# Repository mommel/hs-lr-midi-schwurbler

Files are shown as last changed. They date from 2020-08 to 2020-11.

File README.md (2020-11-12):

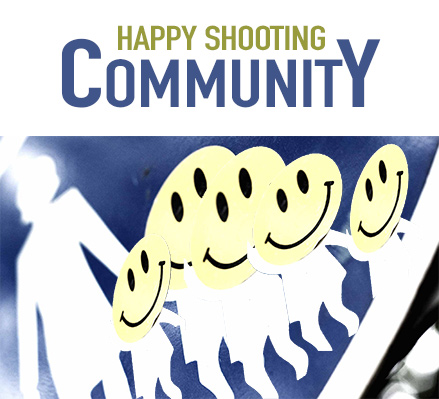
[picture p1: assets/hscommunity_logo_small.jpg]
HSCommunity Logo

# Der Schwurbler



Happy Shooting Community - DIY Lightroom Hardware Controller
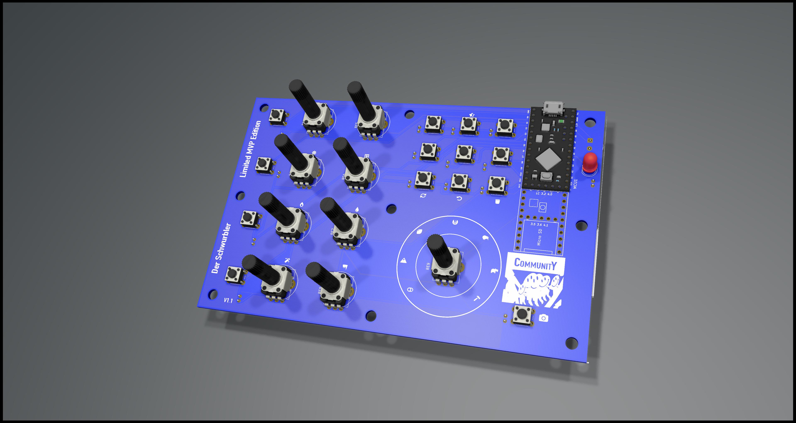
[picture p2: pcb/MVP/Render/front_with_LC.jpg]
Render with Parts


## Description
The german foto podcast legend Happy Shooting had a discussion about Midi controller for Lightroom. One comment on the website and voila a new project is born.
This project will (hopefully) contain everything from zero to hero to get create your own customized Midi Controller for Lightroom.
It is completly community driven, so everyone is allowed to contribute. And it's not intended to earn money with it. Just from the community for the community.
In general you might even need no case, just the pcb with the solded parts. so you will get an extra small extra lightwight device. If that's the thing for you we might even go the capacitive way and reduce the soldered components and weight to a minimum.

## MVP Video

<object width="425" height="350">
  <param name="movie" value="https://youtu.be/SjJDIjGQ-qA" />
  <param name="wmode" value="transparent" />
  <embed src="https://youtu.be/SjJDIjGQ-qA"
         type="application/x-shockwave-flash"
         wmode="transparent" width="425" height="350" />
</object>

https://youtu.be/SjJDIjGQ-qA

## WIKI
You can find our wiki here https://github.com/mommel/hs-lr-midi-schwurbler/wiki

## Status of the project
Released a version and onging development for next versions

### Tutorial
 *To be found soonish in the Wiki*

## Versions
### MVP 
* based on Teensy 32bit boards
* USB Powered
* 10 + 4 Buttons
* 9 Poti

[BOM](https://hs-lr-midi-schwurbler.mommel.com/bom/schwurbler-mvp-1.2.ibom.html)

## Releases
* [MVP Version](https://github.com/mommel/hs-lr-midi-schwurbler/releases/tag/v1.0.0) released

## Help needed? F.A.Q.
* For support you can open an issue here on github.
* Maybe there will be a slack contact in the future.
* This project is a Happy Shooting _Community_ Project. 
The best way to get help is joining the #der-schwurbler channel on the happyshooting slack. The community will do it's best and hopefully solve your issue.
* No hotline, no helpdesk. But we have something even greater: The Happy Shooting _Community_.    

## How to contribute
* Fork, add, push, create a pull request
* create an issue on github
* You don't want to use Eagle, Kicad or Fritzing to create a layout. It's totally fine, as long the result can be used to create a PCB with no additional costs to the version created with the other software.

## How can I get one?
* Decide the version, take the Gerber Folder and bom.csv matching your decission. Upload the gerber Files to the manufacturer of your most trust. Mine are some even in china and even there is the delivery time below a week.

## License
* All layouts and diagrams are CC share alike non commercial attribution 4.0 licensed
So you can create and use them on your own even in your company, but you are not allowed to sell them.

<br />Dieses Werk ist lizenziert unter einer <a rel="license" href="http://creativecommons.org/licenses/by-nc-sa/4.0/">Creative Commons Namensnennung - Nicht-kommerziell - Weitergabe unter gleichen Bedingungen 4.0 International Lizenz</a>.
Namensnennung/Attribution to Happy Shooting Community https://happyshooting.de/community-projekte/

### Contributors in alphabetical order
chrismarquardt https://github.com/chrismarquardt
Mac ThreeZee https://github.com/MacThreeZee
Mommel https://github.com/mommel
Vielpixel https://github.com/Vielpixel
wolfgangSF https://github.com/wolfgangSF

### 3rd Party
Tools or Assets from 3rd party have their own LICENSE attached to their folder

## Disclaimer
THE SOFTWARE IS PROVIDED "AS IS", WITHOUT WARRANTY OF ANY KIND, EXPRESS OR IMPLIED, INCLUDING BUT NOT LIMITED TO THE WARRANTIES OF MERCHANTABILITY, FITNESS FOR A PARTICULAR PURPOSE AND NONINFRINGEMENT. IN NO EVENT SHALL THE AUTHORS OR COPYRIGHT HOLDERS BE LIABLE FOR ANY CLAIM, DAMAGES OR OTHER LIABILITY, WHETHER IN AN ACTION OF CONTRACT, TORT OR OTHERWISE, ARISING FROM, OUT OF OR IN CONNECTION WITH THE SOFTWARE OR THE USE OR OTHER DEALINGS IN THE SOFTWARE.

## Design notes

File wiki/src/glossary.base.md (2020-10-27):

<!---------------------------->
<!-- multilangual suffix: en, de  -->
<!---------------------------->
<!-- [en] -->
# Glossary
<!-- [de] -->
# Glossar
<!-- [common] -->

## BOM
<!-- [en] -->
Bill of materials, it is more or less the list which items you need to create a board
<!-- [de] -->
Eine Auflistung der benötigten Bauteile 
<!-- [common] -->

## MCU
<!-- [en] -->
The mcu is shorthand for microcontroller unit. When we speak of the mcu, we mostly mean a dev board. 
* Teensy is a dev board. 
* Esp32 is the chip itself but we mostly use it as synonym for the devboards with esp32-wroom chip like (TTGO, NodeMCU ESP32, ...)
<!-- [de] -->
Eigentlich der Mikrokontroller, aber wir verwenden der Einfachheit halber den Begriff für das jeweilige Entwicklerplatine (Devboard). Da wir im aktuellen Prozess immer ein Devboard nutzen werden. 
* Der Teensy ist ein Devboard. 
* Der Esp32 hingegen ist bezeichnet eigentlich den Chip aber wir nutzen ihn als Synonym für ein Devboard mit esp32-wroom Chip z.B. dem TTGO oder dem NodeMCU ESP32
<!-- [common] -->

## Midi2LR
<!-- [en] -->
MIDI2LR is a software application to translate the Schwurbler input to Lightroom actions.   
[https://github.com/rsjaffe/MIDI2LR](https://github.com/rsjaffe/MIDI2LR)
<!-- [de] -->
MIDI2LR ist eine Software-Anwendung zur Übersetzung der Schwurbler-Eingabe in Lightroom-Aktionen.   
[https://github.com/rsjaffe/MIDI2LR](https://github.com/rsjaffe/MIDI2LR)
<!-- [common] -->

## MVP
<!-- [en] -->
Minimal Valuable Product - This is a first working prototype.
<!-- [de] -->
Minimal Valuable Product - 
Es handelt sich um einen ersten funktionsfähigen Prototyp. 
<!-- [common] -->

## PCB
<!-- [en] -->
It is a Printed Circuit Board. The board where everything gets soldered onto. We use only through the hole soldering items to keep it beginner save. At least for the first board designs. You might want to have a look in this nice [guide how to solder right by Mitch Altmann, Andie Nordgren and Jeff Keyzer from mightyohm.com](http://mightyohm.com/files/soldercomic/FullSolderComic_EN.pdf)
<!-- [de] -->
Die Leiterplatte auf der wir alle Bauteile im verlöten werden. Hierbei werden wir ( zumindest in den ersten Versionen) Durchsteckbauelemente verwenden, da das SMD Löten für Anfänger nicht gerade Ideal ist. 
Als Lötneuling möchtest du vielleicht mal in diese super [Anleitung wie man richtig lötet (gemacht von Mitch Altmann, Andie Nordgren, Jeff Keyzer, Alexander Bodora und Richard Meinsen zu finden auf der Webseite mightyohm.com)](http://mightyohm.com/files/soldercomic/translations/DE_SolderComic.pdf) schauen
<!-- [common] -->

## Potentiometer
<!-- [en] -->
A potentiometer is an electrical resistance component whose resistance values can be changed mechanically (by turning or shifting). There are linear potentiometers (faders or sliders) and rotary potentiometers.
<!-- [de] -->
Ein Potentiometer (kurz Poti), ist ein elektrisches Widerstandsbauelement, dessen Widerstandswerte mechanisch (durch Drehen oder Verschieben) veränderbar sind. Es gibt Linear Poti (auch Fader oder Schieberegler genannt) und Rotary Poti.
<!-- [common] -->

<!-- [en] -->
## Rotary Encoder
A rotary encoder is a type of position sensor which is used for determining the angular position of a rotating shaft. It generates an electrical signal, either analog or digital, according to the rotational movement. Details can be found here: https://howtomechatronics.com/tutorials/arduino/rotary-encoder-works-use-arduino/
<!-- [de] -->
## Rotary Encoder oder Drehwinkelgeber
Ein Rotary Encoder ist eine Art Positionssensor, der zur Bestimmung der Winkelposition einer rotierenden Welle verwendet wird. Er erzeugt ein elektrisches Signal, entweder analog oder digital, entsprechend der Drehbewegung. Mehr Details gibt's hier: https://howtomechatronics.com/tutorials/arduino/rotary-encoder-works-use-arduino/ 
<!-- [common] -->

## Teensy
<!-- [en] -->
The Teensy is a USB-based microcontroller development system.    
[> PJRC Website](https://www.pjrc.com/teensy/)
<!-- [de] -->
Der Teensy ist ein Development Board mit vielen Funktionen in einem sehr kleinen Paket.    
[> Teensy First Use](https://www.pjrc.com/teensy/first_use.html)   

***
<!-- [de] -->
_[ > English Version](glossary.en.md)_
<!-- [en] -->
_[ > Deutsche Version](glossary.de.md)_

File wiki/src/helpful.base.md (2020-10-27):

<!---------------------------->
<!-- multilangual suffix: en, de  -->
<!---------------------------->

<!-- [en] -->
# Helpful Informations
<!-- [de] -->
# Hilfreiche Informationen
<!-- [common] -->

<!-- [en] -->
## Adobe Lightroom Classic Shortcuts:
[Adobe Lightroom Classic Shortcuts](https://helpx.adobe.com/de/lightroom-classic/help/keyboard-shortcuts.html)
<!-- [de] -->
## Klassische Kurzbefehle für Adobe Lightroom:
[Klassische Kurzbefehle für Adobe Lightroom](https://helpx.adobe.com/de/lightroom-classic/help/keyboard-shortcuts.html)
<!-- [common] -->

<!-- [en] -->
## Sources of supply for the components
<!-- [de] -->
## Bezugsquellen für die Bauteile
<!-- [common] -->
(Deutschland/Europa)
* https://www.reichelt.de
* https://www.antratek.de
* https://www.az-delivery.de
* https://www.conrad.de
* https://www.mouser.de
* https://wittko.eu
* https://eckstein-shop.de

## Midi2LR
[Project Page](https://rsjaffe.github.io/MIDI2LR/)

## Solder Comic
<!-- [en] -->
by Mitch Altmann, Andie Nordgren and Jeff Keyzer 
- [Soldering is easy](http://mightyohm.com/files/soldercomic/FullSolderComic_EN.pdf)
Hosted on mightyohm.com
<!-- [de] -->
von Mitch Altmann, Andie Nordgren, Jeff Keyzer und in deutsch kommen Alexander Bodora und Richard Meinsen en top
- [Löten ist einfach](http://mightyohm.com/files/soldercomic/translations/DE_SolderComic.pdf)
Gehostet auf mightyohm.com
<!-- [common] -->

## Teensy USB Development Board
<!-- [en] -->
The Teensy is a complete USB-based microcontroller development system, in a very small footprint, capable of implementing many types of projects. All programming is done via the USB port.    
[> PJRC Website](https://www.pjrc.com/teensy/)     
[> Teensy First Use](https://www.pjrc.com/teensy/first_use.html)  
<!-- [de] -->
Der Teensy ist ein vollständiges USB-basiertes Mikrocontroller-Entwicklungssystem mit sehr geringem Platzbedarf, das viele Arten von Projekten umsetzen kann. Die gesamte Programmierung erfolgt über den USB-Port.    
[> PJRC Website](https://www.pjrc.com/teensy/)     
[> Teensy First Use](https://www.pjrc.com/teensy/first_use.html)  

***
<!-- [de] -->
_[ > English Version](helpful.en.md)_
<!-- [en] -->
_[ > Deutsche Version](helpful.de.md)_

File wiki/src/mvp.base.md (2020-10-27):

<!---------------------------->
<!-- multilangual suffix: en, de  -->
<!---------------------------->
<!-- [en] -->
# Schwurbler MVP Edition
<!-- [de] -->
# Der Schwurbler MVP Version
<!-- [common] -->

**Release Package**    
[> Download Release Package](https://github.com/mommel/hs-lr-midi-schwurbler/releases/tag/v1.0.0)

**Quickstart Guide**
<!-- [en] -->
[> Download Quickstart Guide - PDF](https://github.com/mommel/hs-lr-midi-schwurbler/blob/master/quickstartguide/MVP/de/Der%20Schwurbler%20MVP%20-%20Schnellstart.pdf)
<!-- [de] -->
[> Download Quickstart Guide - PDF](https://github.com/mommel/hs-lr-midi-schwurbler/blob/master/quickstartguide/MVP/de/Der%20Schwurbler%20MVP%20-%20Schnellstart.pdf)
<!-- [common] -->

<!-- [en] -->
[> Download Fix for the Rev 1.1 PCB - PDF](https://github.com/mommel/hs-lr-midi-schwurbler/blob/master/quickstartguide/MVP/SchwurbelFix-MVP1.1.pdf)
<!-- [de] -->     
[> Download Fix für die Rev 1.1 Platine - PDF](https://github.com/mommel/hs-lr-midi-schwurbler/blob/master/quickstartguide/MVP/SchwurbelFix-MVP1.1.pdf)
<!-- [common] -->

**BOM**    
[> Download BOM - PDF](https://github.com/mommel/hs-lr-midi-schwurbler/blob/master/bom/MVP/bom.pdf)   

**Midi2LR Profile für Lightroom 10**    
[> Download](https://github.com/mommel/hs-lr-midi-schwurbler/blob/master/midi2lr-profiles/MVP/Der%20Schwurbler%20MVP%20-%20Midi2LR%20Profiles%20v2.zip)

<!-- [en] -->
<!-- [de] -->
<!-- [common] -->

-----------    
<!-- [en] -->
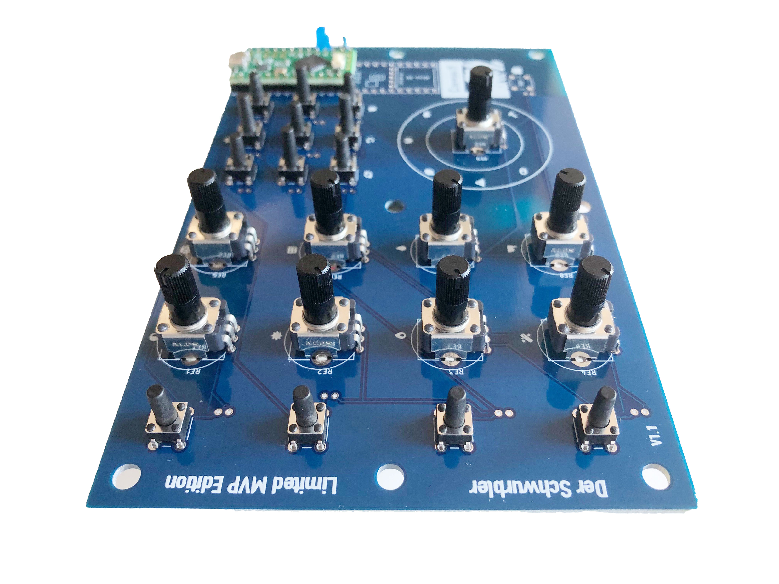
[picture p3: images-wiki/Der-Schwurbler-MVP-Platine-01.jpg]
The Schwurbler MVP PCB

<!-- [de] -->
Die bestückte Schwurbler MVP Platine
<!-- [common] -->

<!-- [en] -->
**BOM for the Schwurbler MVP version**  

1x Circuit Board - MVP Limited Edition -- 
(Gerber.zip is included in the Release Package)

1x TEENSY LC (Teensy 3.2 or 4.1 boards are also compatible.) -- 
[Sample](https://www.antratek.de/teensy-lc)     

2x Pin Headers ( straight, optional)

2x Female Connectors (optional for pluggable version)  

9x Rotary Potentiometer, mono, 10 kOhm, linear (height depending on housing) -- 
[Sample](https://www.reichelt.de/drehpotentiometer-mono-10-kohm-linear-6-mm-rk09k113-lin10k-p73815.html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)     

14x Micro Buttons 6x6mm, 12V, vertical (height depending on housing) -- 
[Sample](https://www.reichelt.de/kurzhubtaster-6x6mm-hoehe-4-3mm-12v-vertikal-taster-3301-p27892.html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)      
   
1x LED 5mm (optional)    

1x resistor for LED 470 Ohm (optional)
<!-- [de] -->
**BOM für die Pre-Release Version**  

1x Platine - MVP Limited Edition -- 
(Gerber.zip ist im Release Paket enthalten)

1x TEENSY LC (Teensy 3.2 oder 4.1 Boards sind auch kompatible.) -- 
[Muster](https://www.antratek.de/teensy-lc)     

2x Stiftleisten gerade (optional)

2x Buchsenleisten (optional für steckbare Version)  

9x Drehpotentiometer, Mono, 10 kOhm, linear (Höhe je nach Gehäuse) -- 
[Muster](https://www.reichelt.de/drehpotentiometer-mono-10-kohm-linear-6-mm-rk09k113-lin10k-p73815.html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)     

14x Kurzhubtaster 6x6mm, 12V, vertikal (Höhe je nach Gehäuse) -- 
[Muster](https://www.reichelt.de/kurzhubtaster-6x6mm-hoehe-4-3mm-12v-vertikal-taster-3301-p27892.html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)      
   
1x LED 5mm (optional)    

1x Widerstand für LED 470 Ohm (optional)     
<!-- [common] -->
     
.

<!-- [en] -->
**Required Software**
<!-- [de] -->     
**Erforderliche Software**  
<!-- [common] -->

Teensy First Use -- [Installing the Teensy Loader](https://www.pjrc.com/teensy/first_use.html)   

Schwurbler MVP Firmware -- [Download](https://github.com/mommel/hs-lr-midi-schwurbler/releases/tag/v1.0.0)    

MIDI2LR Software --
[Download](https://github.com/rsjaffe/MIDI2LR)   

Midi2LR Profile -- 
[Download](https://github.com/mommel/hs-lr-midi-schwurbler/tree/master/midi2lr-profiles/MVP)     

<!-- [en] -->
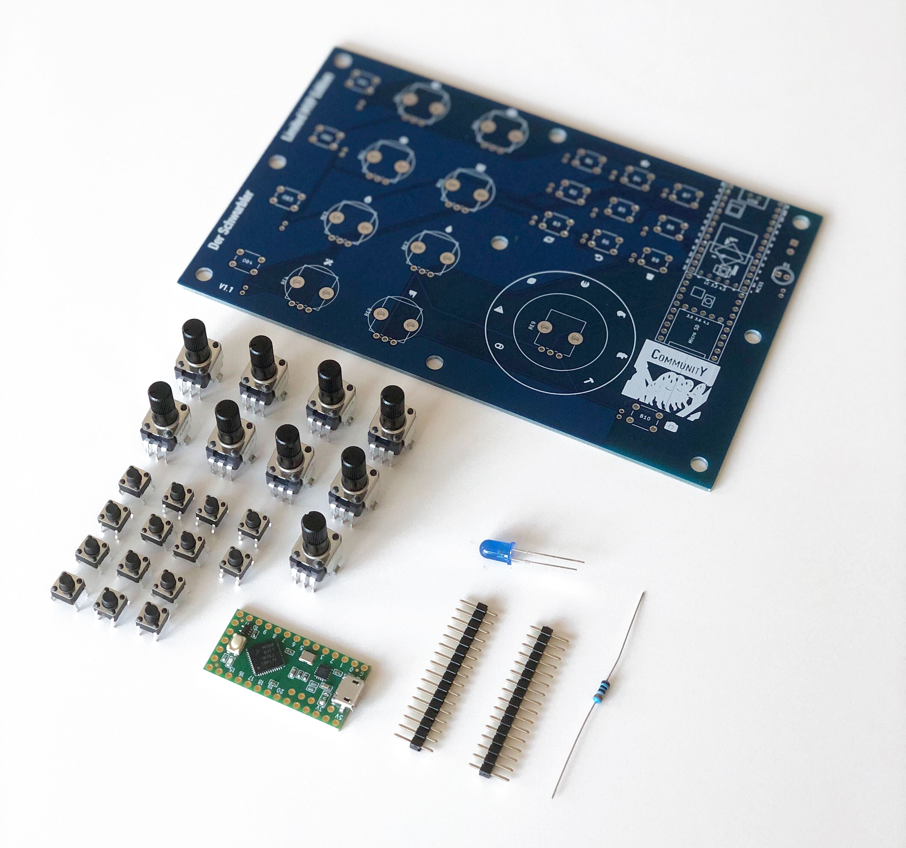
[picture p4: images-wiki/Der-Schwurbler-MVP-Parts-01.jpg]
Parts for the Schwurbler MVP Limited Edition

<!-- [de] -->     
Teile für den Schwurbler MVP Limited Edition  
<!-- [common] -->

<!-- [en] -->
**The Schwurbler MVP in its 3d-Printed Case**  

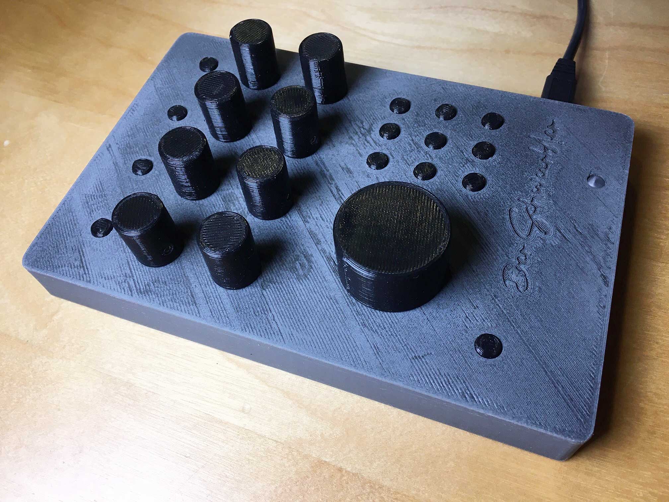
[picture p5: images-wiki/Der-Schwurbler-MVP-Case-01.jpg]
The Schwurbler MVP in its 3d-Printed Case

<!-- [de] -->     
**Der Schwurbler MVP im 3d-Druck Gehäuse**  

Der Schwurbler MVP im 3d-Druck Gehäuse
<!-- [common] -->

***

***    

<!-- [en] -->
# ... and this is how it all started:    

## First suggestions for the MVP version

**Functionality:**  

* Selection per Quickbutton (Modes)
* Color by Quickbutton (Modes)
* Zoom in/out by extra potentiometer
* Mode/controller mapping change via Quickbuttons (modes) or via Rotary + Mode display
* Adhoc development via Quickbutton (modes)
* Add a display to show the current mode?
* Reset quick actions by additional button

**Survey results on the number and type of controllers:**
* Rotary potentiometer vs. rotary encoder -- 1/1 (2 answers)
* Buttons -- 12 (Unanimously 3 answers)
* Slider -- none / 8/2 / abstentions (4 answers)
* Knob -- 0/4/8/12 (4 answers)
* Case -- none/3D Case/Wood/Plexiglas (4 answers)

***

## First design suggestions

Prototype 1 and 2 (3D renderings)  
[https://github.com/mommel/hs-lr-midi-schwurbler/blob/master/design-drafts/schwurbler_v1.png](https://github.com/mommel/hs-lr-midi-schwurbler/blob/master/design-drafts/schwurbler_v1.png)  
[https://github.com/mommel/hs-lr-midi-schwurbler/blob/master/design-drafts/schwurbler_ii_v2.jpg](https://github.com/mommel/hs-lr-midi-schwurbler/blob/master/design-drafts/schwurbler_ii_v2.jpg)

Schwurbler MTC   
https://github.com/mommel/hs-lr-midi-schwurbler/blob/design-drafts/design-drafts/SchwurblerV1.png

Schwurbler R1  
https://github.com/mommel/hs-lr-midi-schwurbler/blob/master/design-drafts/Interface-Schwurbler-R1.png

Schwurbler R2   
https://github.com/mommel/hs-lr-midi-schwurbler/blob/master/design-drafts/Interface-Schwurbler-R2.png

 ... Fader Version ...

Schwurbler F1   
https://github.com/mommel/hs-lr-midi-schwurbler/blob/master/design-drafts/Interface-Schwurbler-F1.png

Schwurbler F2   
https://github.com/mommel/hs-lr-midi-schwurbler/blob/master/design-drafts/Interface-Schwurbler-F2.png

 ... the X series ...

Schwurbler X1  
https://github.com/mommel/hs-lr-midi-schwurbler/blob/master/design-drafts/Interface-Schwurbler-X1.png

Schwurbler X2   
https://github.com/mommel/hs-lr-midi-schwurbler/blob/master/design-drafts/Interface-Schwurbler-X2.png

**Survey results on design:**

* Schwurbler X1 - 1 vote
* Schwurbler X2 - 3 votes

***
<!-- [de] -->   
# ... und so hat alles angefangen:    

## Erste Vorschläge für die MVP Version

**Funktionalität:**  

* Bewertung per Quickbutton (Modi)
* Farbe per Quickbutton (Modi)
* Ein/Auszoomen per extra  Poti
* Mode/ReglerMapping Change per Quickbuttons (Modi) oder per Rotary + Mode Anzeige
* Adhoc Entwickeln per Quickbutton (modi)
* Ein Display hinzufügen um den aktuellen Modus anzuzeigen?
* Zuücksetzen von Schnellaktionen per zusätzlichem Button

**Umfrageergebnisse zur Zahl und Art der Regler:**
* Drehpoti vs Drehwinkelgeber -- 1/1 (2 Antworten)
* Knöpfe -- 12  (Einstimmig 3 Antworten)
* Schieberegler -- keine/8/2/Enthaltungen (4 Antworten)
* Drehregler -- 0/4/8/12 (4 Antworten)
* Case -- keins/3D Case/Holz/Plexiglas (4 Antworten)

***

## Erste Designvorschläge

Prototype 1 und 2 (3D Renderings)  
[https://github.com/mommel/hs-lr-midi-schwurbler/blob/master/design-drafts/schwurbler_v1.png](https://github.com/mommel/hs-lr-midi-schwurbler/blob/master/design-drafts/schwurbler_v1.png)  
[https://github.com/mommel/hs-lr-midi-schwurbler/blob/master/design-drafts/schwurbler_ii_v2.jpg](https://github.com/mommel/hs-lr-midi-schwurbler/blob/master/design-drafts/schwurbler_ii_v2.jpg)

Schwurbler MTC   
https://github.com/mommel/hs-lr-midi-schwurbler/blob/design-drafts/design-drafts/SchwurblerV1.png

Schwurbler R1  
https://github.com/mommel/hs-lr-midi-schwurbler/blob/master/design-drafts/Interface-Schwurbler-R1.png

Schwurbler R2   
https://github.com/mommel/hs-lr-midi-schwurbler/blob/master/design-drafts/Interface-Schwurbler-R2.png

 … Fader Version …

Schwurbler F1   
https://github.com/mommel/hs-lr-midi-schwurbler/blob/master/design-drafts/Interface-Schwurbler-F1.png

Schwurbler F2   
https://github.com/mommel/hs-lr-midi-schwurbler/blob/master/design-drafts/Interface-Schwurbler-F2.png

 … die X Serie …

Schwurbler X1  
https://github.com/mommel/hs-lr-midi-schwurbler/blob/master/design-drafts/Interface-Schwurbler-X1.png

Schwurbler X2   
https://github.com/mommel/hs-lr-midi-schwurbler/blob/master/design-drafts/Interface-Schwurbler-X2.png

**Umfrageergebnisse zum Design:**

* Schwurbler X1 - 1 Stimme
* Schwurbler X2 - 3 Stimmen

***
<!-- [common] --> 

<!-- [en] -->
## Layout of the MVP version

8 rotary knobs with 4 buttons each  
1 keypad with 9 keys   
1 Central control knob  
1 button for selecting the assignment mode of the control elements

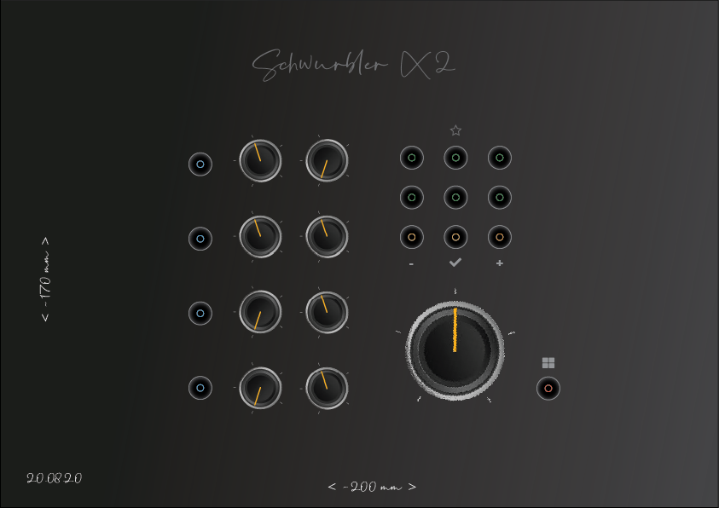
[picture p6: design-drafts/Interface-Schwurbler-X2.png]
Interface Layout - Schwurbler X2


PCB Rendering - Schwurbler X2

On the board you have the option to solder all buttons and potis as external elements. Additionally there are connectors for a status LED. And, if the analog potentiometers have disturbances, capacitors can be added for current smoothing.

## Tutorial 01 - Assembly
(http://www.youtube.com/watch?v=eH0KHRkc_u4 "Tutorial 01 - Mounting")

## Housing prototype 01
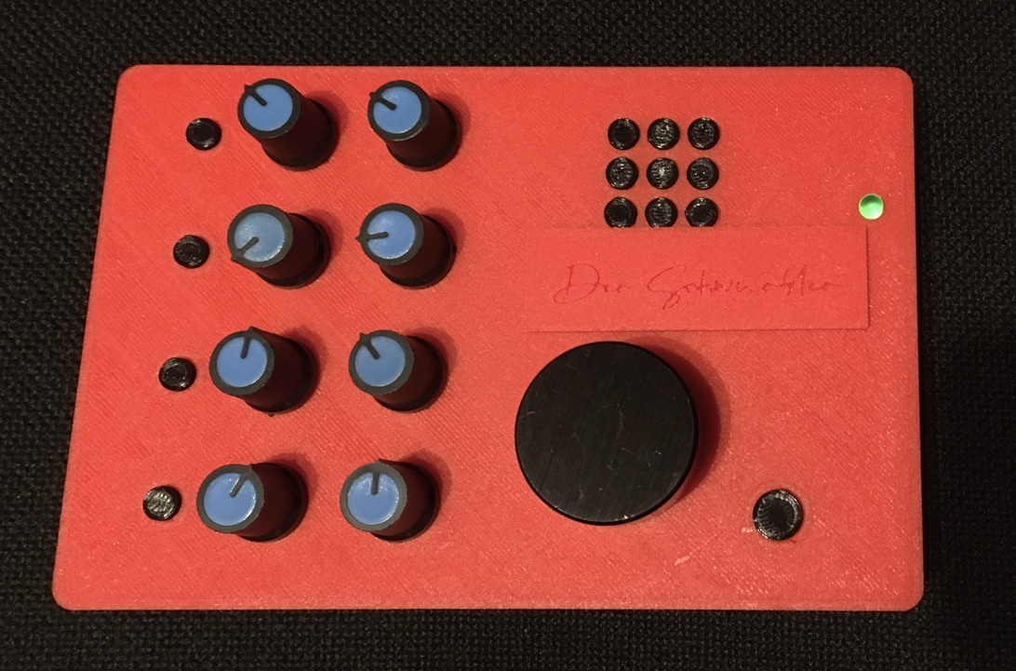
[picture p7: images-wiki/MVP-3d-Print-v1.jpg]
First 3d-Print for a housing


## Housing prototype 02
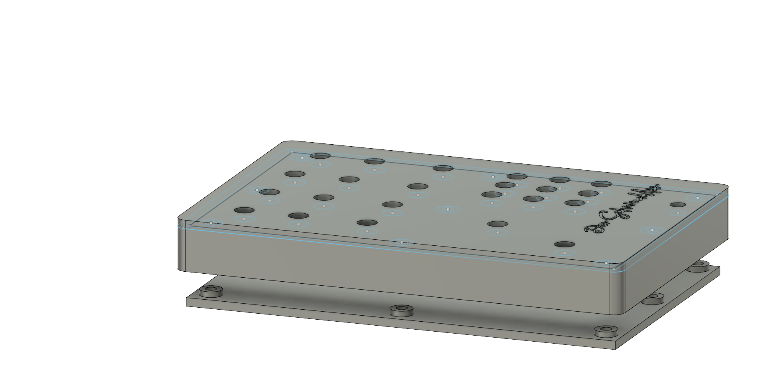
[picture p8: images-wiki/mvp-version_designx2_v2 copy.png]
The Schwurbler Housing Prototype - Rendering

<!-- [de] --> 
## Layout der MVP Version

8 Drehregler mit je 4 Tastern  
1 Tastenblock mit 9 Tasten   
1 Zentraler Drehregler  
1 Taster zur Auswahl des Belegungs-Modus der Bedienelemente
  
Interface Layout - Schwurbler X2

PCB Rendering - Schwurbler X2

Auf der Platine besteht optional die Möglichkeit alle Buttons und Poti als externe Elemente ein zu löten. Zusätzlich gibt es Anschlüsse für eine Status LED. Und, falls die analogen Potis Störungen haben können Kodensatoren zur Stromglättung hinzugefügt werden.

## Tutorial 01 - Bestückung
(http://www.youtube.com/watch?v=eH0KHRkc_u4 "Tutorial 01 - Bestückung")

## Gehäuse Prototyp 01
Erster 3d-Print für ein Gehäuse

## Gehäuse Prototyp 02
Gehäuse Prototyp - Rendering
<!-- [common] --> 

***

<!-- [de] -->
_[ > English Version](mvp.en.md)_
<!-- [en] -->
_[ > Deutsche Version](mvp.de.md)_

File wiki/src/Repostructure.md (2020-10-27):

# What to put where
* Bomfiles in _BOM_
* Wiring Scheme in _circuit-diagram_
* Arduino Ino or VSCode C in _code_
* Kicad Projects in _kicad_
* Eagle Projects in _eagle_
* Gerber, Etching, PCB Renders in _pcb_
* Fritzing wiring diagrams in _prototyping_

### All of those folders have subfolders
* First subfolder defines the MCU the board is based on
* Second Boardname -  best practice "connection type"-"mcu"-"special interest"

* General Assets for readme.md  in_assets_
 
# Scripts
actually there is only the board.sh a really shitty shellscript file to get started with some git changes (far from useable, just to get some help for totally git noobs) but it can generate a skeleton for a new board

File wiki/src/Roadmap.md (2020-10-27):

Done:
Der Schwurbler MVP

Next Milestones:
*  SchwurblAir - ESP32 based wireless Version
*  Schwurbler360 - Schwurbler with rotary Encoders instead of poti

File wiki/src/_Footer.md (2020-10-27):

 Der Schwurbler - Logo

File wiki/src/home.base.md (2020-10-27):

<!---------------------------->
<!-- multilangual suffix: en, de  -->
<!---------------------------->

<!-- [en] -->
# Welcome to the Schwurbler Wiki!
<!-- [de] -->
# Willkommen im Happy Shooting Schwurbler Wiki!
<!-- [common] -->

<!-- [en] -->
**The Schwurbler** - a self-made MIDI controller for Lightroom. Launched by Manuel, this HS-Community project provides you with everything you need to create your own custom-made MIDI controller for Lightroom. Schematics, board layouts, settings for Midi2LR. It's all open source and everyone is invited to contribute. Sign up for the HS-Slack channel #der-schwurbler and participate. 
<!-- [de] -->
**Der Schwurbler** – ein Selbstbau-MIDI-Controller für Lightroom. Von Manuel ins Leben gerufen, dieses HS-Community-Projekt stellt euch alles zur Verfügung, um euren eigenen, maßgeschneiderten Midi-Controller für Lightroom zu erstellen. Schaltpläne, Platinenlayouts, Settings für Midi2LR. Das Ganze ist Open Source und alle sind eingeladen, dazu beizutragen. Im HS-Slack Kanal #der-schwurbler an melden und mitmachen.
<!-- [common] -->

<!-- [en] -->
A special thanks to the following members of the HS-Slack Channel #der-schwurbler for their active participation and time to make the MIDI-Controller for Lightroom a reality.
<!-- [de] -->
Ein besonderer Dank gilt den folgenden Mitgliedern des HS-Slack Channel #der-schwurbler für ihre aktive Teilnahme und ihre Zeit, um den MIDI-Controller für Lightroom Wirklichkeit werden zu lassen.
<!-- [common] -->

@Animefan
@chrismarquardt
@Christian T. Guenther
@iKnorry
@Mac ThreeZee,
@Markus-P
@mommel
@nicktaler
@TheBrainless
@vielpixel
@Wolfgang

***

<!-- [en] -->
**Happy Shooting** - the podcast about photography   
[https://happyshooting.de](https://happyshooting.de)
<!-- [en] -->
**Happy Shooting** - der Podcast zum Thema Fotografie   
[https://happyshooting.de](https://happyshooting.de)
<!-- [common] -->

**HS-Slack**   
https://happyshooting.de/der-hs-slack/

***
<!-- [de] -->
_[ > English Version](home.en.md)_
<!-- [en] -->
_[ > Deutsche Version](home.de.md)_

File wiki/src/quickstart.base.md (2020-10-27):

<!---------------------------->
<!-- multilangual suffix: en, de  -->
<!---------------------------->

<!-- [en] -->
# Quickstart Guide - MVP Version
<!-- [de] -->
# Schnellstartanleitung - MVP Version
<!-- [common] -->

<!-- [en] -->
[> Download PDF Version](https://github.com/mommel/hs-lr-midi-schwurbler/blob/master/quickstartguide/MVP/en/Schwurbler_MVP-Quickstartguide.pdf)    

[> Download Fix for the Rev 1.1 PCB - PDF](https://github.com/mommel/hs-lr-midi-schwurbler/blob/master/quickstartguide/MVP/SchwurbelFix-MVP1.1.pdf)

***

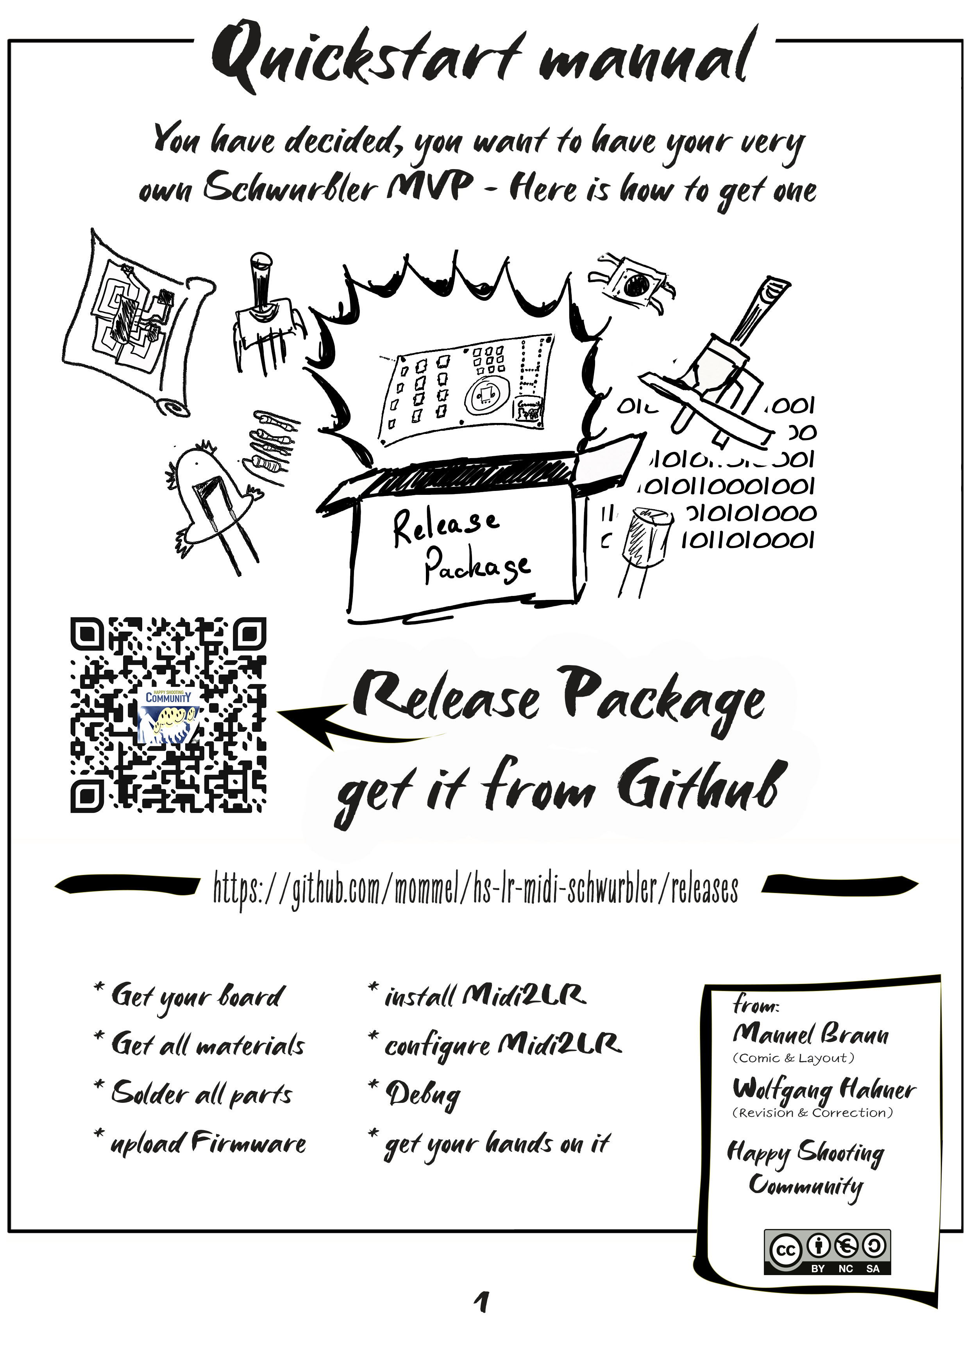
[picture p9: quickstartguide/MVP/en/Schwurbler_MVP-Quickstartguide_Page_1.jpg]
Schnellstart_Seite_1


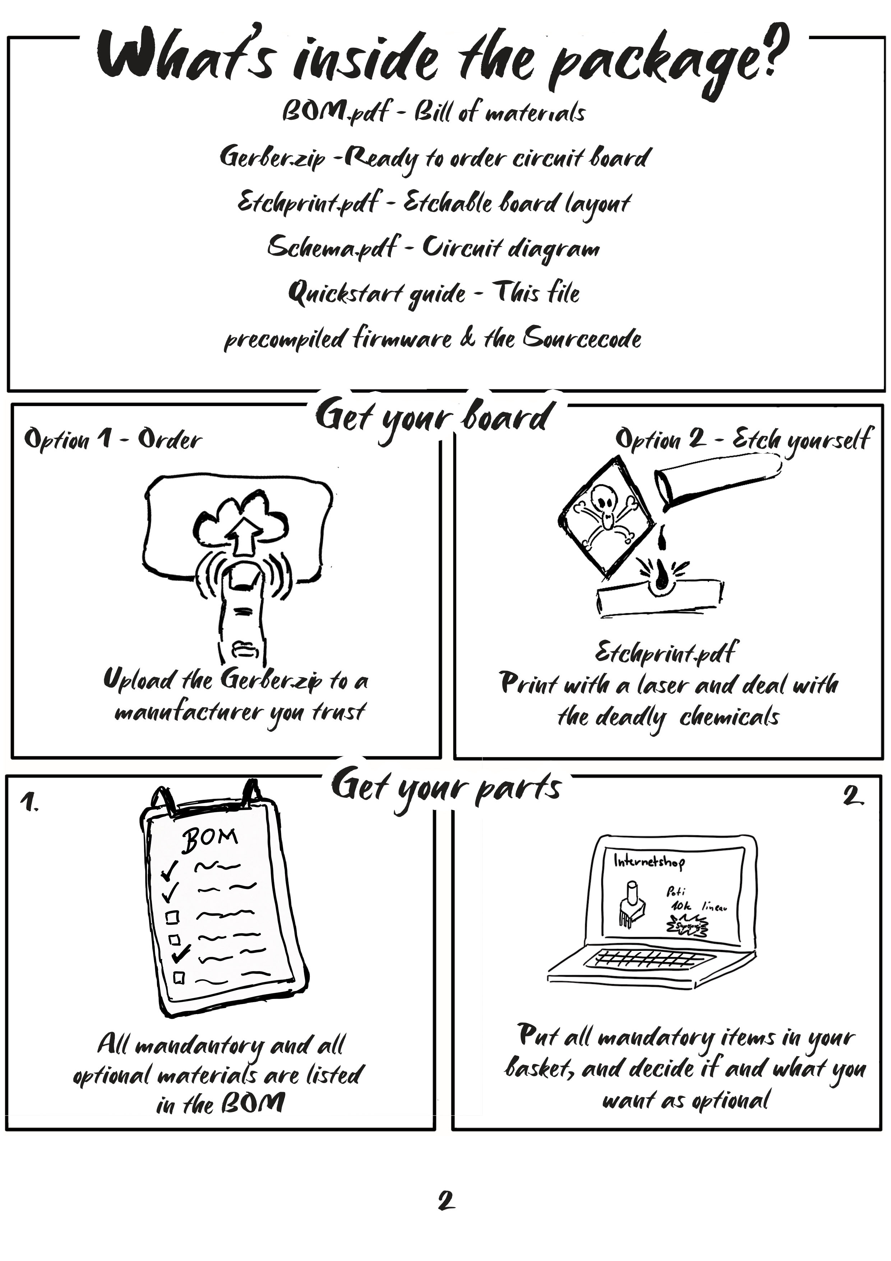
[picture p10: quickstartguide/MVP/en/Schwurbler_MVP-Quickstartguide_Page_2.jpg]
Schnellstart_Seite_2


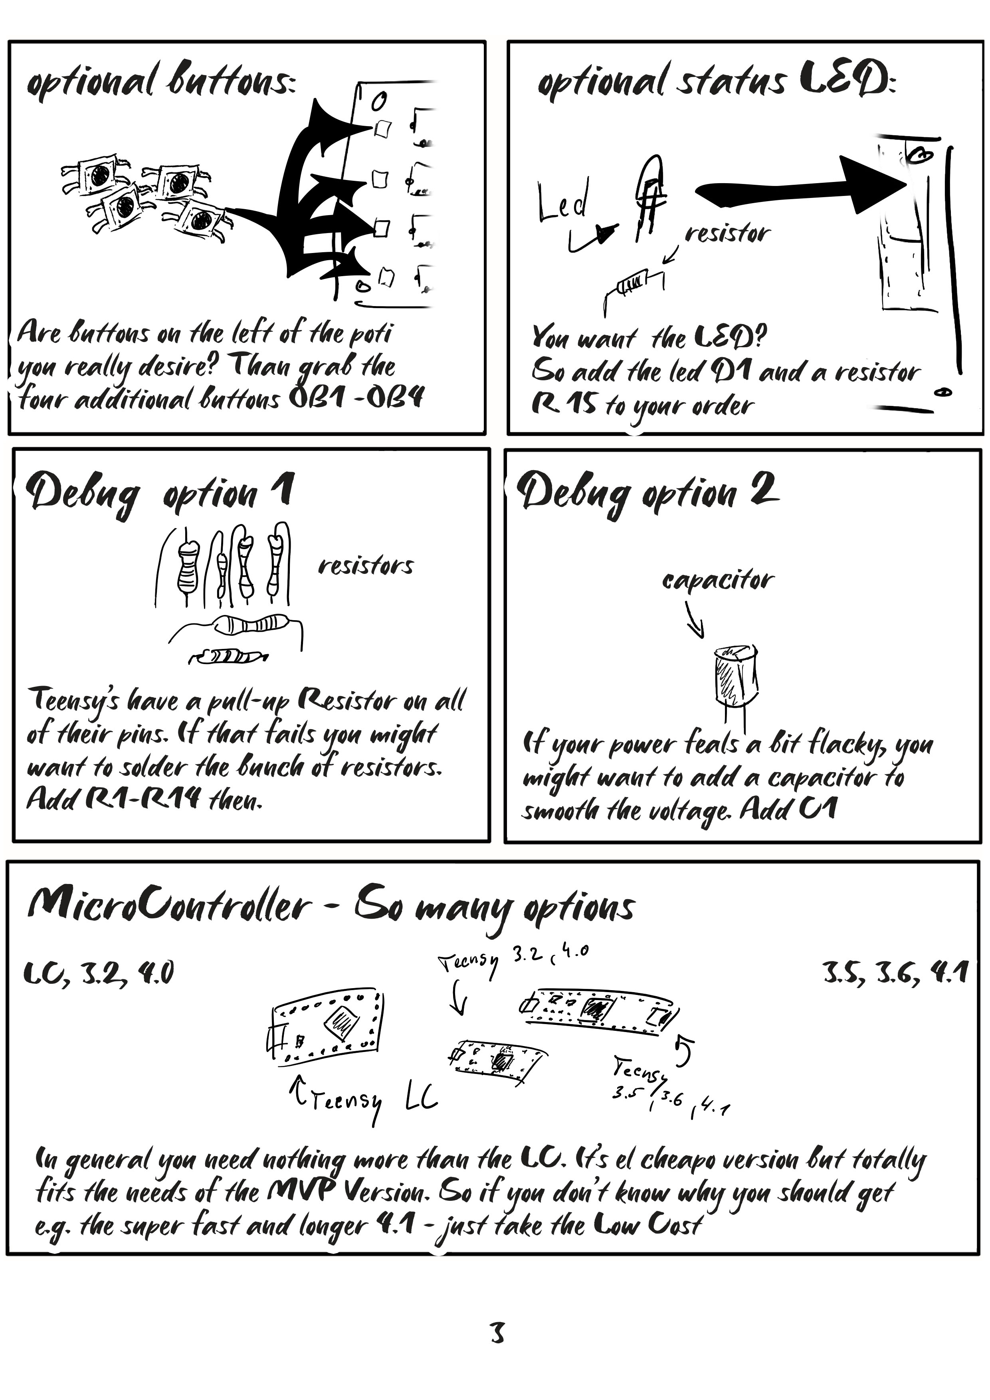
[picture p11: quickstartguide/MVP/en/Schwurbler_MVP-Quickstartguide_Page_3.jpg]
Schnellstart_Seite_3


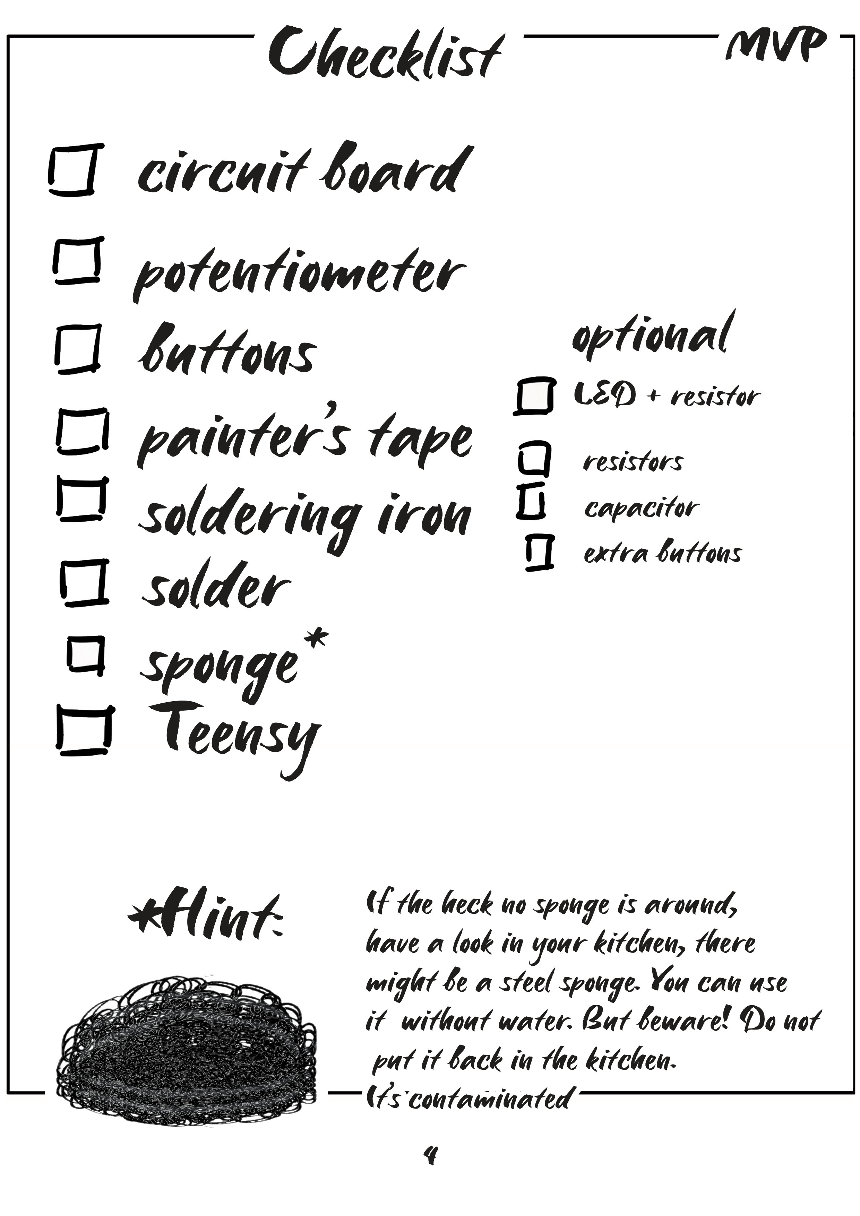
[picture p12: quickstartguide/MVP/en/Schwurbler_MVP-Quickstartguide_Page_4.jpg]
Schnellstart_Seite_4


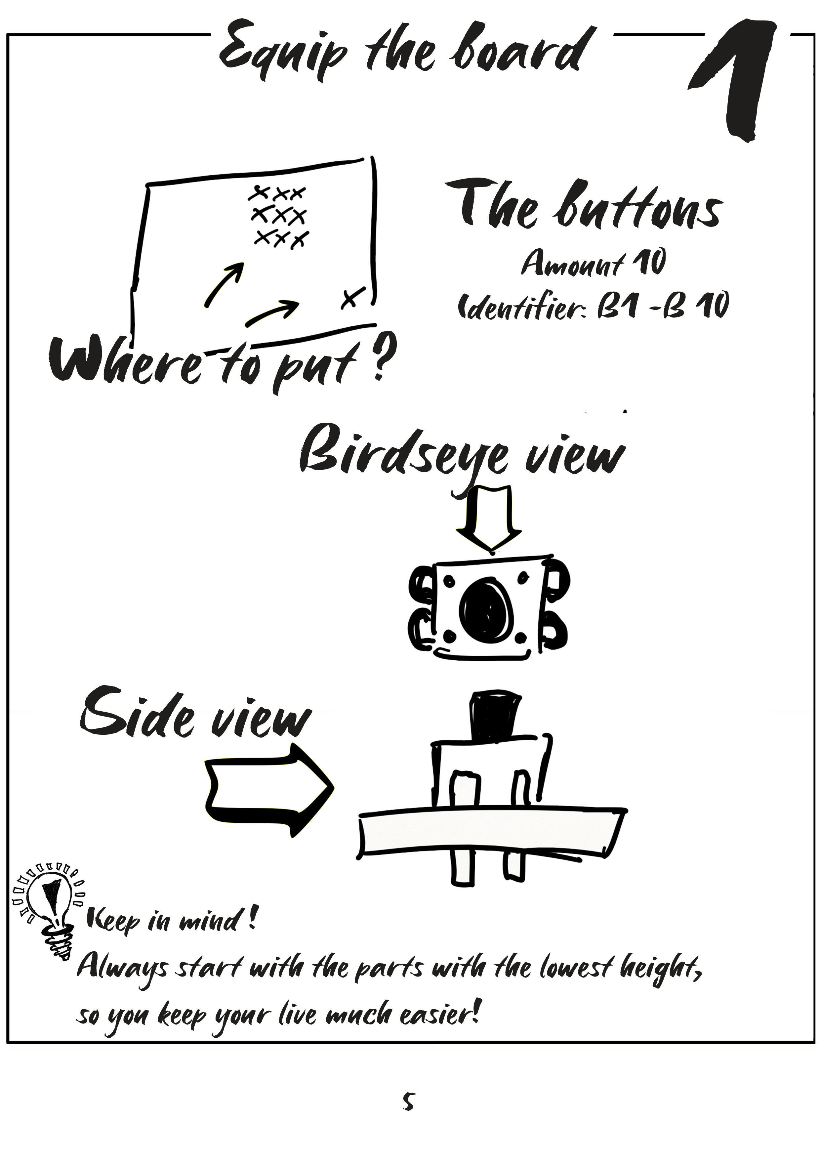
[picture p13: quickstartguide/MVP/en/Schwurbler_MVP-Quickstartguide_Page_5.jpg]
Schnellstart_Seite_5


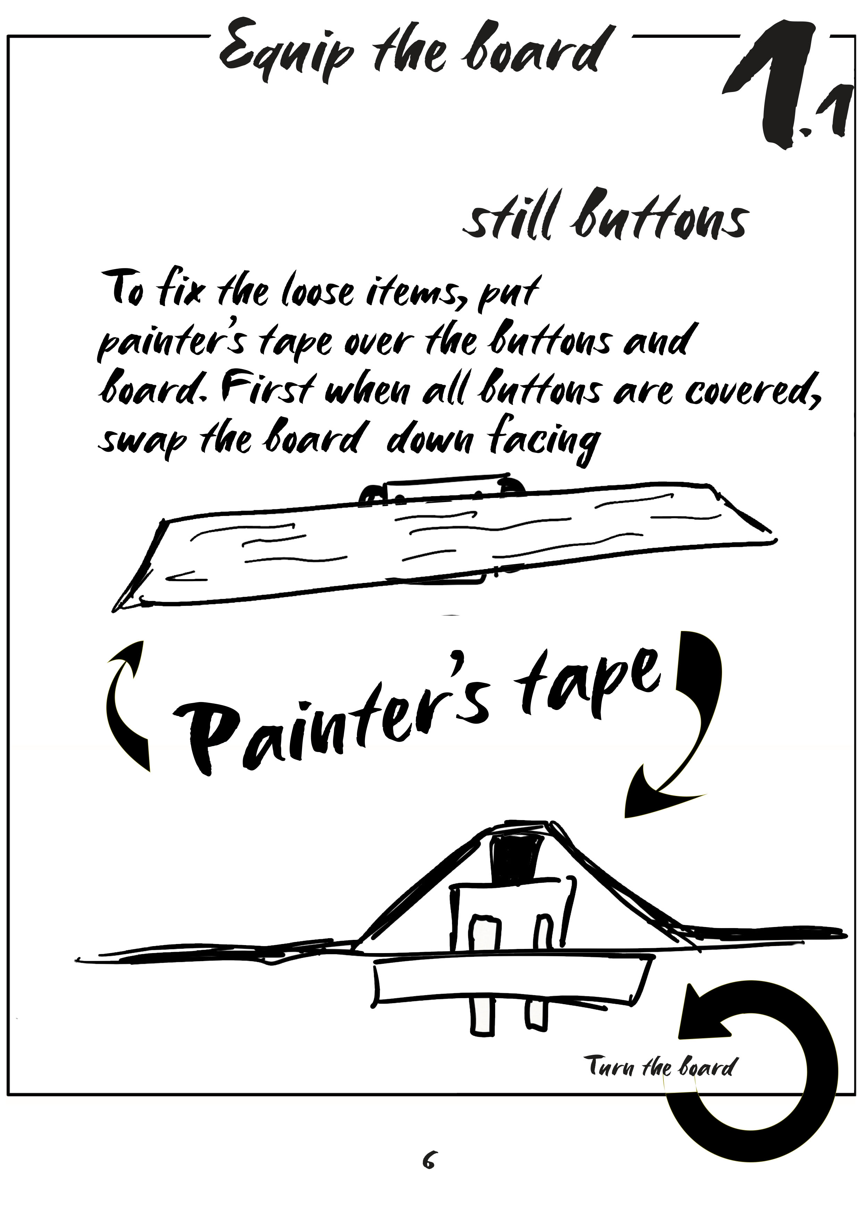
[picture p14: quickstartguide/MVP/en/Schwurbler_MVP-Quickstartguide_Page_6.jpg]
Schnellstart_Seite_6


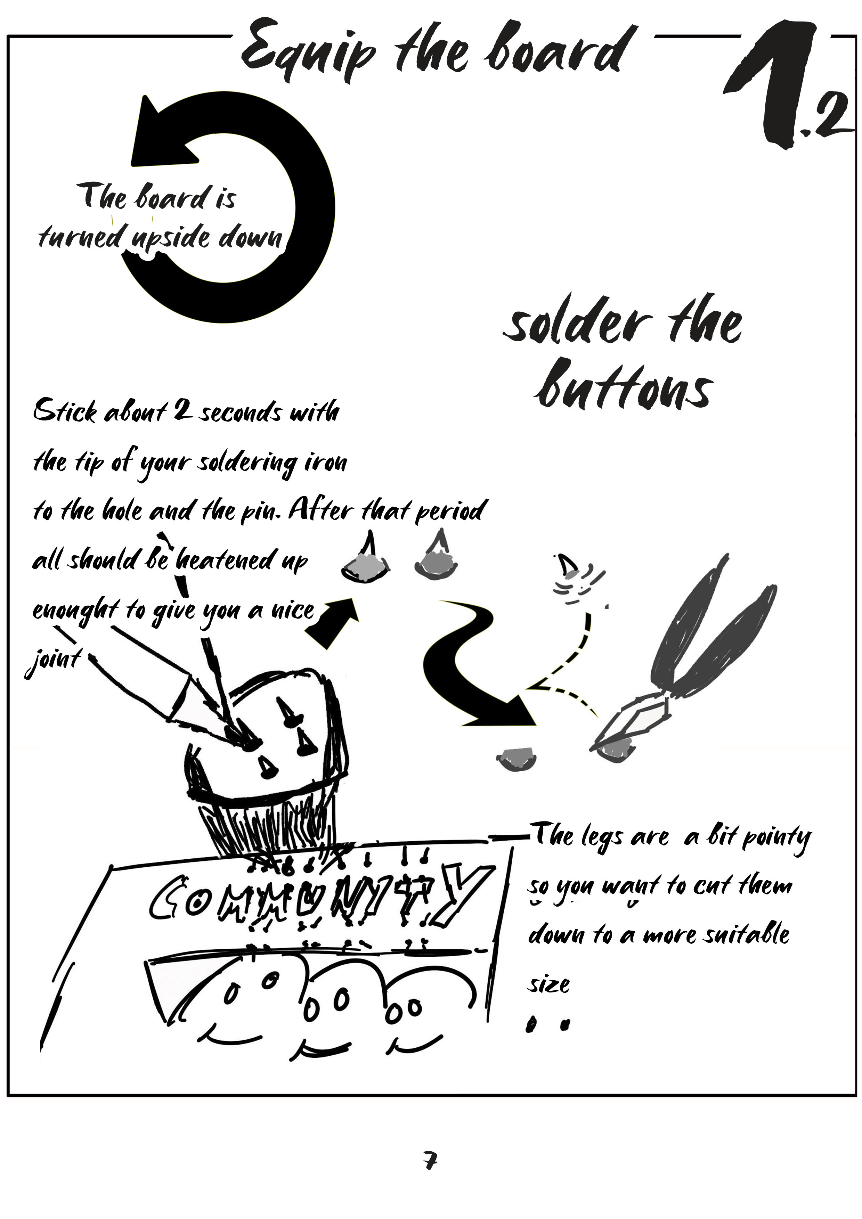
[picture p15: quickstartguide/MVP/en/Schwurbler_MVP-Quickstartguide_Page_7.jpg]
Schnellstart_Seite_7


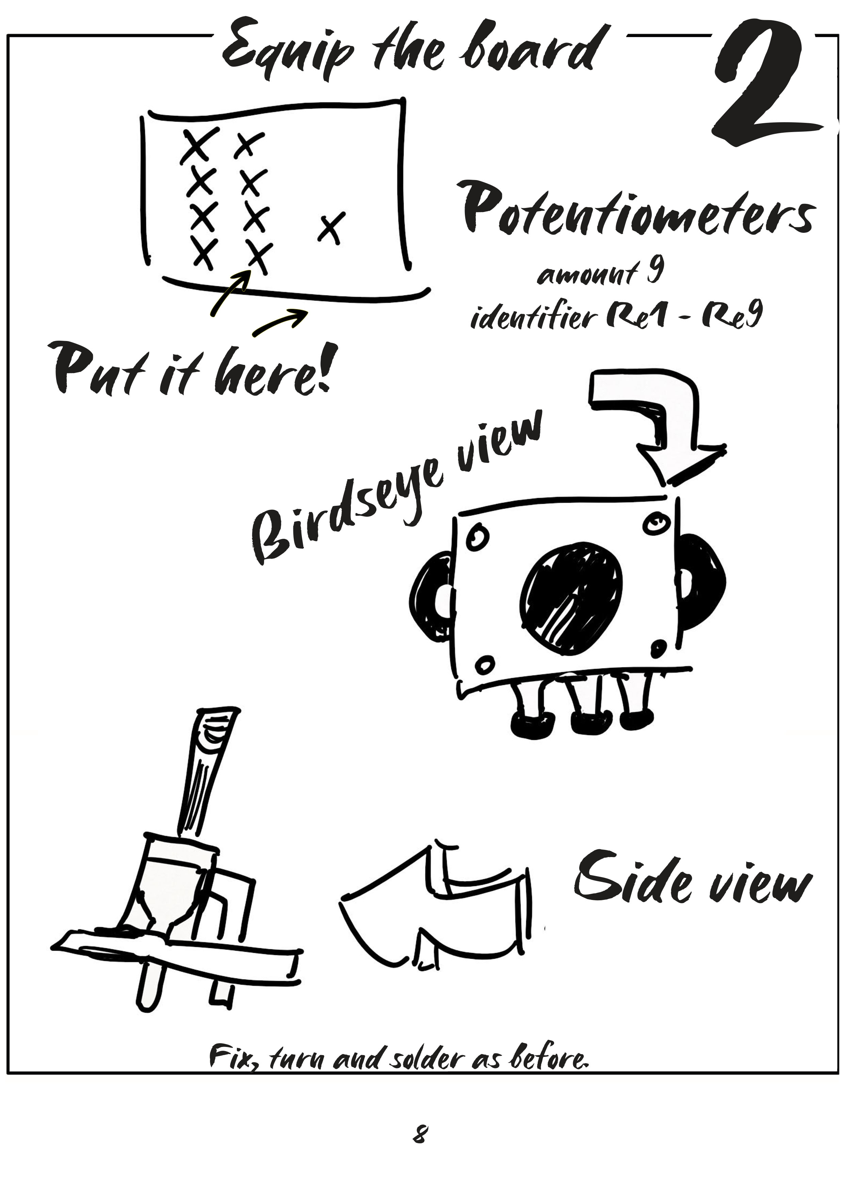
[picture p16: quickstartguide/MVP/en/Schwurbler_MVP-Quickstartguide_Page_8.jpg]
Schnellstart_Seite_8


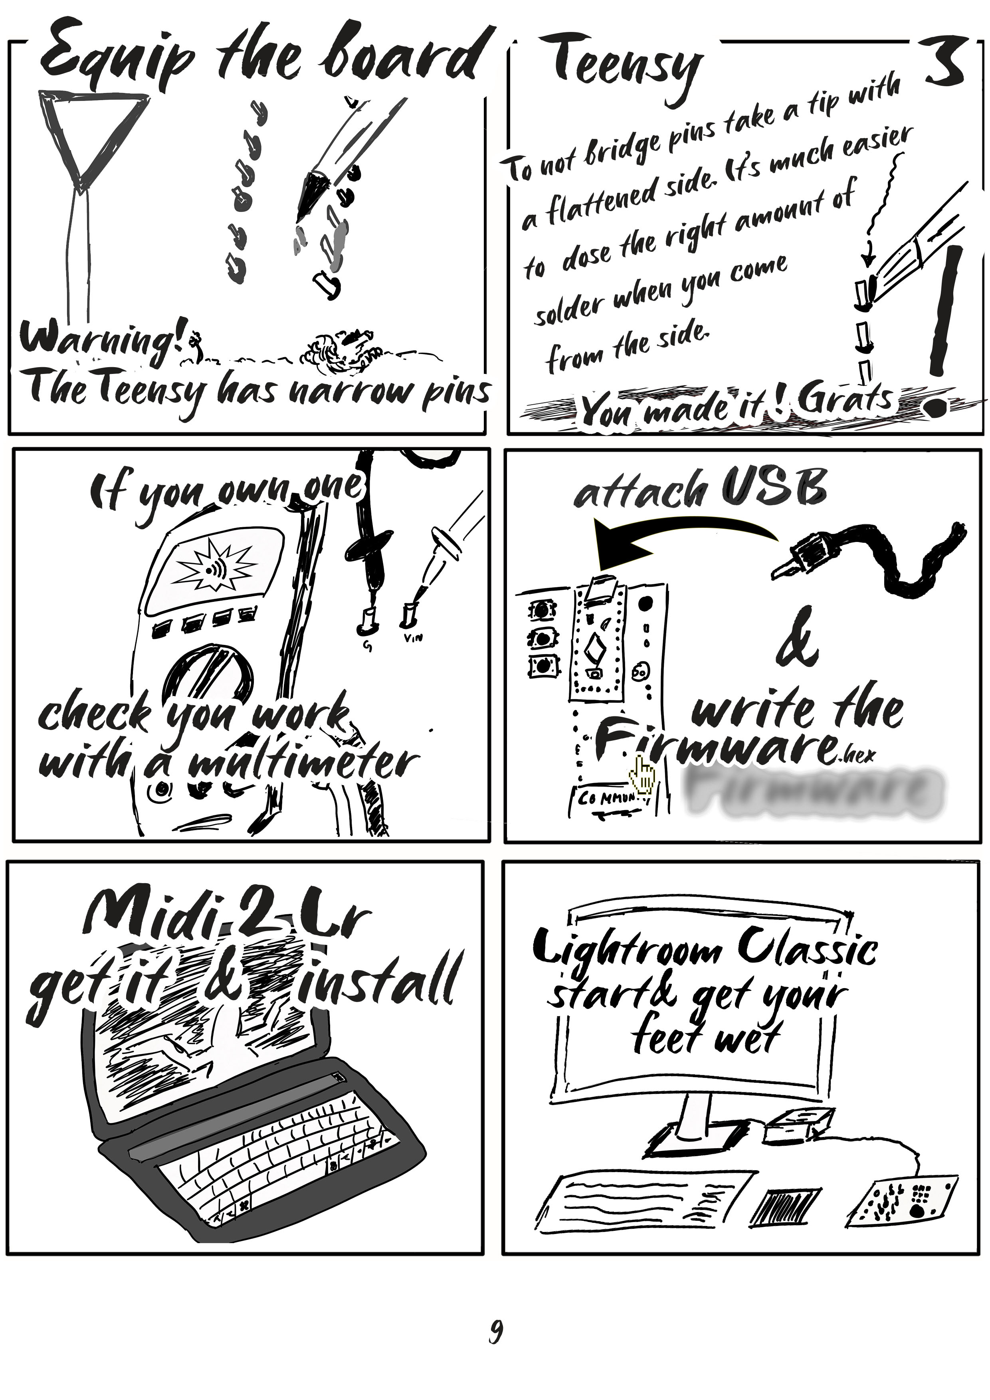
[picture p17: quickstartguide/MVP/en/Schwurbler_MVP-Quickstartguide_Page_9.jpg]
Schnellstart_Seite_9

<!-- [ignore] -->

<!-- [de] -->
[> Download PDF Version](https://github.com/mommel/hs-lr-midi-schwurbler/blob/master/quickstartguide/MVP/en/Schwurbler_MVP-Quickstartguide.pdf)    

[> Download Fix for the Rev 1.1 PCB - PDF](https://github.com/mommel/hs-lr-midi-schwurbler/blob/master/quickstartguide/MVP/SchwurbelFix-MVP1.1.pdf)

***

Schnellstart_Seite_1

Schnellstart_Seite_2

Schnellstart_Seite_3

Schnellstart_Seite_4

Schnellstart_Seite_5

Schnellstart_Seite_6

Schnellstart_Seite_7

Schnellstart_Seite_8

Schnellstart_Seite_9

***
<!-- [common] -->

***

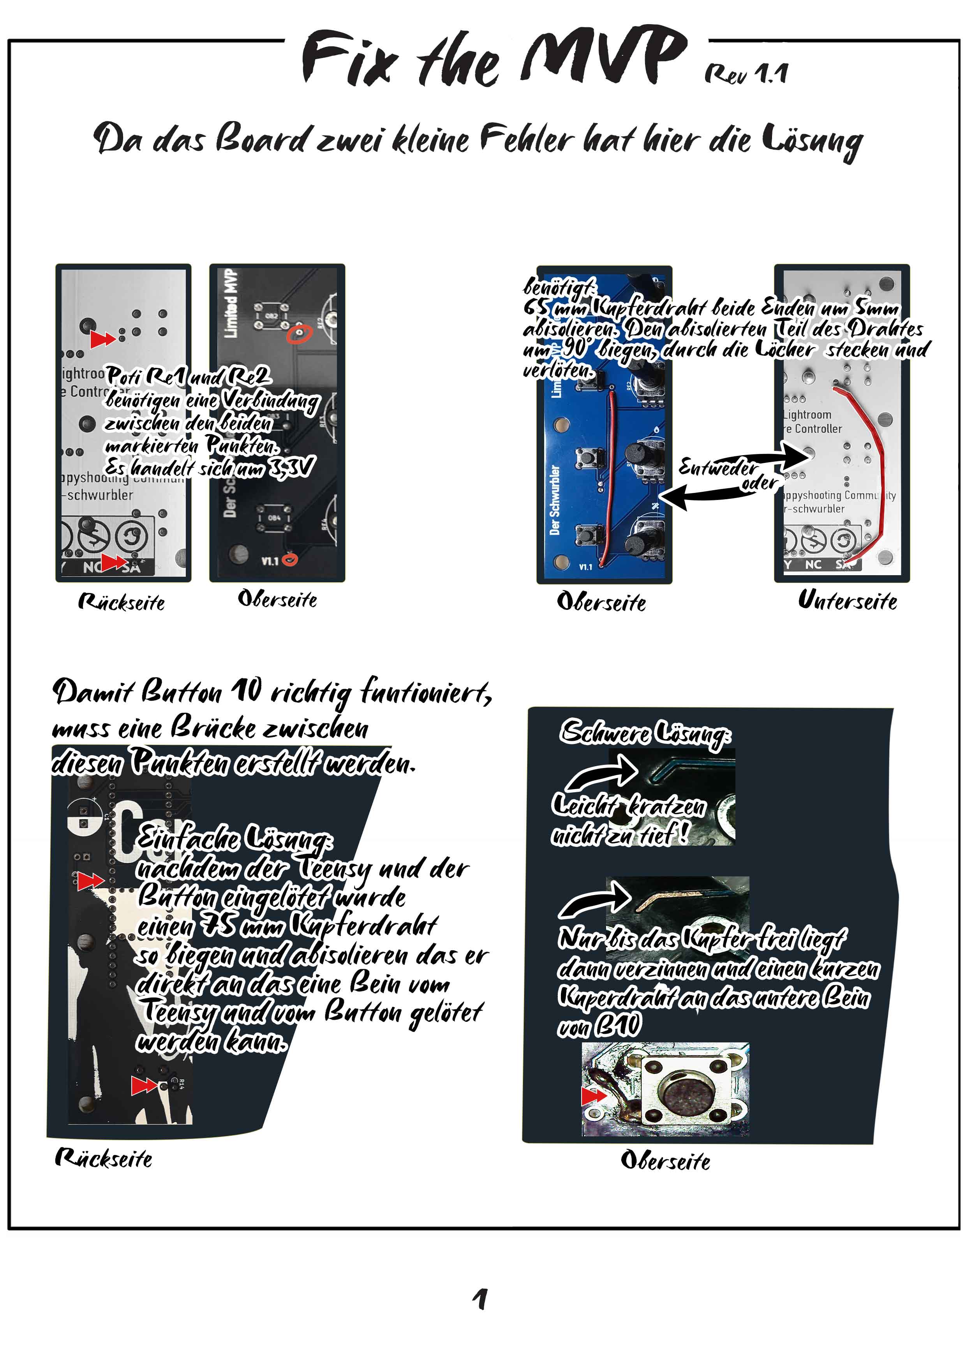
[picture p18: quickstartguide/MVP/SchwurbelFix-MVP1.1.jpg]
Fix PCB Beta Release


***
<!-- [en] -->
# Quickstart Guide - MVP Version
[> Download PDF Version](https://github.com/mommel/hs-lr-midi-schwurbler/blob/master/quickstartguide/MVP/en/Schwurbler_MVP-Quickstartguide.pdf) 

[> Download Fix for the Rev 1.1 PCB - PDF](https://github.com/mommel/hs-lr-midi-schwurbler/blob/master/quickstartguide/MVP/SchwurbelFix-MVP1.1.pdf)
<!-- [de] -->
# Schnellstartanleitung - MVP Version
[> Download PDF Version](https://github.com/mommel/hs-lr-midi-schwurbler/blob/master/quickstartguide/MVP/de/Der%20Schwurbler%20MVP%20-%20Schnellstart.pdf)   

[> Download Fix für die Rev 1.1 Platine - PDF](https://github.com/mommel/hs-lr-midi-schwurbler/blob/master/quickstartguide/MVP/SchwurbelFix-MVP1.1.pdf)
<!-- [common] -->
***

## Tutorials
[> Tutorials](https://github.com/mommel/hs-lr-midi-schwurbler/wiki/Tutorials) 

***

<!-- [de] -->
_[ > English Version](quickstart.en.md)_
<!-- [en] -->
_[ > Deutsche Version](quickstart.de.md)_

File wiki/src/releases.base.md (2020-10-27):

<!---------------------------->
<!-- multilangual suffix: en, de  -->
<!---------------------------->
<!-- [en] -->
# Releases
<!-- [de] -->
# Veröffentlichungen
<!-- [common] -->
September 13, 2020     
[The Schwurbler MVP v1.0.0](https://github.com/mommel/hs-lr-midi-schwurbler/releases/tag/v1.0.0)

***
<!-- [de] -->
_[ > English Version](releases.en.md)_
<!-- [en] -->
_[ > Deutsche Version](releases.de.md)_

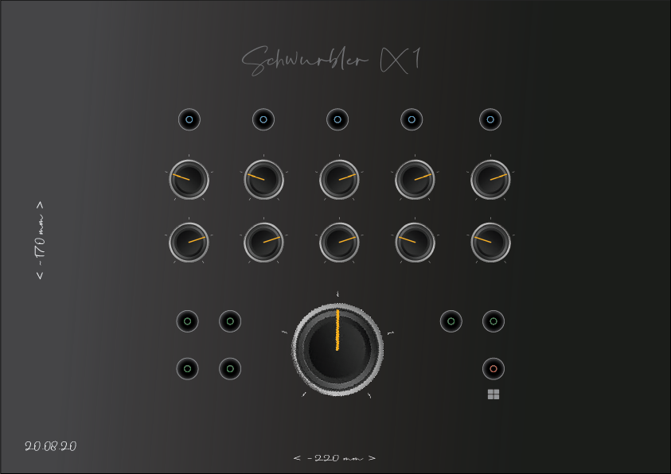
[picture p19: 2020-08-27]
design-drafts/Interface-Schwurbler-X1.png

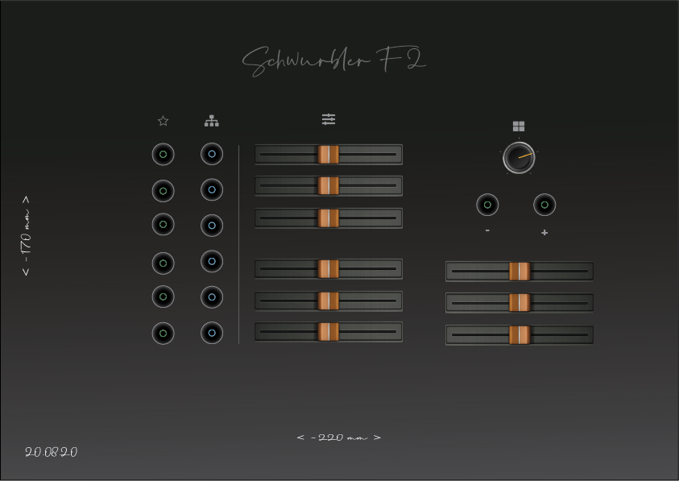
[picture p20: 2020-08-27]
design-drafts/Interface-Schwurbler-F2.png

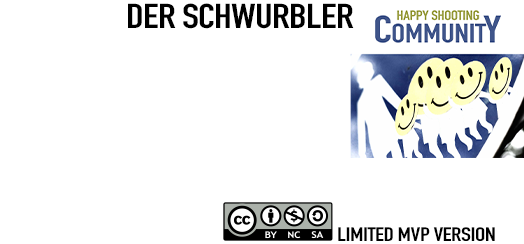
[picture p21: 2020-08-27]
kicad/MVP/mvpdesign.bmp

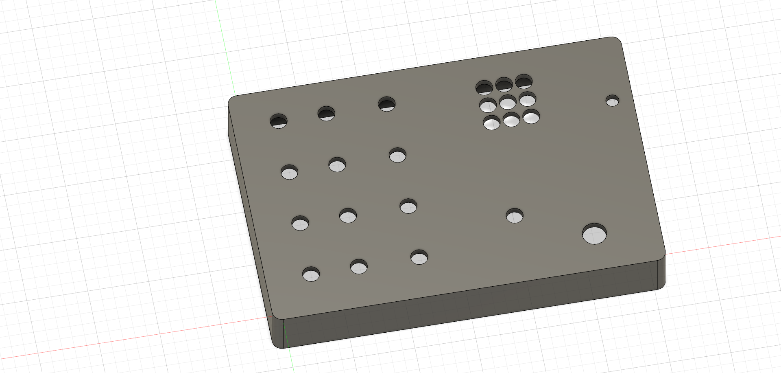
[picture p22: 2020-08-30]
images-wiki/MVP-Version_DesignX2 v3.png

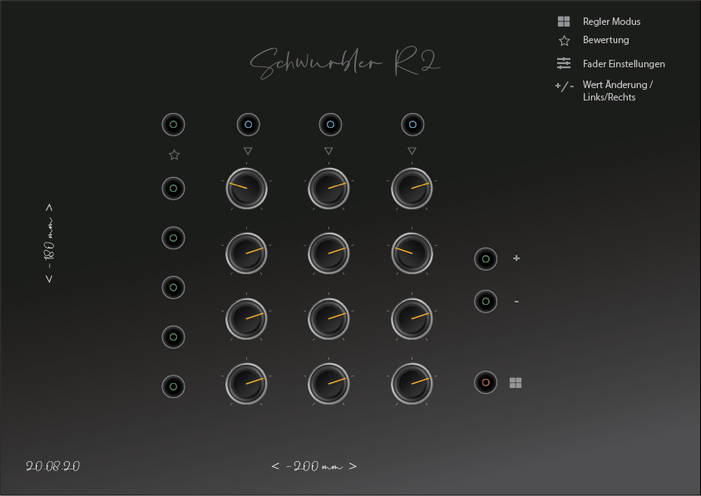
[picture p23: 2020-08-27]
design-drafts/Interface-Schwurbler-R2.png

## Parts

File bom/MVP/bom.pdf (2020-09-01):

### Bill of material

Name | Value | Manufacturer | MPN | Reichelt | Aliexpress | Mouser | QTY
B1-B10 | 6mm Tactical Momentary Switch 5mm | | | TASTER 3301 | 6x6mm Panel PCB Momentary Tactile Takt Mini Push Button Switch DIP 4pin | 506-1977223-6 | 10
RE1-RE9 | 10k Ohm | Alps | RK09K1130A0H | RK09K113-LIN10K | RK09 | 688-RK09K1130A70 | 9
MCU | LC or 3.2 | PJRC | Teensy LC / 3.2 | | | | 1
R15 | 470 Ohm | Any | Resistor THT | VIS PR0100010473
D1 | 5mm LED | Any | LED | LED 5MM BL
C1 | -

Optional 4 Buttons

OB1-OB4 | TASTER 3301 | 6x6mm Panel PCB Momentary Tactile Takt Mini Push Button Switch DIP 4pin | 506-1977223-6 | 4

Optional Items
R1-R14 | 10k Ohm | Any | Resistor THT | VIS PR0100010105 | 14

1

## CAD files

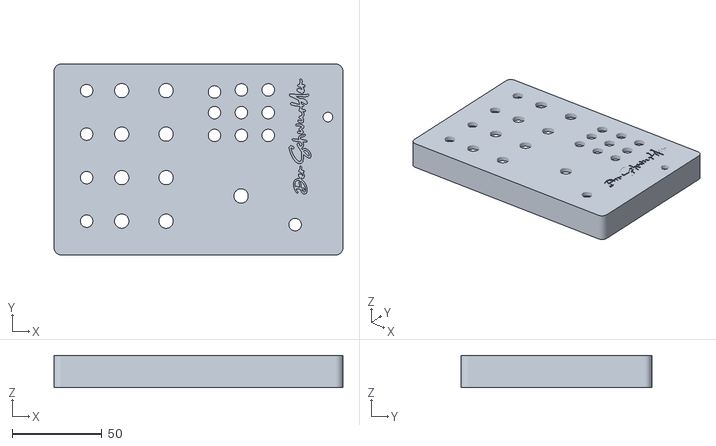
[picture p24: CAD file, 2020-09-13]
3d-prints/MVP/Topcase.stl
161.3 x 106.5 x 18.0

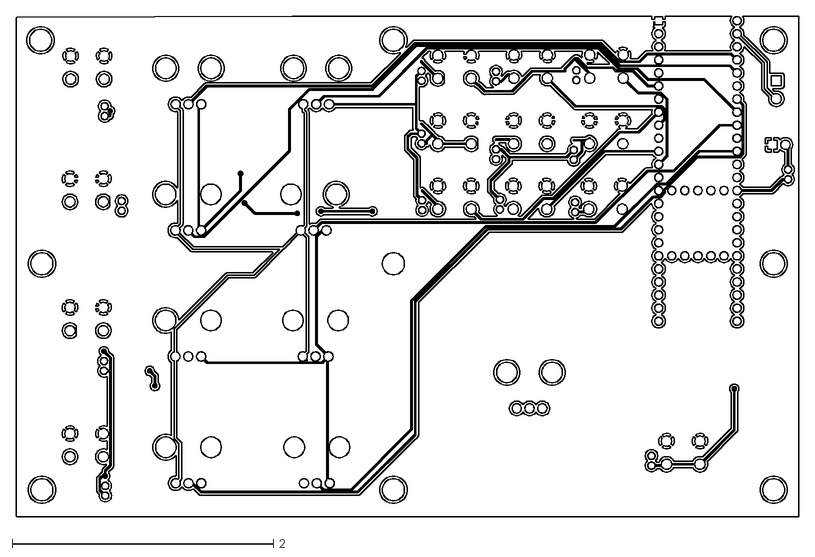
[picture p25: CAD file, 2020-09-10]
pcb/MVP/DXF/the_mvp_v1.2-B_Cu.dxf
5.99 x 3.83

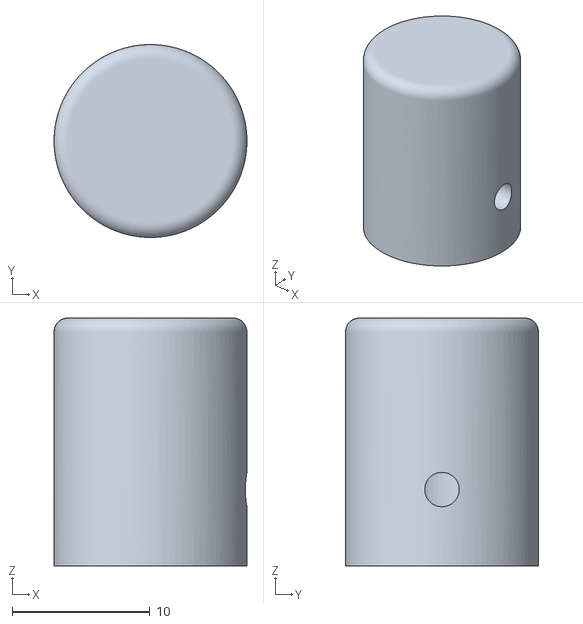
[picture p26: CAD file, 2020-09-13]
3d-prints/MVP/Knob_small.stl
14.0 x 14.0 x 18.0

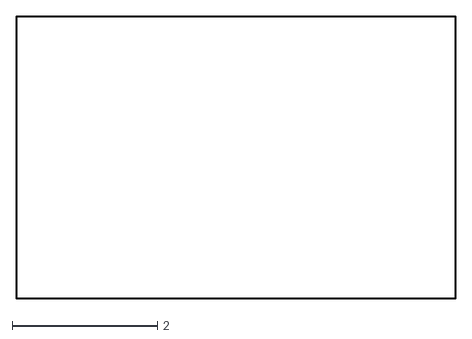
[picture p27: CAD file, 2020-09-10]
pcb/MVP/DXF/the_mvp_v1.2-Edge_Cuts.dxf
6.04 x 3.88

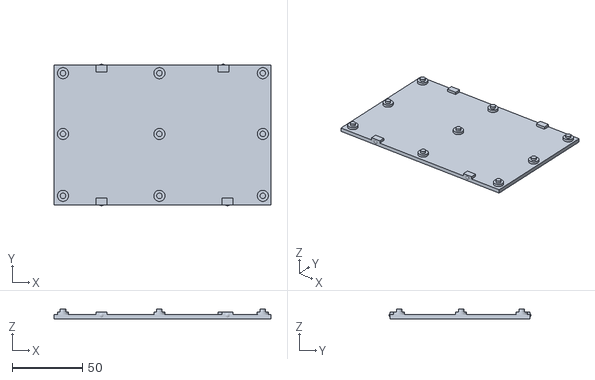
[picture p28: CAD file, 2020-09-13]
3d-prints/MVP/Bottomcase.stl
155.0 x 101.2 x 6.80

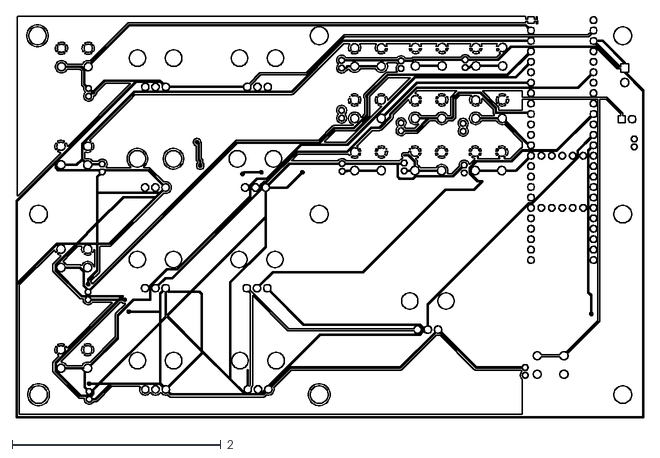
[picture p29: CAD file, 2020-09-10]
pcb/MVP/DXF/the_mvp_v1.2-F_Cu.dxf
6.02 x 3.85

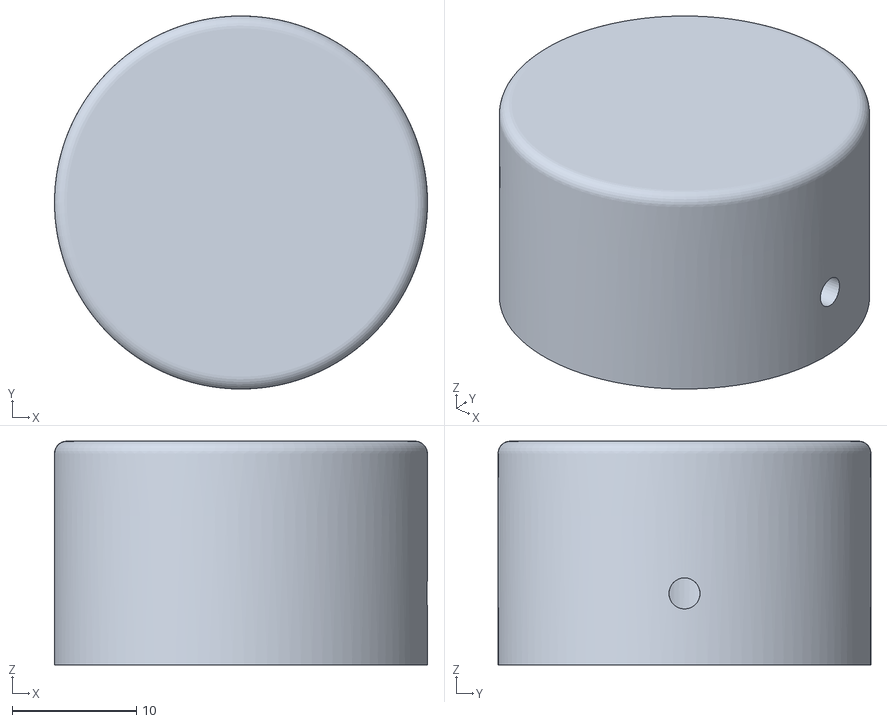
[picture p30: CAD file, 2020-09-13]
3d-prints/MVP/knob_large.stl
30.0 x 30.0 x 18.0

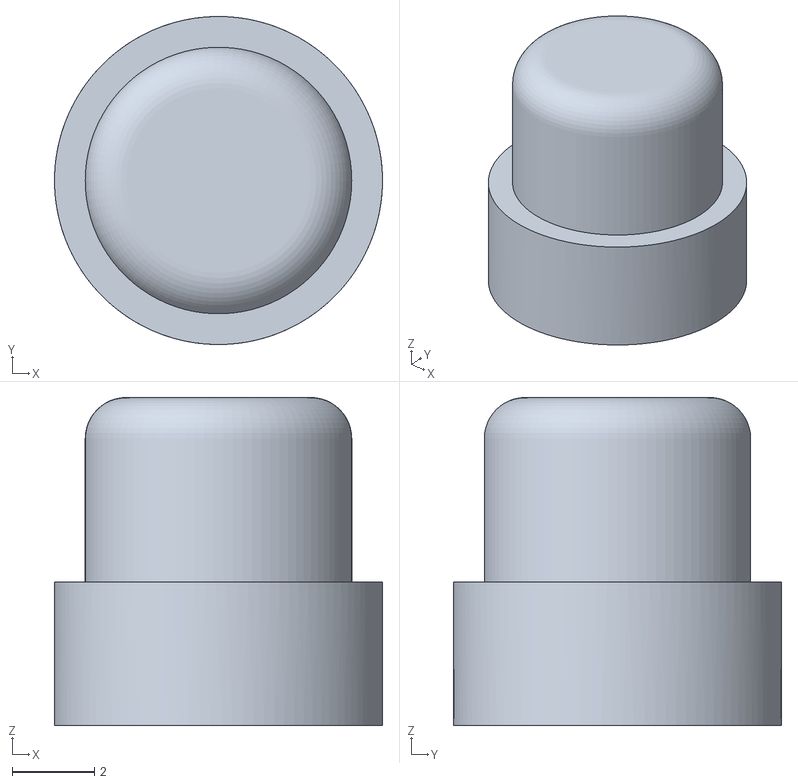
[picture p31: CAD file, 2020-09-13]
3d-prints/MVP/buttonextension for 4.3mm buttons.stl
8.00 x 8.00 x 8.00

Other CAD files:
pcb/MVP/DXF/the_mvp_v1.2-B_Mask.dxf
pcb/MVP/DXF/the_mvp_v1.2-B_Paste.dxf
pcb/MVP/DXF/the_mvp_v1.2-F_Mask.dxf
pcb/MVP/DXF/the_mvp_v1.2-F_Paste.dxf

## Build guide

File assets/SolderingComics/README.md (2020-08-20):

A real good guide for beginners to start soldering right are the Soldering Comics. We like them very much and even if they are not made by us we want to host them here.  

LICENSE

Both Comics are https://creativecommons.org/licenses/by-sa/3.0/
FullSolderComic_EN.pdf by Mitch Altmann, Andie Nordgren and Jeff Keyzer

DE_SolderComic by Mitch Altmann, Andie Nordgren, Jeff Keyzer, Alexander Bodora and Richard Meinsen

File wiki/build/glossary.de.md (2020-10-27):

# Glossar

## BOM
Eine Auflistung der benötigten Bauteile 

## MCU
Eigentlich der Mikrokontroller, aber wir verwenden der Einfachheit halber den Begriff für das jeweilige Entwicklerplatine (Devboard). Da wir im aktuellen Prozess immer ein Devboard nutzen werden. 
* Der Teensy ist ein Devboard. 
* Der Esp32 hingegen ist bezeichnet eigentlich den Chip aber wir nutzen ihn als Synonym für ein Devboard mit esp32-wroom Chip z.B. dem TTGO oder dem NodeMCU ESP32

## Midi2LR
MIDI2LR ist eine Software-Anwendung zur Übersetzung der Schwurbler-Eingabe in Lightroom-Aktionen.   
[https://github.com/rsjaffe/MIDI2LR](https://github.com/rsjaffe/MIDI2LR)

## MVP
Minimal Valuable Product - 
Es handelt sich um einen ersten funktionsfähigen Prototyp. 

## PCB
Die Leiterplatte auf der wir alle Bauteile im verlöten werden. Hierbei werden wir ( zumindest in den ersten Versionen) Durchsteckbauelemente verwenden, da das SMD Löten für Anfänger nicht gerade Ideal ist. 
Als Lötneuling möchtest du vielleicht mal in diese super [Anleitung wie man richtig lötet (gemacht von Mitch Altmann, Andie Nordgren, Jeff Keyzer, Alexander Bodora und Richard Meinsen zu finden auf der Webseite mightyohm.com)](http://mightyohm.com/files/soldercomic/translations/DE_SolderComic.pdf) schauen

## Potentiometer
Ein Potentiometer (kurz Poti), ist ein elektrisches Widerstandsbauelement, dessen Widerstandswerte mechanisch (durch Drehen oder Verschieben) veränderbar sind. Es gibt Linear Poti (auch Fader oder Schieberegler genannt) und Rotary Poti.

## Rotary Encoder oder Drehwinkelgeber
Ein Rotary Encoder ist eine Art Positionssensor, der zur Bestimmung der Winkelposition einer rotierenden Welle verwendet wird. Er erzeugt ein elektrisches Signal, entweder analog oder digital, entsprechend der Drehbewegung. Mehr Details gibt's hier: https://howtomechatronics.com/tutorials/arduino/rotary-encoder-works-use-arduino/ 

## Teensy
Der Teensy ist ein Development Board mit vielen Funktionen in einem sehr kleinen Paket.    
[> Teensy First Use](https://www.pjrc.com/teensy/first_use.html)   

***
_[ > English Version](glossary.en.md)_

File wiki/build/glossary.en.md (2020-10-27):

# Glossary

## BOM
Bill of materials, it is more or less the list which items you need to create a board

## MCU
The mcu is shorthand for microcontroller unit. When we speak of the mcu, we mostly mean a dev board. 
* Teensy is a dev board. 
* Esp32 is the chip itself but we mostly use it as synonym for the devboards with esp32-wroom chip like (TTGO, NodeMCU ESP32, ...)

## Midi2LR
MIDI2LR is a software application to translate the Schwurbler input to Lightroom actions.   
[https://github.com/rsjaffe/MIDI2LR](https://github.com/rsjaffe/MIDI2LR)

## MVP
Minimal Valuable Product - This is a first working prototype.

## PCB
It is a Printed Circuit Board. The board where everything gets soldered onto. We use only through the hole soldering items to keep it beginner save. At least for the first board designs. You might want to have a look in this nice [guide how to solder right by Mitch Altmann, Andie Nordgren and Jeff Keyzer from mightyohm.com](http://mightyohm.com/files/soldercomic/FullSolderComic_EN.pdf)

## Potentiometer
A potentiometer is an electrical resistance component whose resistance values can be changed mechanically (by turning or shifting). There are linear potentiometers (faders or sliders) and rotary potentiometers.

## Rotary Encoder
A rotary encoder is a type of position sensor which is used for determining the angular position of a rotating shaft. It generates an electrical signal, either analog or digital, according to the rotational movement. Details can be found here: https://howtomechatronics.com/tutorials/arduino/rotary-encoder-works-use-arduino/

## Teensy
The Teensy is a USB-based microcontroller development system.    
[> PJRC Website](https://www.pjrc.com/teensy/)
_[ > Deutsche Version](glossary.de.md)_

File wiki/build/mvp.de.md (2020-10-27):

# Der Schwurbler MVP Version

**Release Package**    
[> Download Release Package](https://github.com/mommel/hs-lr-midi-schwurbler/releases/tag/v1.0.0)

**Quickstart Guide**
[> Download Quickstart Guide - PDF](https://github.com/mommel/hs-lr-midi-schwurbler/blob/master/quickstartguide/MVP/de/Der%20Schwurbler%20MVP%20-%20Schnellstart.pdf)

[> Download Fix für die Rev 1.1 Platine - PDF](https://github.com/mommel/hs-lr-midi-schwurbler/blob/master/quickstartguide/MVP/SchwurbelFix-MVP1.1.pdf)

**BOM**    
[> Download BOM - PDF](https://github.com/mommel/hs-lr-midi-schwurbler/blob/master/bom/MVP/bom.pdf)   

**Midi2LR Profile für Lightroom 10**    
[> Download](https://github.com/mommel/hs-lr-midi-schwurbler/blob/master/midi2lr-profiles/MVP/Der%20Schwurbler%20MVP%20-%20Midi2LR%20Profiles%20v2.zip)

-----------    
Die bestückte Schwurbler MVP Platine

**BOM für die Pre-Release Version**  

1x Platine - MVP Limited Edition -- 
(Gerber.zip ist im Release Paket enthalten)

1x TEENSY LC (Teensy 3.2 oder 4.1 Boards sind auch kompatible.) -- 
[Muster](https://www.antratek.de/teensy-lc)     

2x Stiftleisten gerade (optional)

2x Buchsenleisten (optional für steckbare Version)  

9x Drehpotentiometer, Mono, 10 kOhm, linear (Höhe je nach Gehäuse) -- 
[Muster](https://www.reichelt.de/drehpotentiometer-mono-10-kohm-linear-6-mm-rk09k113-lin10k-p73815.html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)     

14x Kurzhubtaster 6x6mm, 12V, vertikal (Höhe je nach Gehäuse) -- 
[Muster](https://www.reichelt.de/kurzhubtaster-6x6mm-hoehe-4-3mm-12v-vertikal-taster-3301-p27892.html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)      
   
1x LED 5mm (optional)    

1x Widerstand für LED 470 Ohm (optional)     
     
.

**Erforderliche Software**  

Teensy First Use -- [Installing the Teensy Loader](https://www.pjrc.com/teensy/first_use.html)   

Schwurbler MVP Firmware -- [Download](https://github.com/mommel/hs-lr-midi-schwurbler/releases/tag/v1.0.0)    

MIDI2LR Software --
[Download](https://github.com/rsjaffe/MIDI2LR)   

Midi2LR Profile -- 
[Download](https://github.com/mommel/hs-lr-midi-schwurbler/tree/master/midi2lr-profiles/MVP)     

Teile für den Schwurbler MVP Limited Edition  

**Der Schwurbler MVP im 3d-Druck Gehäuse**  

Der Schwurbler MVP im 3d-Druck Gehäuse

***

***    

# ... und so hat alles angefangen:    

## Erste Vorschläge für die MVP Version

**Funktionalität:**  

* Bewertung per Quickbutton (Modi)
* Farbe per Quickbutton (Modi)
* Ein/Auszoomen per extra  Poti
* Mode/ReglerMapping Change per Quickbuttons (Modi) oder per Rotary + Mode Anzeige
* Adhoc Entwickeln per Quickbutton (modi)
* Ein Display hinzufügen um den aktuellen Modus anzuzeigen?
* Zuücksetzen von Schnellaktionen per zusätzlichem Button

**Umfrageergebnisse zur Zahl und Art der Regler:**
* Drehpoti vs Drehwinkelgeber -- 1/1 (2 Antworten)
* Knöpfe -- 12  (Einstimmig 3 Antworten)
* Schieberegler -- keine/8/2/Enthaltungen (4 Antworten)
* Drehregler -- 0/4/8/12 (4 Antworten)
* Case -- keins/3D Case/Holz/Plexiglas (4 Antworten)

***

## Erste Designvorschläge

Prototype 1 und 2 (3D Renderings)  
[https://github.com/mommel/hs-lr-midi-schwurbler/blob/master/design-drafts/schwurbler_v1.png](https://github.com/mommel/hs-lr-midi-schwurbler/blob/master/design-drafts/schwurbler_v1.png)  
[https://github.com/mommel/hs-lr-midi-schwurbler/blob/master/design-drafts/schwurbler_ii_v2.jpg](https://github.com/mommel/hs-lr-midi-schwurbler/blob/master/design-drafts/schwurbler_ii_v2.jpg)

Schwurbler MTC   
https://github.com/mommel/hs-lr-midi-schwurbler/blob/design-drafts/design-drafts/SchwurblerV1.png

Schwurbler R1  
https://github.com/mommel/hs-lr-midi-schwurbler/blob/master/design-drafts/Interface-Schwurbler-R1.png

Schwurbler R2   
https://github.com/mommel/hs-lr-midi-schwurbler/blob/master/design-drafts/Interface-Schwurbler-R2.png

 … Fader Version …

Schwurbler F1   
https://github.com/mommel/hs-lr-midi-schwurbler/blob/master/design-drafts/Interface-Schwurbler-F1.png

Schwurbler F2   
https://github.com/mommel/hs-lr-midi-schwurbler/blob/master/design-drafts/Interface-Schwurbler-F2.png

 … die X Serie …

Schwurbler X1  
https://github.com/mommel/hs-lr-midi-schwurbler/blob/master/design-drafts/Interface-Schwurbler-X1.png

Schwurbler X2   
https://github.com/mommel/hs-lr-midi-schwurbler/blob/master/design-drafts/Interface-Schwurbler-X2.png

**Umfrageergebnisse zum Design:**

* Schwurbler X1 - 1 Stimme
* Schwurbler X2 - 3 Stimmen

***

## Layout der MVP Version

8 Drehregler mit je 4 Tastern  
1 Tastenblock mit 9 Tasten   
1 Zentraler Drehregler  
1 Taster zur Auswahl des Belegungs-Modus der Bedienelemente
  
Interface Layout - Schwurbler X2

PCB Rendering - Schwurbler X2

Auf der Platine besteht optional die Möglichkeit alle Buttons und Poti als externe Elemente ein zu löten. Zusätzlich gibt es Anschlüsse für eine Status LED. Und, falls die analogen Potis Störungen haben können Kodensatoren zur Stromglättung hinzugefügt werden.

## Tutorial 01 - Bestückung
(http://www.youtube.com/watch?v=eH0KHRkc_u4 "Tutorial 01 - Bestückung")

## Gehäuse Prototyp 01
Erster 3d-Print für ein Gehäuse

## Gehäuse Prototyp 02
Gehäuse Prototyp - Rendering

***

_[ > English Version](mvp.en.md)_

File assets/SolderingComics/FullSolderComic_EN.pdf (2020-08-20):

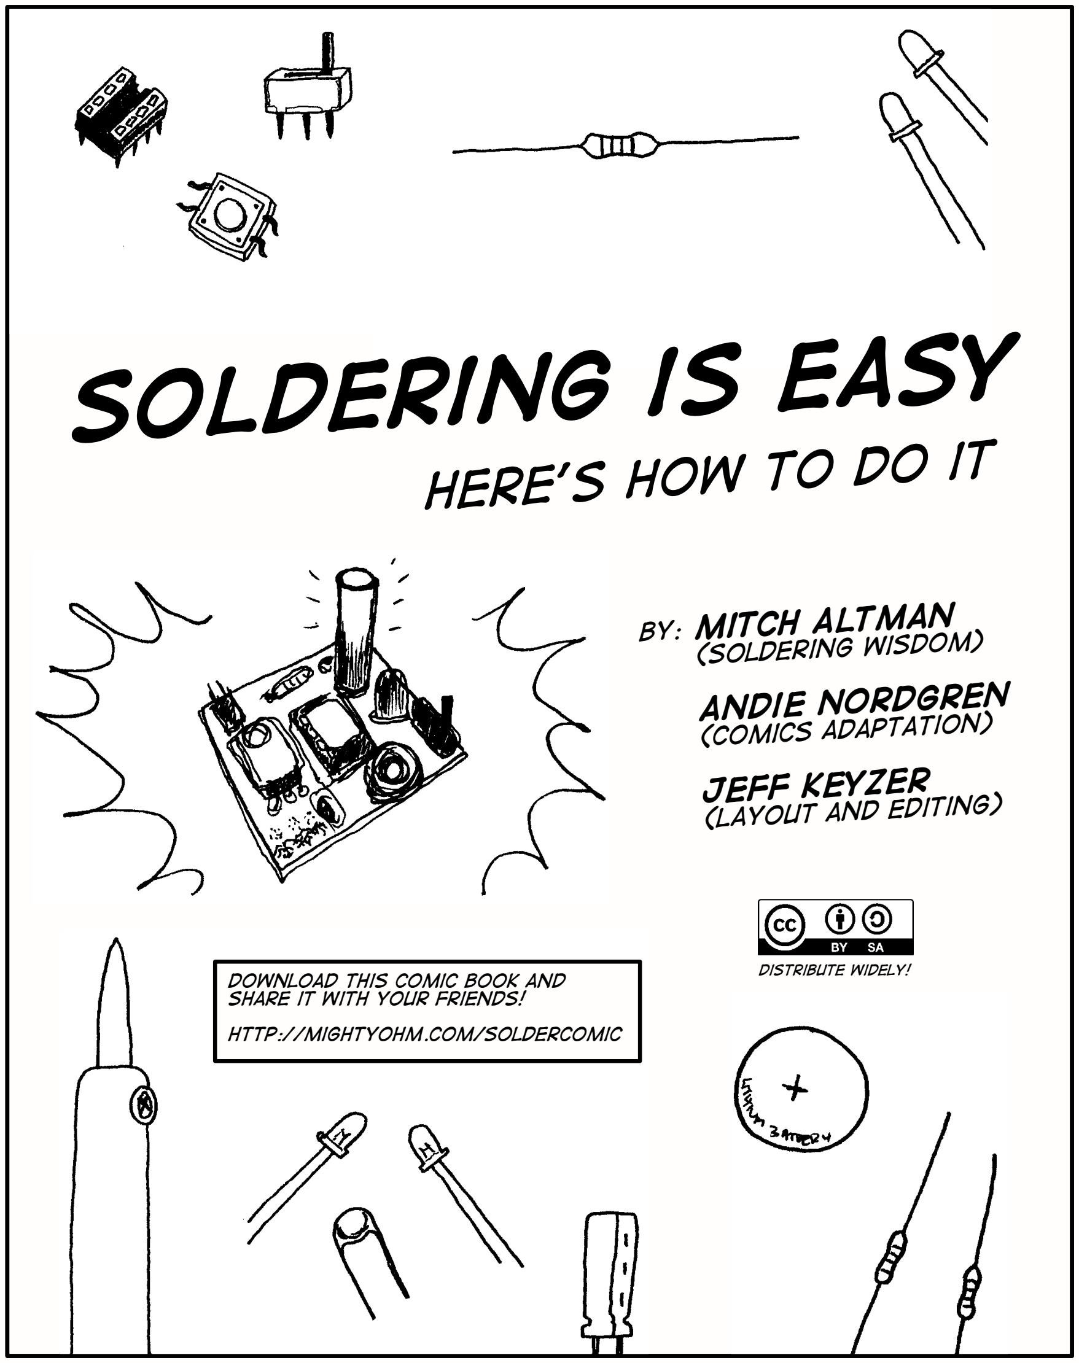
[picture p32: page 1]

# Soldering is easy

# here's how to do it

# by: Mitch Altman

# (soldering wisdom)

# Andie Nordgren

# (Comics adaptation)

# Jeff Keyzer

# (Layout and editing)

## Distribute widely! Download this comic book and share it with your friends!

## http://mightyohm.com/soldercomic

Soldering is a really useful skill.

# It is also way easy!

### REally, it is!

You’ll see.

### Soldering is also lots of fun!

If you know how to solder, you can make just

## about anything with electronics, which is

just too cool!
There are many ways to make good solder connections.
I’m going to explain how I do it.

# Let's get started!

This is a soldering iron.

Its tip gets hot enough to melt solder, which is metal.
That's about 200 degrees Celsius!

### Safety tip #1 (of 3): If you touch the tip, you will

### let go very quickly!

This is solder.
It is made of metal, Usually tin and lead.

the elements

### Sn and Pb

## It is actually hollow and filled with rosin

(similar to the stuff used to make bows for violins

sticky).

### When the solder heats up, the rosin melts almost immediately

The Metal
follows
shortly
thereafter

The ROSIN flows around what you want to solder, cleans the metal, and helps make a good solder connection.

We use the soldering iron to melt the solder and make electrical connections.

### The best solder for electronics has

rosin core and is 60% tin, 40% lead.
also known
as flux

There are other types, for instance lead-free solder, but it has toxic chemicals in its core, and it is not quite as easy to use as solder with lead. It also corrodes soldering iron tips quickly. If you can only get lead-free solder where you live, it’s OK, but please don’t breathe in the nasty smoke.

# Safety tip #2 (of 3):

## Lead is poisonous. It gets

on your skin when you hold the

## solder, so wash your hands after soldering!

If you don’t wash your hands after soldering, the lead may get in your body, where it gets stored in your brain for your entire life. if enough collects there then you go insane, and you lose all of your friends. So - wash your hands after soldering, and keep your friends!

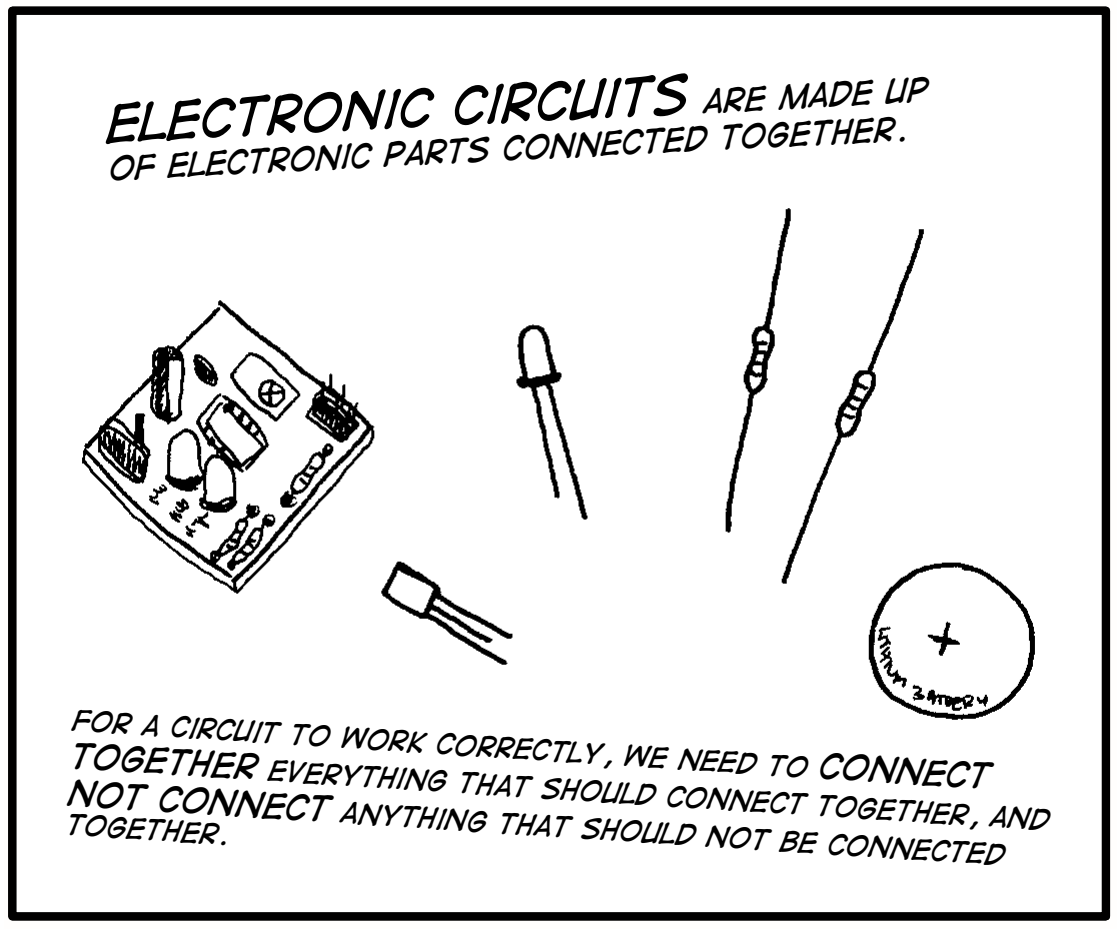
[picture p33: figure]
Electronic circuits are made up of electronic parts connected together.; connect; together.

For a circuit to work correctly, we need to
together everything that should connect together, and not connect anything that should not be connected

There are many ways to connect electronic parts together, but perhaps the easiest way is with a

# Printed Circuit Board

PCB or
just

### "THE

### Board"

The PCB makes
it easy because
it has

# pads for

each part.

If you look carefully at the PCB, you will see lines connecting pads together with other pads – these lines are called traces.

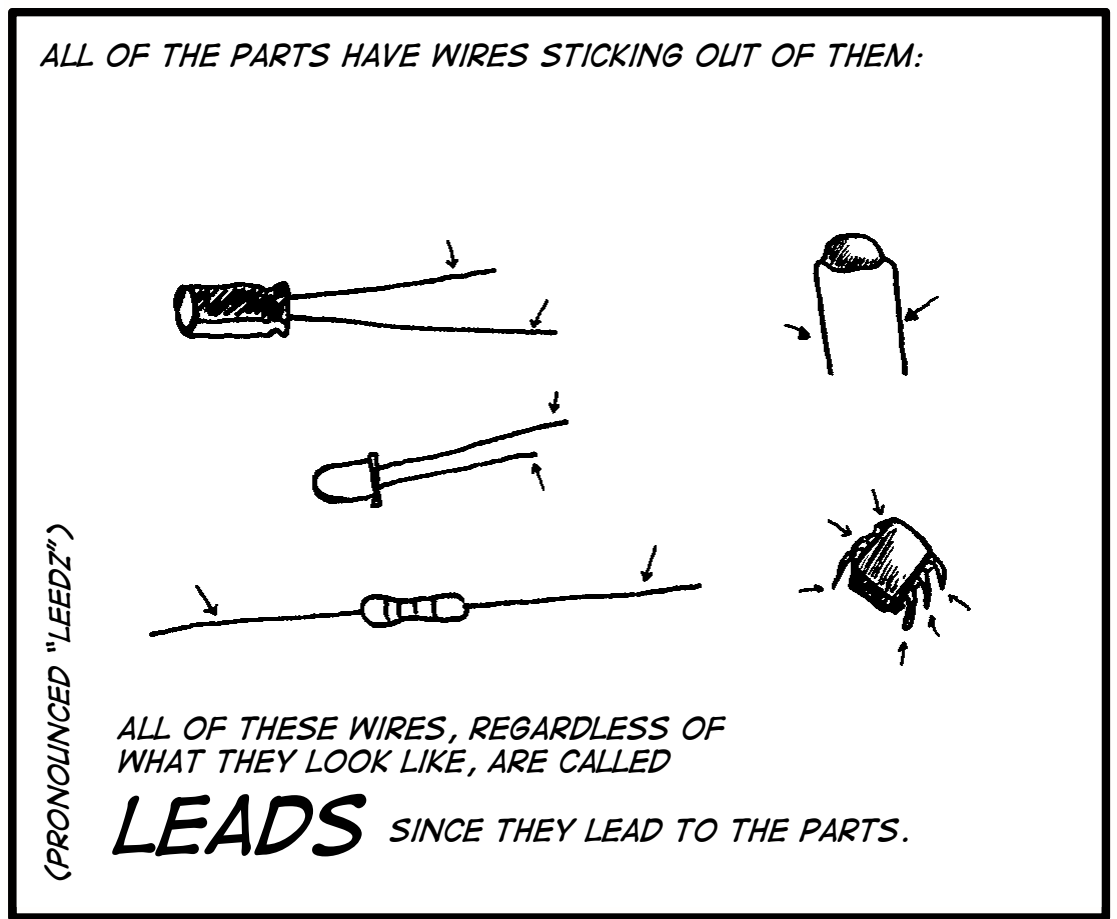
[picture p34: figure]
leads; (pronounced “leedz”); All of these wires, regardless of what they look like, are called; since they lead to the parts.

All of the parts have wires sticking out of them:

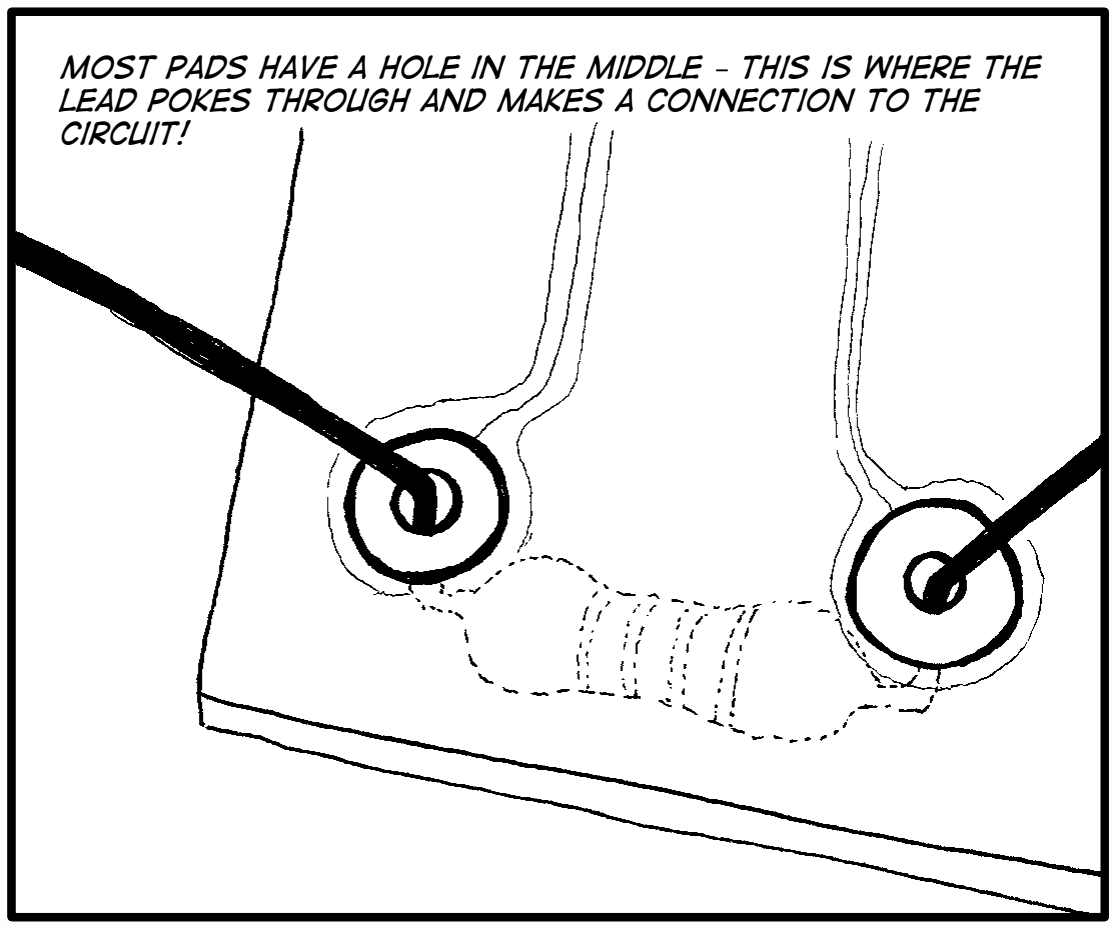
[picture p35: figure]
circuit!

Most pads have a hole in the middle – this is where the lead pokes through and makes a connection to the

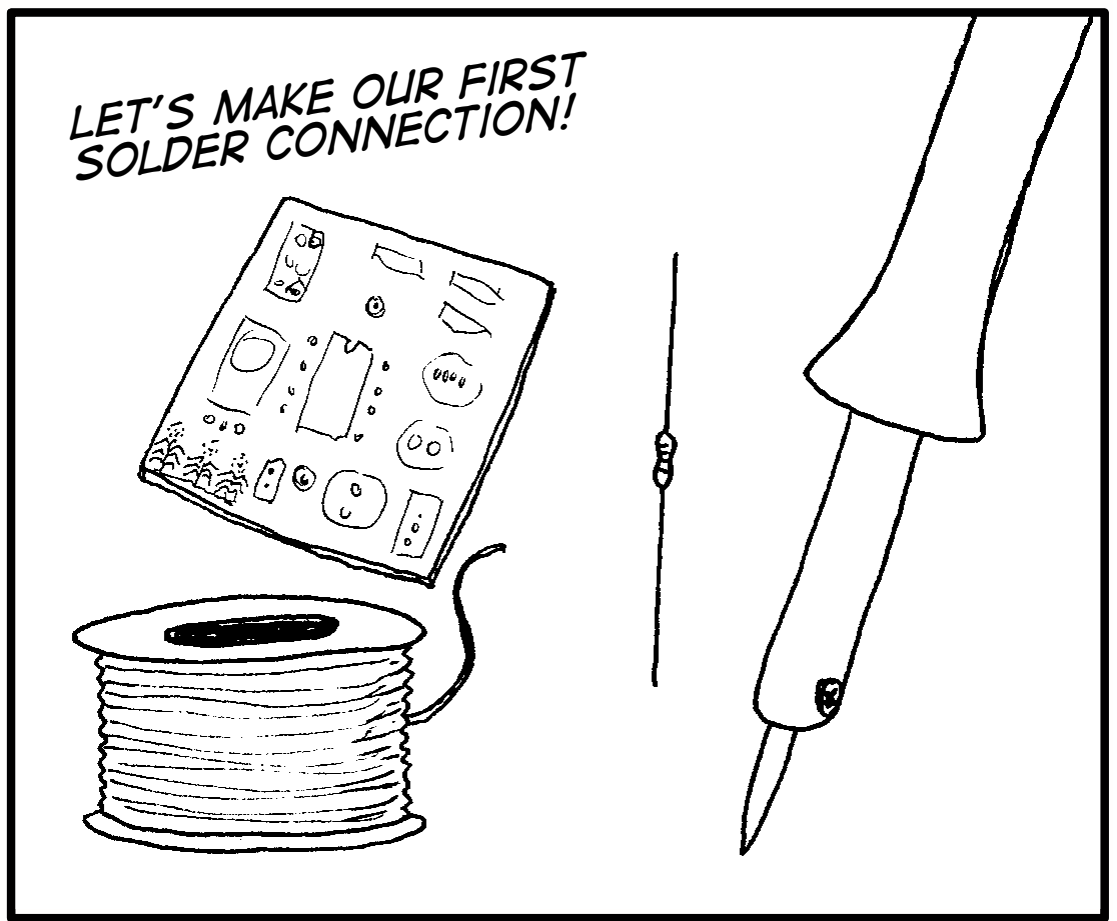
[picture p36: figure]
Let’s make our first solder connection!

If you put all of the leads from the parts into

### the correct pads for the parts

and if you put all of the parts in the correct

### orientation and if you make all good solder connections

# then the circuit will just work!

This is because the board connects everything that should be connected, and nothing that should not be connected.

some parts
can go in the
wrong way!

We’ll start with a resistor.

Resistors have two leads and (unlike some parts, such as diodes, which have a “plus” side and a “minus” side) can be placed in their pads in either direction.

PCBs usually have markings to show where each part goes (and if the orientation matters, the PCB usually has some way to show you this).

Since the word “resistor” starts with the letter “R”, the PCB usually marks places where resistors go with an “R”, followed by the resistor’s number, such as “R3”

So, to solder in the resistor, you start by finding the correct value of resistance from the project’s documentation.

Then bend the two
leads of the resistor
down the width of the
part, like this:

Then place the two
leads through the two
pads on the PCB for
this resistor.

For most PCBs, all of the parts are placed through the pads on the printed side of the PCB (which we’ll call the top of the board), and we’ll solder all of the pads on the bottom of the board.

You push the resistor’s
leads through the pads
until the part rests flat
on the PCB

(sometimes you may need to wiggle and tug gently on the leads from the bottom of the PCB to do this).

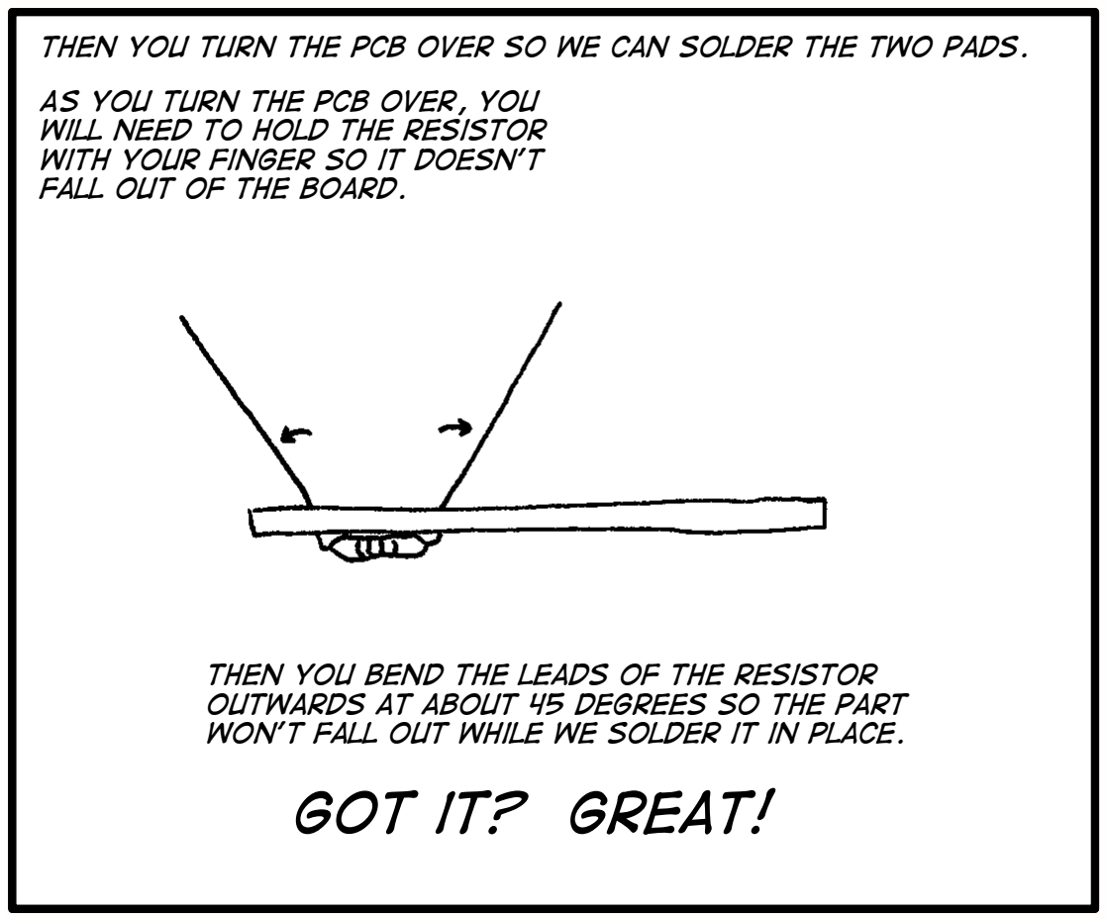
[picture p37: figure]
As you turn the PCB over, you will need to hold the resistor with your finger so it doesn’t fall out of the board.; then you bend the leads of the resistor; Got it? Great!
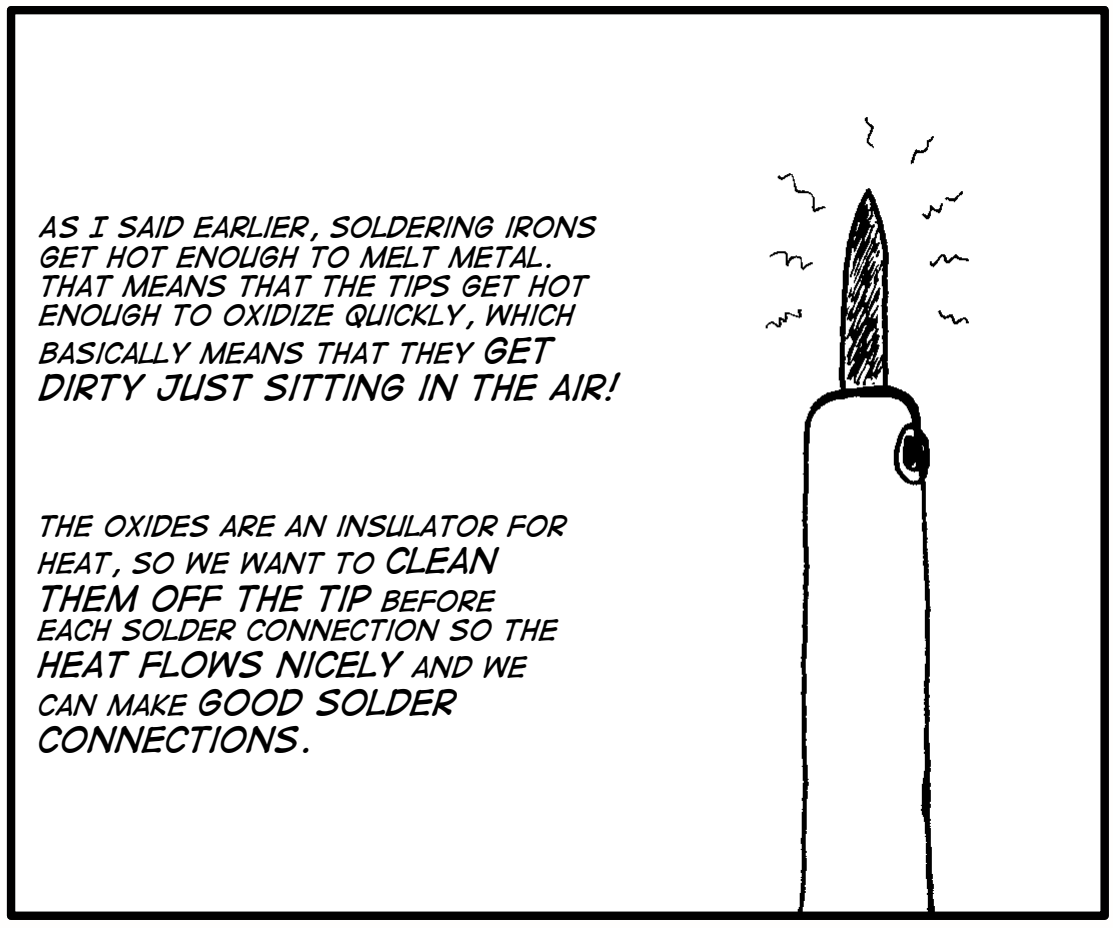
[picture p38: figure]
As I said earlier, soldering irons get hot enough to melt metal. That means that the tips get hot enough to oxidize quickly, which basically means that they get dirty just sitting in the air!; The oxides are an insulator for heat, so we want to clean them off the tip before each solder connection so the heat flows nicely and we can make good solder connections.

Then you turn the PCB over so we can solder the two pads.

outwards at about 45 degrees so the part won’t fall out while we solder it in place.

This is why we have a wet sponge:
to clean the oxides off the tip. Just scrape the
tip across the sponge gently,

### then rotate the iron and scrape gently

across the sponge again.

This should make the tip silvery and somewhat shiny – ready

### to solder. Remember to clean the tip like this before each connection you make – the tips oxidize

quickly!

### If the tip is nice and silvery and shiny, you

can make good connections.

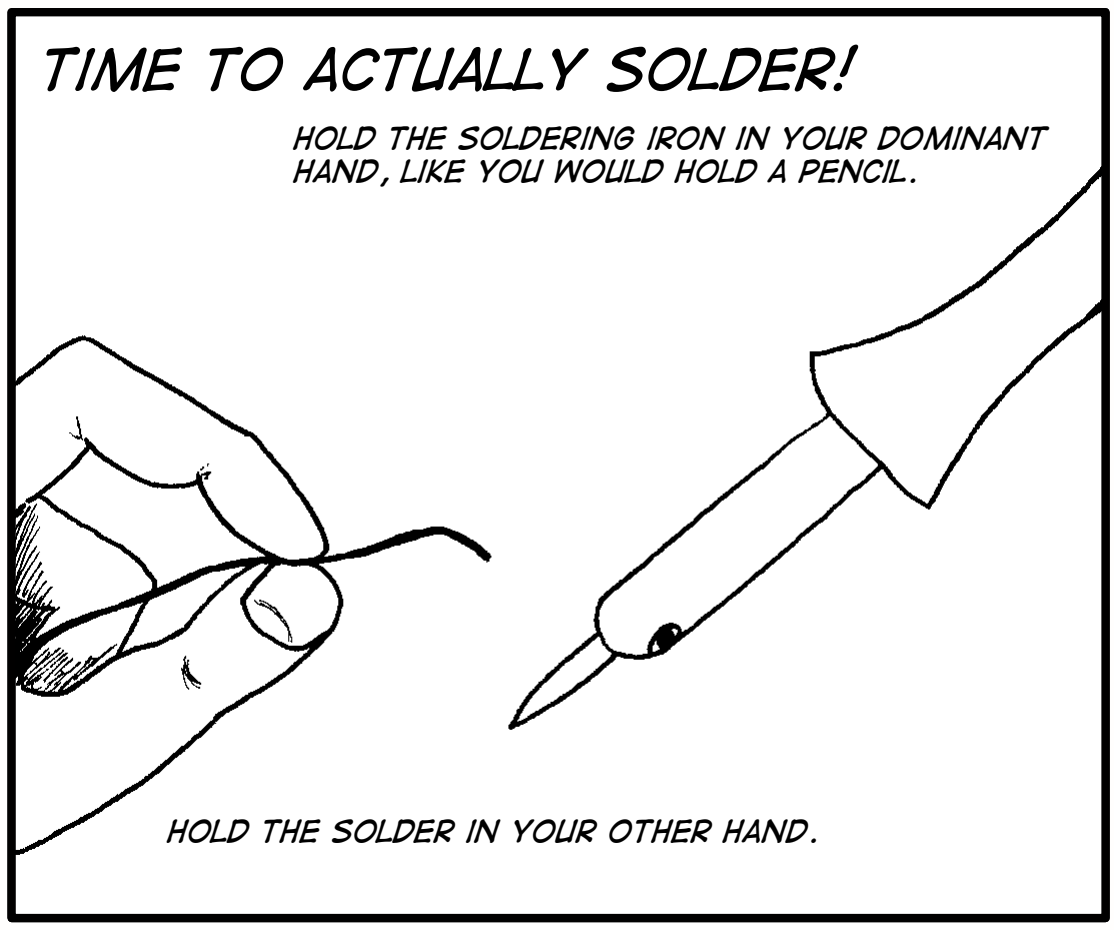
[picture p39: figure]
Time to actually solder!; hand, like you would hold a pencil.; Hold the solder in your other hand.

Hold the soldering iron in your dominant

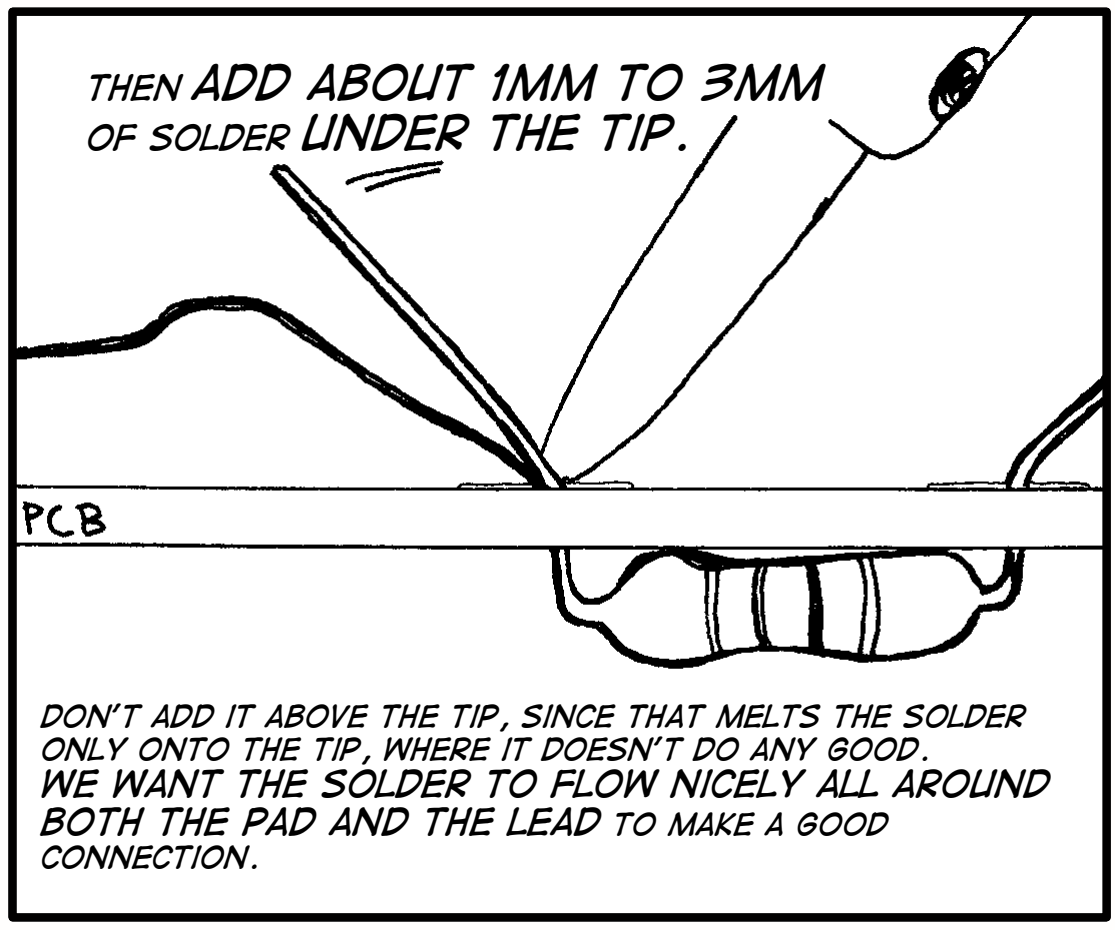
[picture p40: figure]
Then add about 1mm to 3mm of solder under the tip.; connection.

Don’t add it above the tip, since that melts the solder only onto the tip, where it doesn’t do any good.

### we want the solder to flow nicely all around both the pad and the lead to make a good

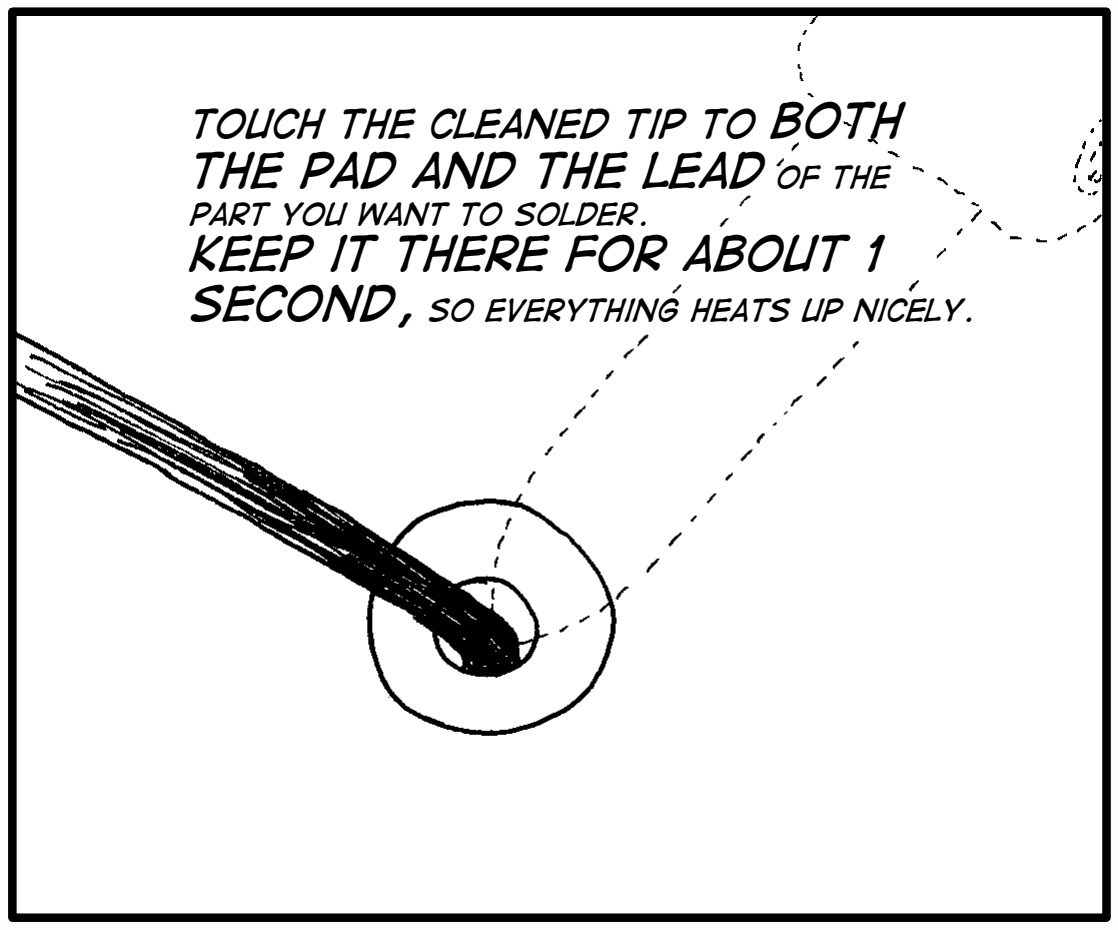
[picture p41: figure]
Touch the cleaned tip to both the pad and the lead of the; part you want to solder. Keep it there for about 1; second, so everything heats up nicely.
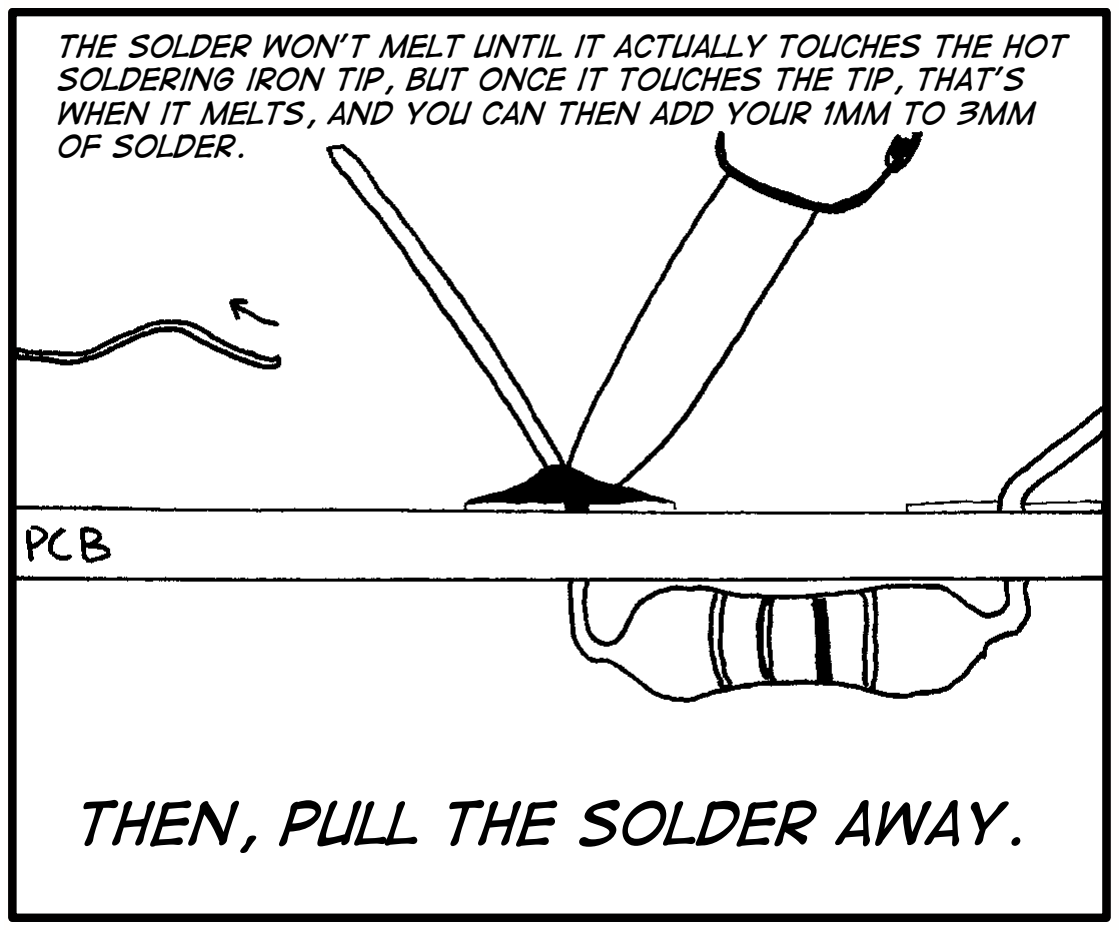
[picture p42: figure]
of solder.; Then, pull the solder away.

The solder won’t melt until it actually touches the hot soldering iron tip, but once it touches the tip, that’s when it melts, and you can then add your 1mm to 3mm

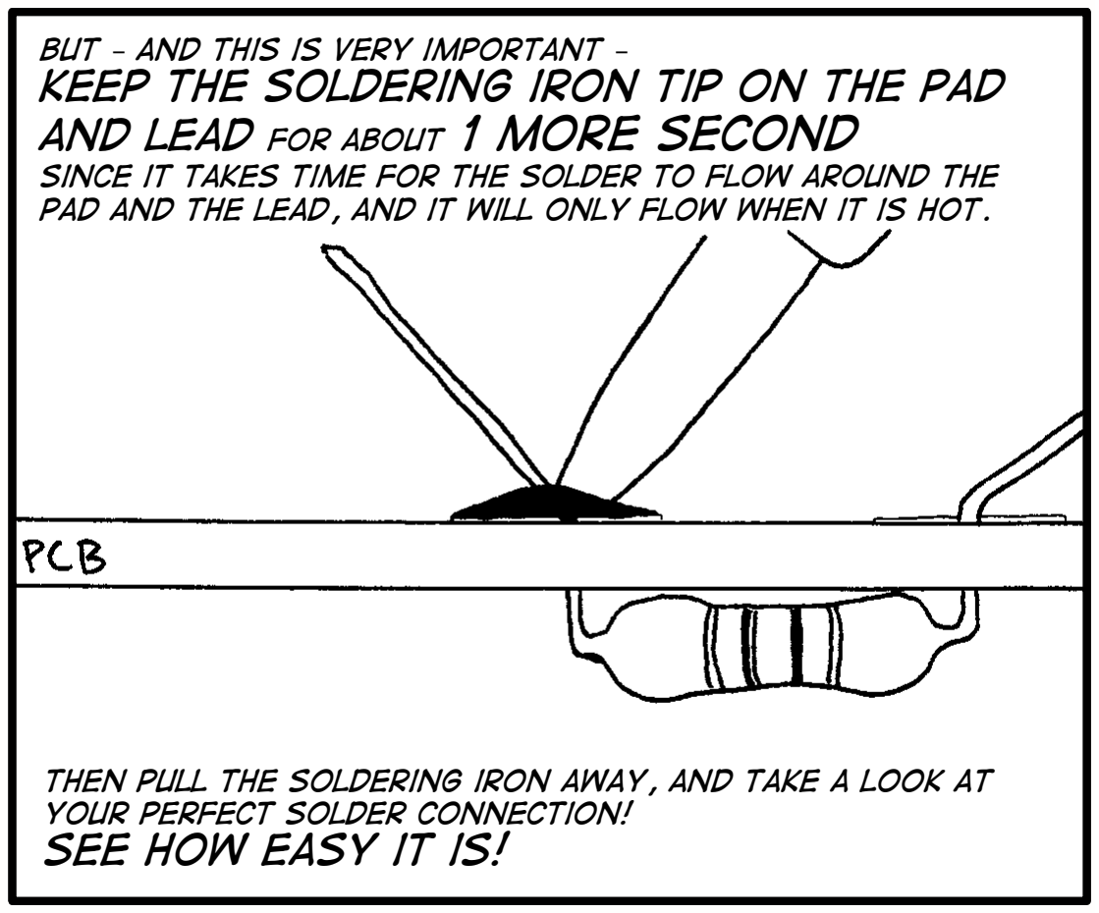
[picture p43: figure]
But – and this is VERY important – keep the soldering iron tip on the pad and lead for about 1 more second; your perfect solder connection! See how easy it is!

since it takes time for the solder to flow around the pad and the lead, and it will only flow when it is hot.

Then pull the soldering iron away, and take a look at

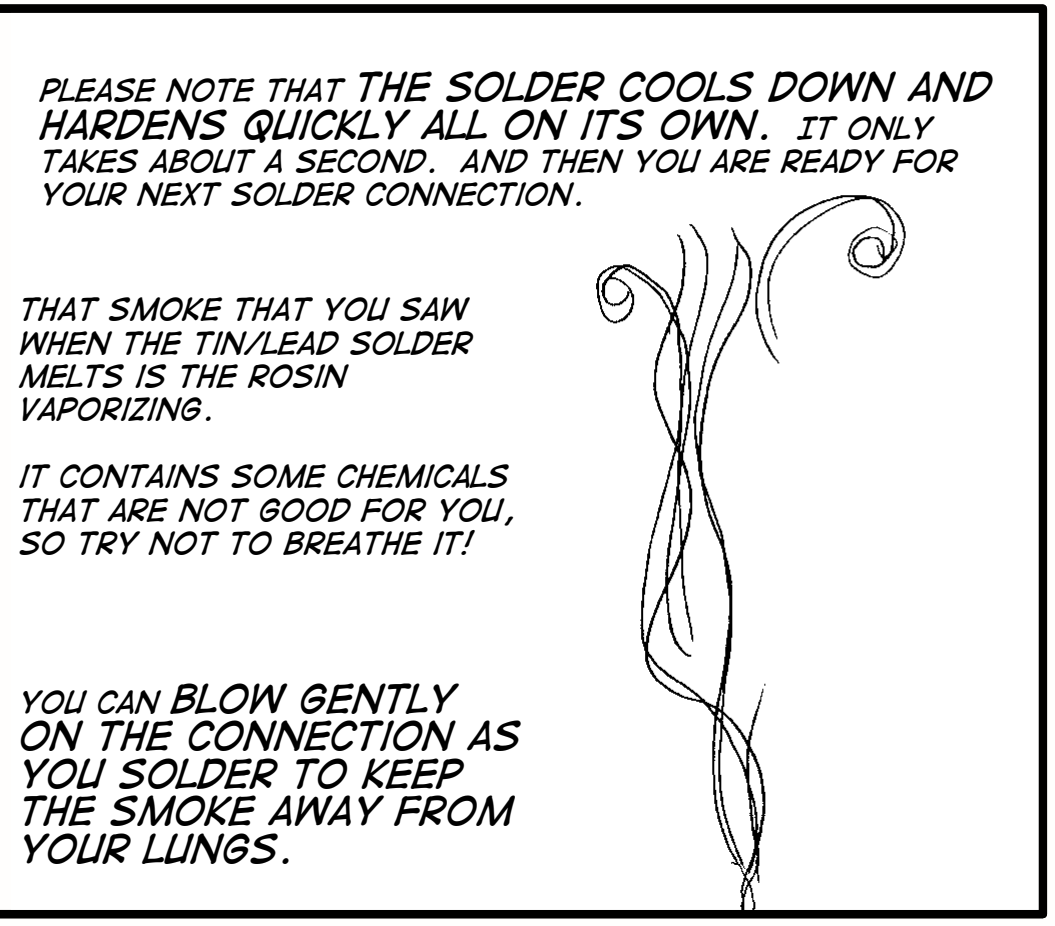
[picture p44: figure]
hardens quickly all on its own. It only; your next solder connection.; That smoke that you saw when the tin/lead solder melts is the rosin vaporizing.; it contains some chemicals that are not good for you, so try not to breathe it!; you can blow gently on the connection as you solder to keep the smoke away from your lungs.

## Please note that the solder cools down and

takes about a second. And then you are ready for

### Now put that soldering iron back in its stand

while we’re not using it.

## The stand keeps the hot iron safely on the

table. Most people say that it’s not fun to have it land in your lap!

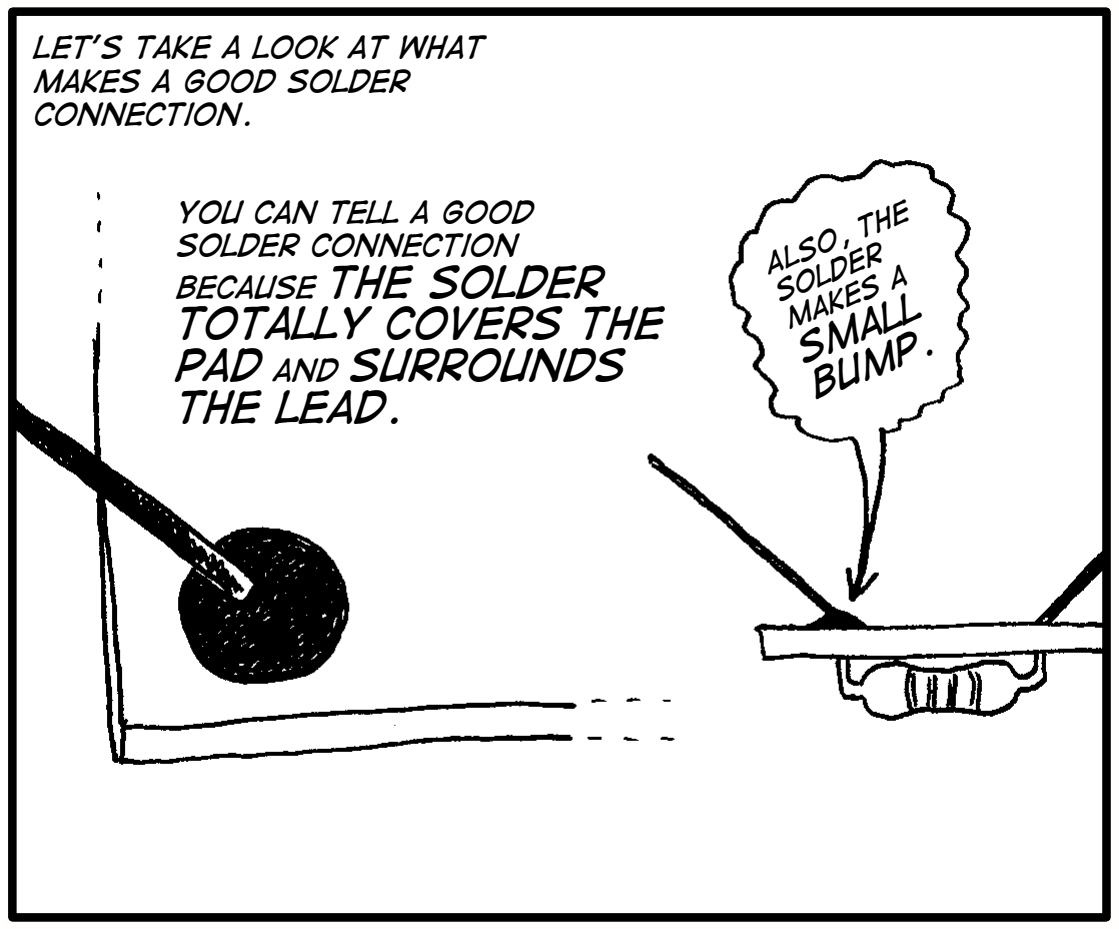
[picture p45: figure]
Let’s take a look at what makes a good solder connection.; You can tell a good solder connection because the solder totally covers the pad and surrounds the lead.; Also, the solder makes a small bump.
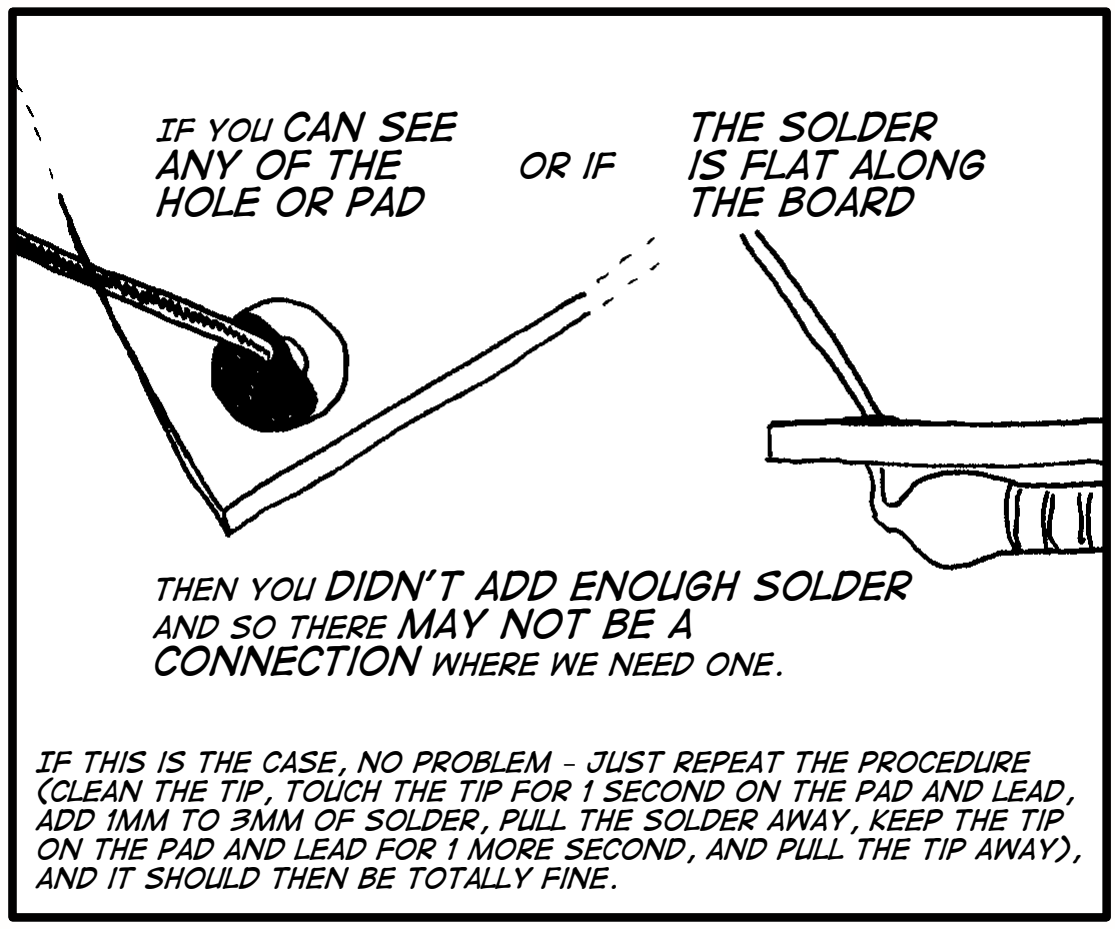
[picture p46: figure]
If you can see any of the hole or pad; then you didn’t add enough solder and so there may not be a connection where we need one.; and it should then be totally fine.; the solder is flat along the board

If this is the case, no problem – just repeat the procedure (clean the tip, touch the tip for 1 second on the pad and lead, add 1mm to 3mm of solder, pull the solder away, keep the tip on the pad and lead for 1 more second, and pull the tip away),

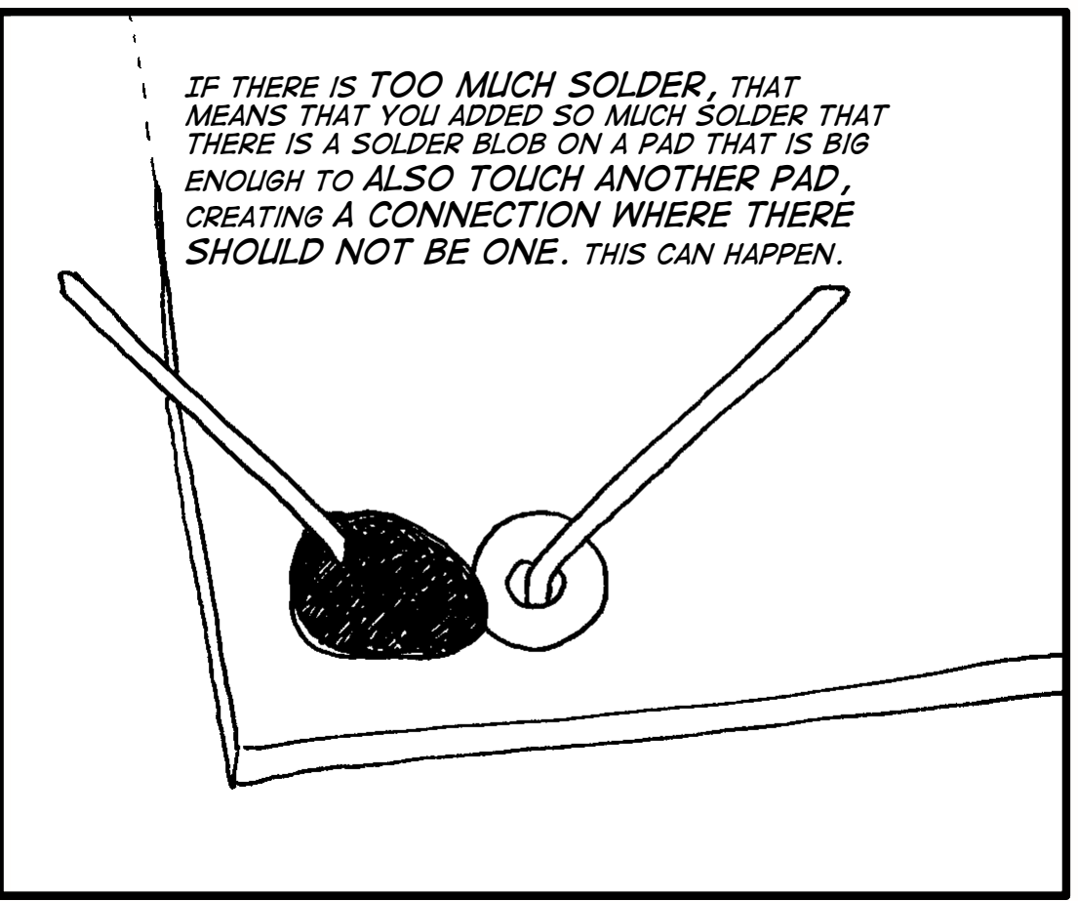
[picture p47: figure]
If there is too much solder, that; enough to also touch another pad, creating a connection where there should not be one. This can happen.

means that you added so much solder that there is a solder blob on a pad that is big

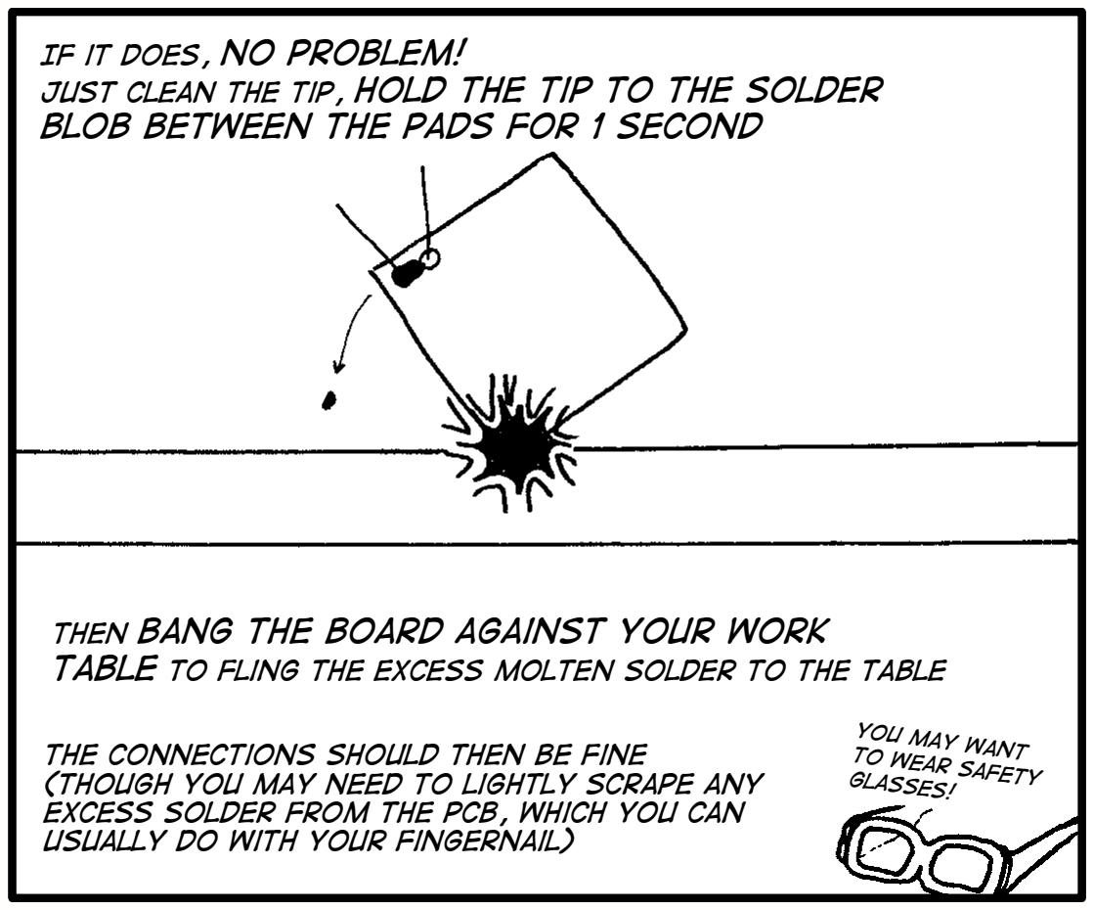
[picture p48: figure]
If it does, no problem!; blob between the pads for 1 second; then bang the board against your work; you may want to wear safety glasses!; The connections should then be fine; usually do with your fingernail)

### just clean the tip, hold the tip to the solder

table to fling the excess molten solder to the table

(though you may need to lightly scrape any
excess solder from the PCB, which you can

### In between too much and

too little solder is a
lot of leeway.
This is one reason why
soldering is easy.

Both
good! good too!

Some people like to solder parts to their pads after adding a bunch of parts to the board.

I prefer to add and solder only one part

## to the board at a time. I find this easier

since there aren’t so many leads that can get in the way of my soldering iron.

Also, if I add more than one part to the board I sometimes miss soldering a pad, since it isn’t so easy (as you might think it would be) to see which connections are soldered.

After soldering all of the leads of the part you are soldering, it is time to cut off the
excess leads.
This must be done to ensure that the excess leads do not bend over and short to another lead or pad.

if this happens, then there will be a
connection where we do not want one.

To cut the lead, we’ll use a
small wire cutter.

### One side has flat cutting

edges, and the other side has a deep groove.

### Place the flat edge down, parallel to the PCB, just at the top of the little bump of

solder.

### squeeze the handles, and the cutting edges

snap shut.

which turns the
excess lead into a

## projectile that hits you right in your eye!

## Safety tip #3 (of 3): ALWAYS hold the lead you are cutting with one hand while

you cut with your other hand.

If you always do this, you will always be safe.

you may
also
want

to wear
safety
glasses!

If the excess lead is too short to hold onto (but long enough to potentially short out to something on your PCB),
then position the wire cutter,

## hold your fingers over

the lead,

this will keep the
excess lead from
hitting anyone in
the eye (or
shorting out
somewhere on
your project)

and then squeeze.

Leads that are already very short, such as IC sockets, do not need to be cut – they have leads that are too short to bend over and make shorts.

If you make a mistake, it is totally OK.

## All mistakes are fixable (though some

are easier than others).

## And making mistakes is how we

learn to become better at everything we
do.
While soldering is easy, unsoldering

## takes lots of practice. And if you

make a mistake, you get to have some practice!

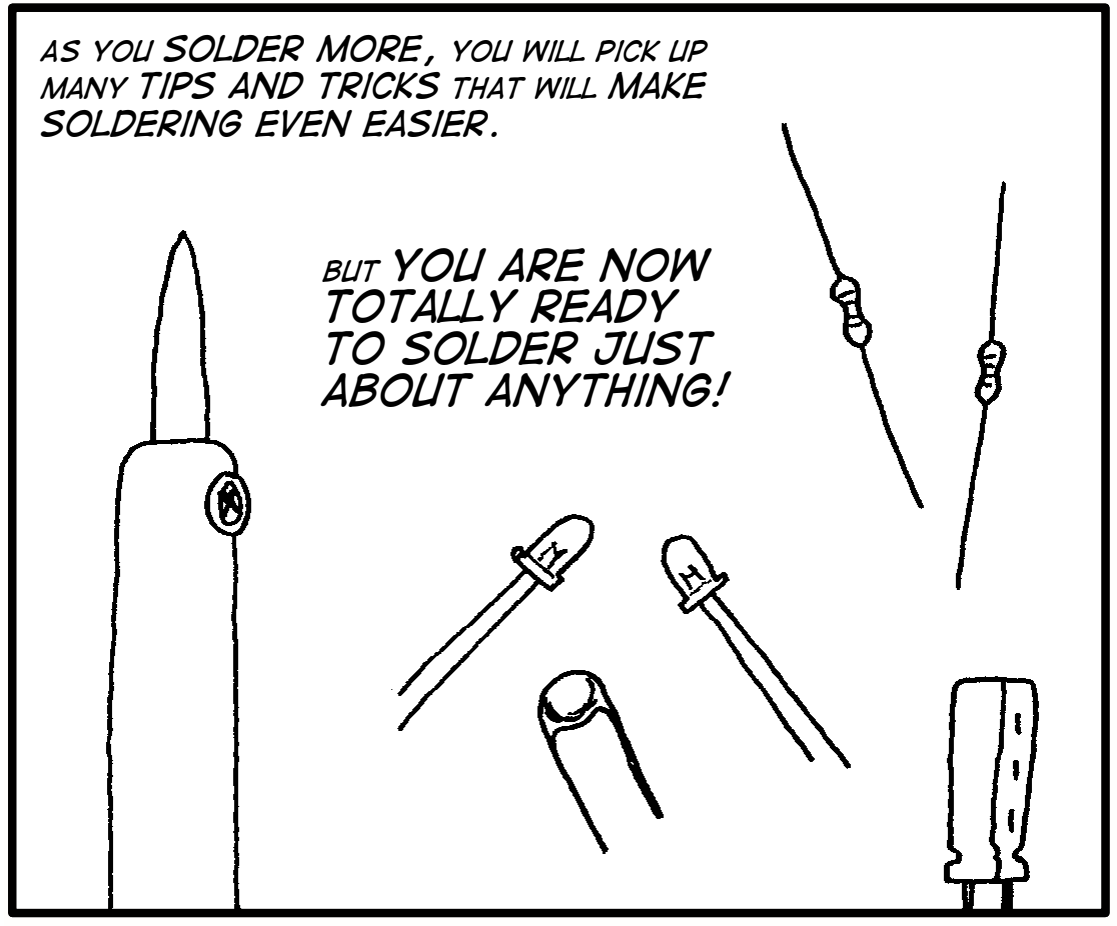
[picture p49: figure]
As you solder more, you will pick up many tips and tricks that will make soldering even easier.; But you are now totally ready to solder just about anything!

If you like soldering, and want to solder well, you’ll want to buy some good tools.

### But you do not need to spend a lot

of money to get them.

You can buy a decent soldering iron (in the shape of a long, fat pencil) for about US$15

You’ll need a

### soldering iron

stand that fits a
wet sponge,
which will cost you
about US$6

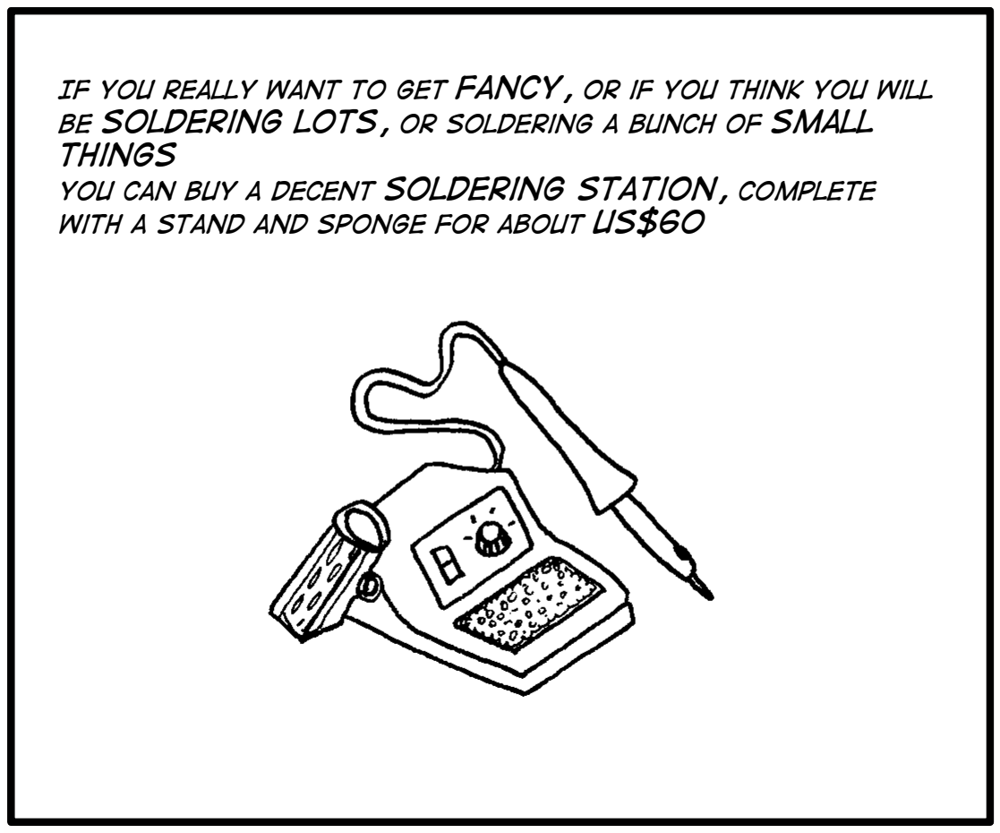
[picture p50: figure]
things; with a stand and sponge for about US$60

If you really want to get fancy, or if you think you will be soldering lots, or soldering a bunch of small

you can buy a decent soldering station, complete

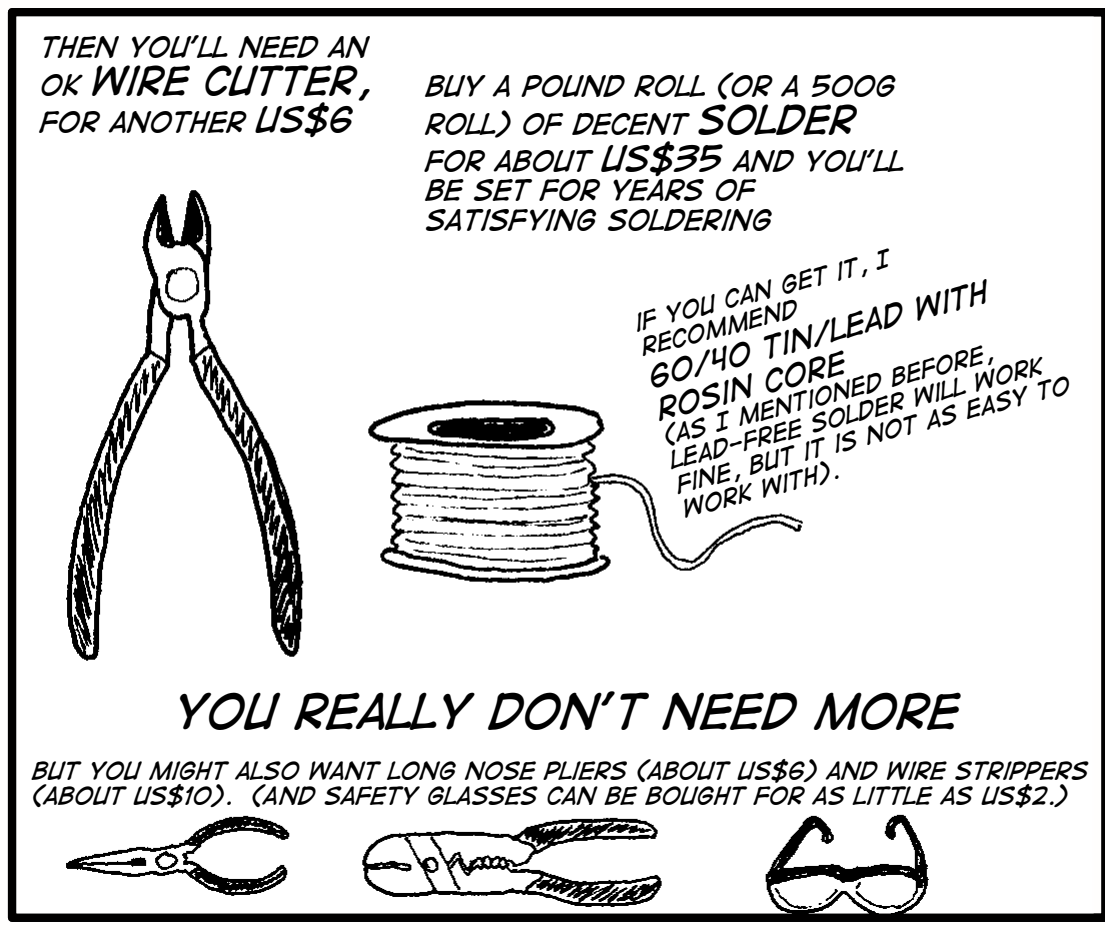
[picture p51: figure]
Then you’ll need an OK wire cutter, for another US$6; Buy a pound roll (or a 500g roll) of decent solder for about US$35 and you’ll be set for years of satisfying soldering; if you can get it, I; recommend; 60/40 tin/lead with; rosin core; (as I mentioned before, lead-free solder will work fine, but it is not as easy to; work with).; You really don’t need more

But you might also want long nose pliers (about US$6) and wire strippers (about US$10). (And safety glasses can be bought for as little as US$2.)

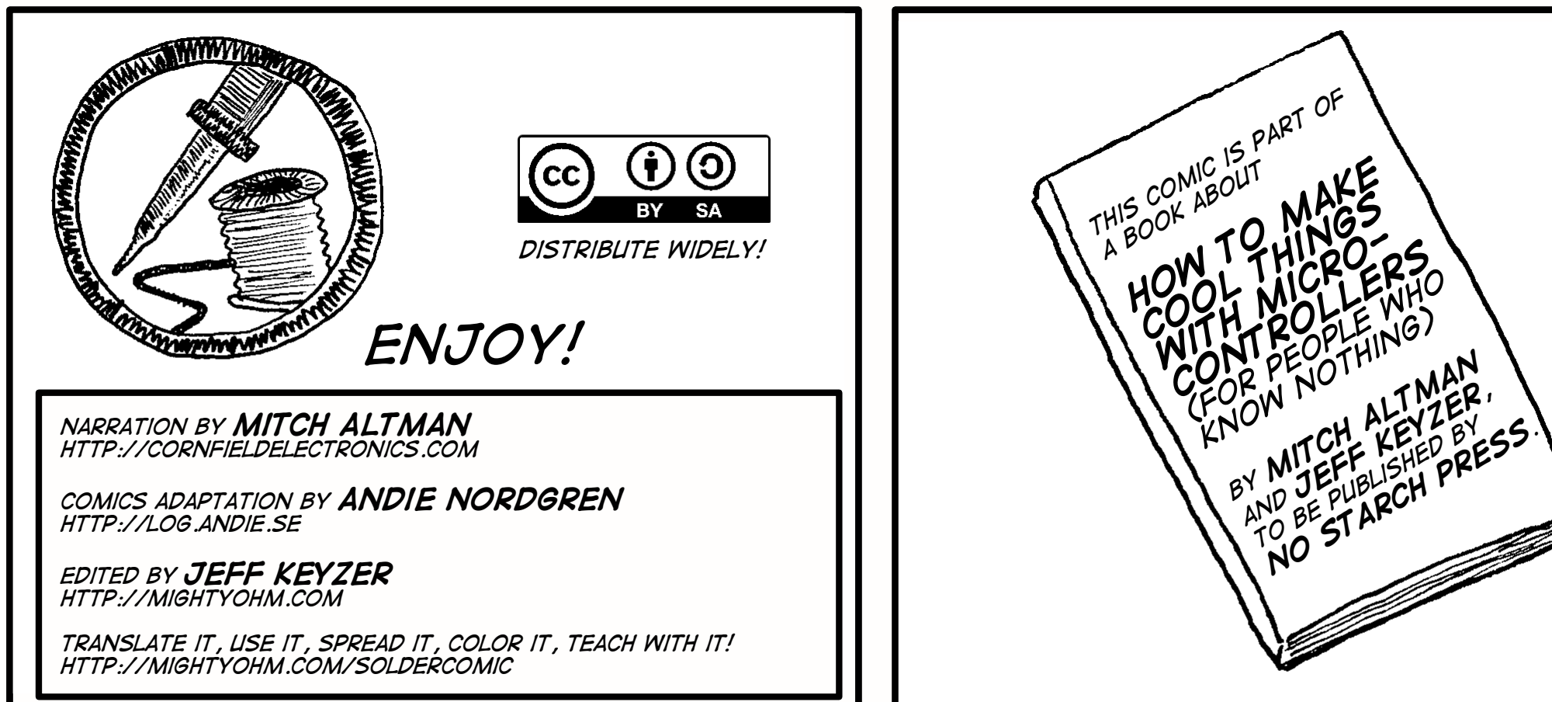
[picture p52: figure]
Narration by Mitch Altman; http://cornfieldelectronics.com; COmics adaptation by Andie Nordgren http://log.andie.se; Edited by Jeff Keyzer http://mightyohm.com; http://mightyohm.com/soldercomic; Distribute widely! Enjoy!
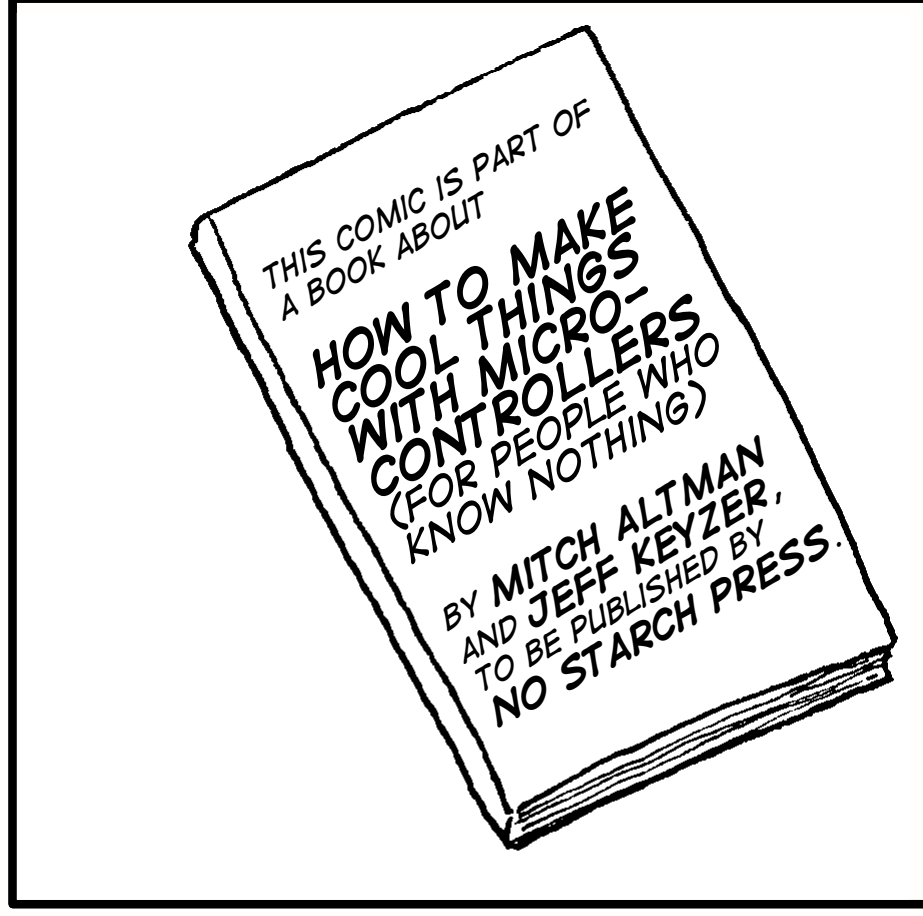
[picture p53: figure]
This comic is part of; a book about; How to Make Cool Things with Micro- controllers (For People Who Know Nothing) by Mitch Altman and Jeff Keyzer, to be published by No Starch Press

Translate it, use it, spread it, color it, teach with it!

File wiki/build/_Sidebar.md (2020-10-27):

# English Version
*  [Home](https://github.com/mommel/hs-lr-midi-schwurbler/wiki/home.en)
* [The MVP Version](https://github.com/mommel/hs-lr-midi-schwurbler/wiki/mvp.en)
* [The MVP Quickstart Guide](https://github.com/mommel/hs-lr-midi-schwurbler/wiki/quickstart.en)
* [Releases](https://github.com/mommel/hs-lr-midi-schwurbler/wiki/Releases)
* [Glossary](https://github.com/mommel/hs-lr-midi-schwurbler/wiki/glossary.en)
* [Helpful-External-Information](https://github.com/mommel/hs-lr-midi-schwurbler/wiki/helpful.en)
* [Repository Stucture](https://github.com/mommel/hs-lr-midi-schwurbler/wiki/Repostructure)

# German Version
* [Hauptseite](https://github.com/mommel/hs-lr-midi-schwurbler/wiki/home.de)
* [Die MVP Version](https://github.com/mommel/hs-lr-midi-schwurbler/wiki/mvp.de)
* [Die MVP Schnellstart Anleitung](https://github.com/mommel/hs-lr-midi-schwurbler/wiki/quickstart.de)
* [Veröffentlichungen](https://github.com/mommel/hs-lr-midi-schwurbler/wiki/Releases)
* [Glossar](https://github.com/mommel/hs-lr-midi-schwurbler/wiki/glossary.de)
* [Hilfreiche Information auf externen Seiten](https://github.com/mommel/hs-lr-midi-schwurbler/wiki/helpful.de)
* [Repository-Struktur](https://github.com/mommel/hs-lr-midi-schwurbler/wiki/Repostructure)

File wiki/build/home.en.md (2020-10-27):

# Welcome to the Schwurbler Wiki!

**The Schwurbler** - a self-made MIDI controller for Lightroom. Launched by Manuel, this HS-Community project provides you with everything you need to create your own custom-made MIDI controller for Lightroom. Schematics, board layouts, settings for Midi2LR. It's all open source and everyone is invited to contribute. Sign up for the HS-Slack channel #der-schwurbler and participate. 

A special thanks to the following members of the HS-Slack Channel #der-schwurbler for their active participation and time to make the MIDI-Controller for Lightroom a reality.

@Animefan
@chrismarquardt
@Christian T. Guenther
@iKnorry
@Mac ThreeZee,
@Markus-P
@mommel
@nicktaler
@TheBrainless
@vielpixel
@Wolfgang

***

**Happy Shooting** - the podcast about photography   
[https://happyshooting.de](https://happyshooting.de)
**Happy Shooting** - der Podcast zum Thema Fotografie   
[https://happyshooting.de](https://happyshooting.de)

**HS-Slack**   
https://happyshooting.de/der-hs-slack/

***
_[ > Deutsche Version](home.de.md)_

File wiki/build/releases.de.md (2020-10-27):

# Veröffentlichungen
September 13, 2020     
[The Schwurbler MVP v1.0.0](https://github.com/mommel/hs-lr-midi-schwurbler/releases/tag/v1.0.0)

***
_[ > English Version](releases.en.md)_

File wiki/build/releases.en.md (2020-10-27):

# Releases
September 13, 2020     
[The Schwurbler MVP v1.0.0](https://github.com/mommel/hs-lr-midi-schwurbler/releases/tag/v1.0.0)

***
_[ > Deutsche Version](releases.de.md)_

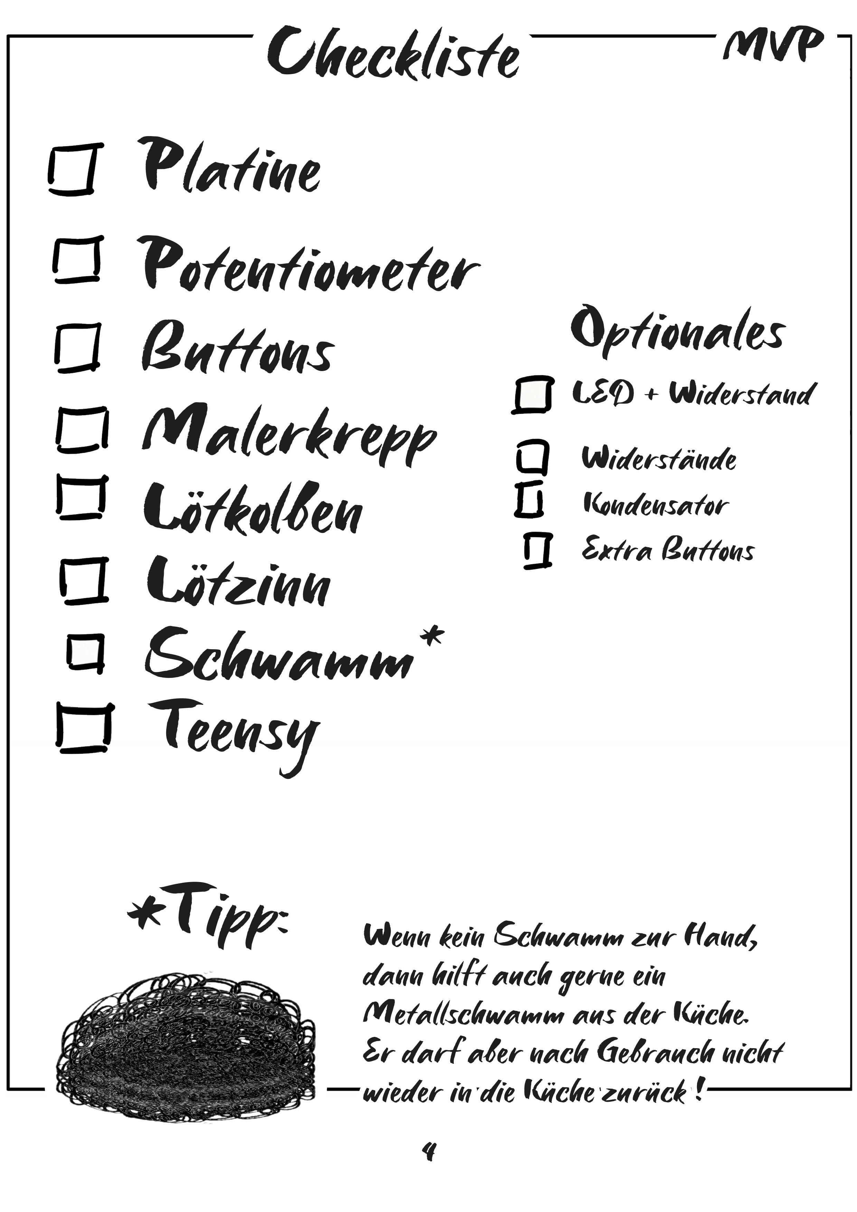
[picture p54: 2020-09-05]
quickstartguide/MVP/de/Der Schwurbler MVP - Schnellstart_Seite_4.jpg

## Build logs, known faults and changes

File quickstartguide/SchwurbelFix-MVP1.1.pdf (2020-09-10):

### DadasBoardzweikleineFehlerhathierdieLösung

# FixtheMVPRev1.1

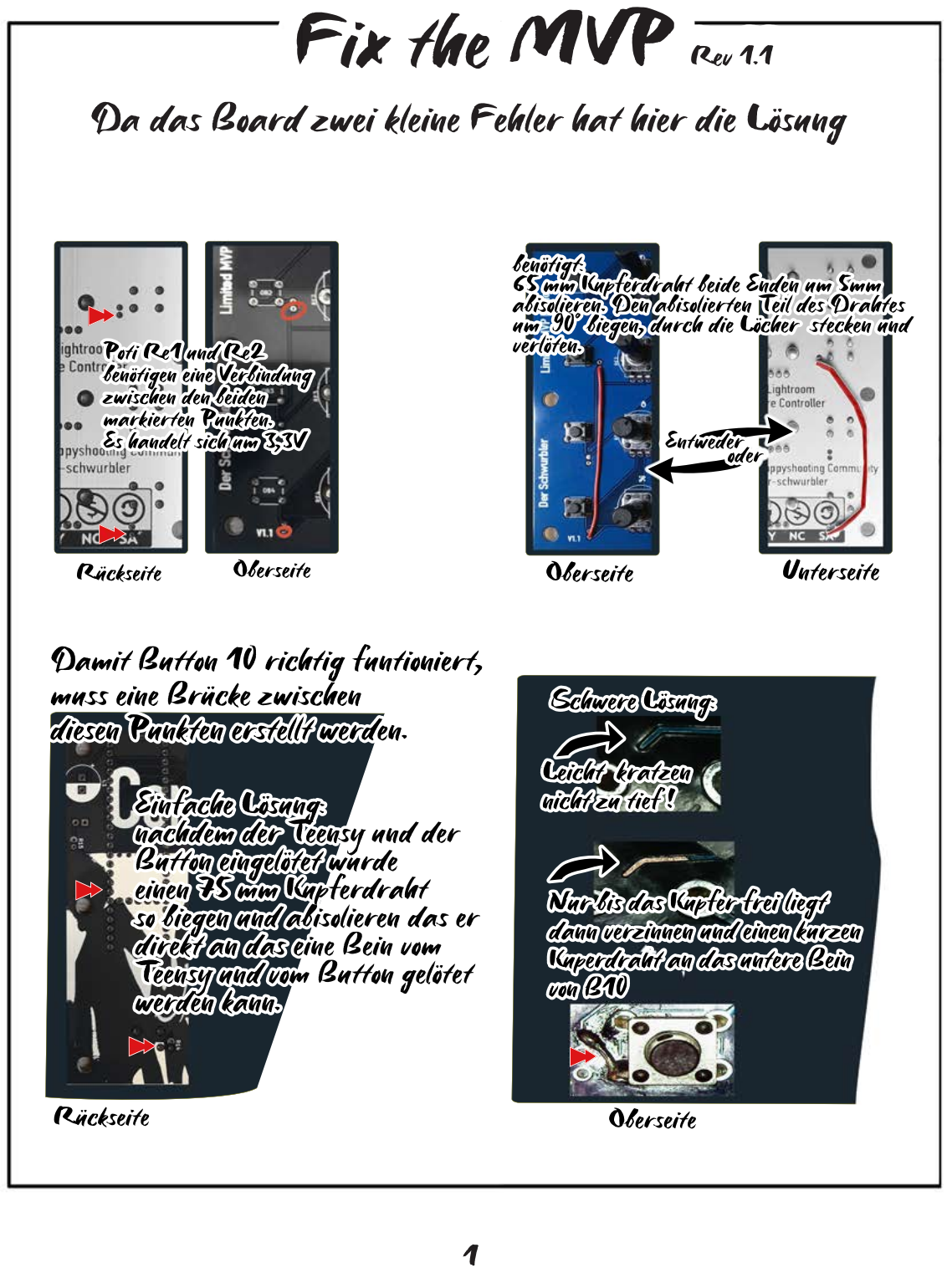
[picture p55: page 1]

1

EinfacheLösung:
nachdemderTeensyundder
Buttoneingelötetwurde
einen75mmKupferdraht
sobiegenundabisolierendaser direktandaseineBeinvom
TeensyundvomButtongelötet
werdenkann.
Rückseite | Oberseite NurbisdasKupferfreiliegt dannverzinnenundeinenkurzen KuperdrahtandasuntereBein vonB10

Leichtkratzen
nichtzutief!

SchwereLösung:

DamitButton10richtigfuntioniert, musseineBrückezwischen
diesenPunktenerstelltwerden.
Oberseite | Unterseite

Entwede
o
| rder

benötigt:
65mmKupferdrahtbeideEndenum5mm abisolieren.DenabisoliertenTeildesDrahtes um90°biegen,durchdieLöchersteckenund verlöten.

Rückseite Oberseite

PotiRe1undRe2
benötigeneineVerbindung
zwischendenbeiden
markiertenPunkten. Eshandeltsichum3,3V

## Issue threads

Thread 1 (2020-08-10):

Check if MIDI2LR already send back position values

mommel, 2020-08-10:
An Idea is to implement Rotary Encoder with value based lights. We are only able to set up those light if we know the value of the shown picture, and get an update to the board when the next picture is shown.

RESULT, yes it does

mommel, 2020-08-11:
It does support a backwards communication

Closed 2020-08-11.

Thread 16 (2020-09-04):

Illustrations for our Quickstartguide

mommel, 2020-09-04:
We have a lack on good illustrations for our Quickstartguide. The existing scribbles are more or less placeholders and need to be replaced with nice looking ones.
Here is page 2 as example
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

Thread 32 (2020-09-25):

Plexiglas or wood housing

mommel, 2020-09-25:
We somewhen decided it would be nice, to not only having a 3dPrinted case for der Schwurbler MVP. We wanted an additonal wood or plexiglas housing.

## Dimensions
You can look up the dimensions here
* [3d Case](https://github.com/mommel/hs-lr-midi-schwurbler/blob/master/3d-prints/MVP/Topcase.stl)
* [Etching Print for A4](https://github.com/mommel/hs-lr-midi-schwurbler/blob/master/pcb/MVP/Echting/Etchprint.pdf)
* [Kicad PCB Files](https://github.com/mommel/hs-lr-midi-schwurbler/blob/master/kicad/MVP/the_mvp_v1.2.kicad_pcb)

## What like to have:
* All files to create a housing on our own.
* The housing should fit.
* (Optional) It would be nice to have a render or photo of the case

## How to contribute:
* Create a fork of the project, add your files and create a pull request

## Hacktoberfest
* At present your support of our project might give you more than the good feeling to do opensource development. It's [Hacktoberfst](https://hacktoberfest.digitalocean.com/)

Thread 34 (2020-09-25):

Scheme and PCB for the Schwirbler360

mommel, 2020-09-25:
Similar to the MVP version of the code it would be nice to have a version that supports rotary encoder instead of the potentiometers.

## What we want
* Working Layout/Scheme for a 1:1 swap of the MVP versions potentiometers
* Please check the routes

## How to contribute:
Create a fork of the project, add your files and create a pull request

## Hacktoberfest
At present your support of our project might give you more than the good feeling to do opensource development. It's Hacktoberfst

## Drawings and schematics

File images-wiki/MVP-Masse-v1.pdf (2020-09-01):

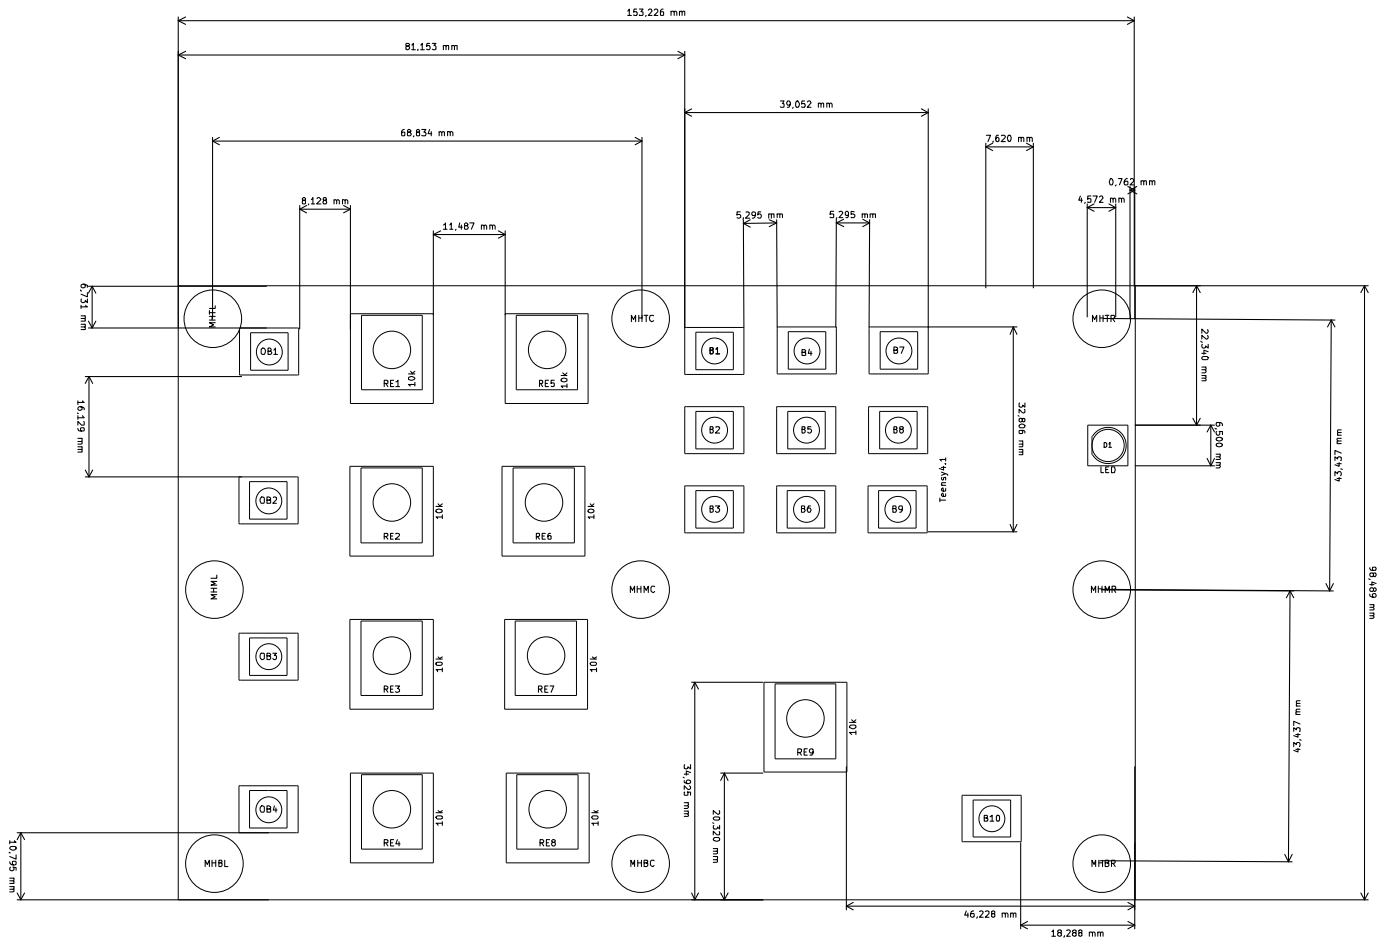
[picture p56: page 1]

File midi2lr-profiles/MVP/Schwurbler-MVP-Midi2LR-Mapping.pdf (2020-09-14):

# Der Schwurer MVP

## MIDI2LR Mapping

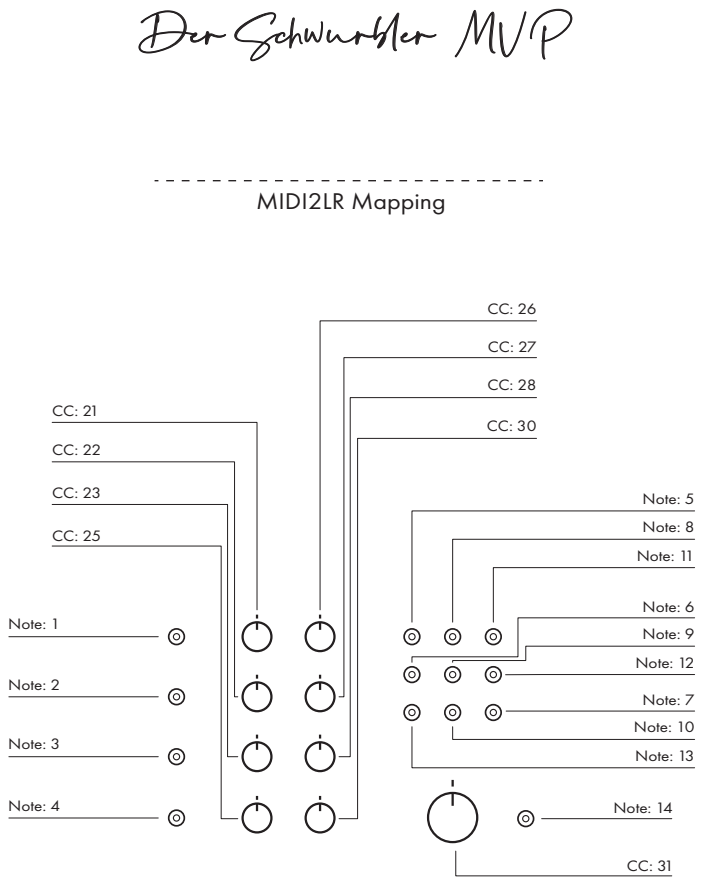
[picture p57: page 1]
Note: 1; Note: 2; Note: 3; Note: 4; Note: 14; Note: 5; Note: 8; Note: 11; Note: 6; Note: 9; Note: 12; Note: 7; Note: 10; Note: 13

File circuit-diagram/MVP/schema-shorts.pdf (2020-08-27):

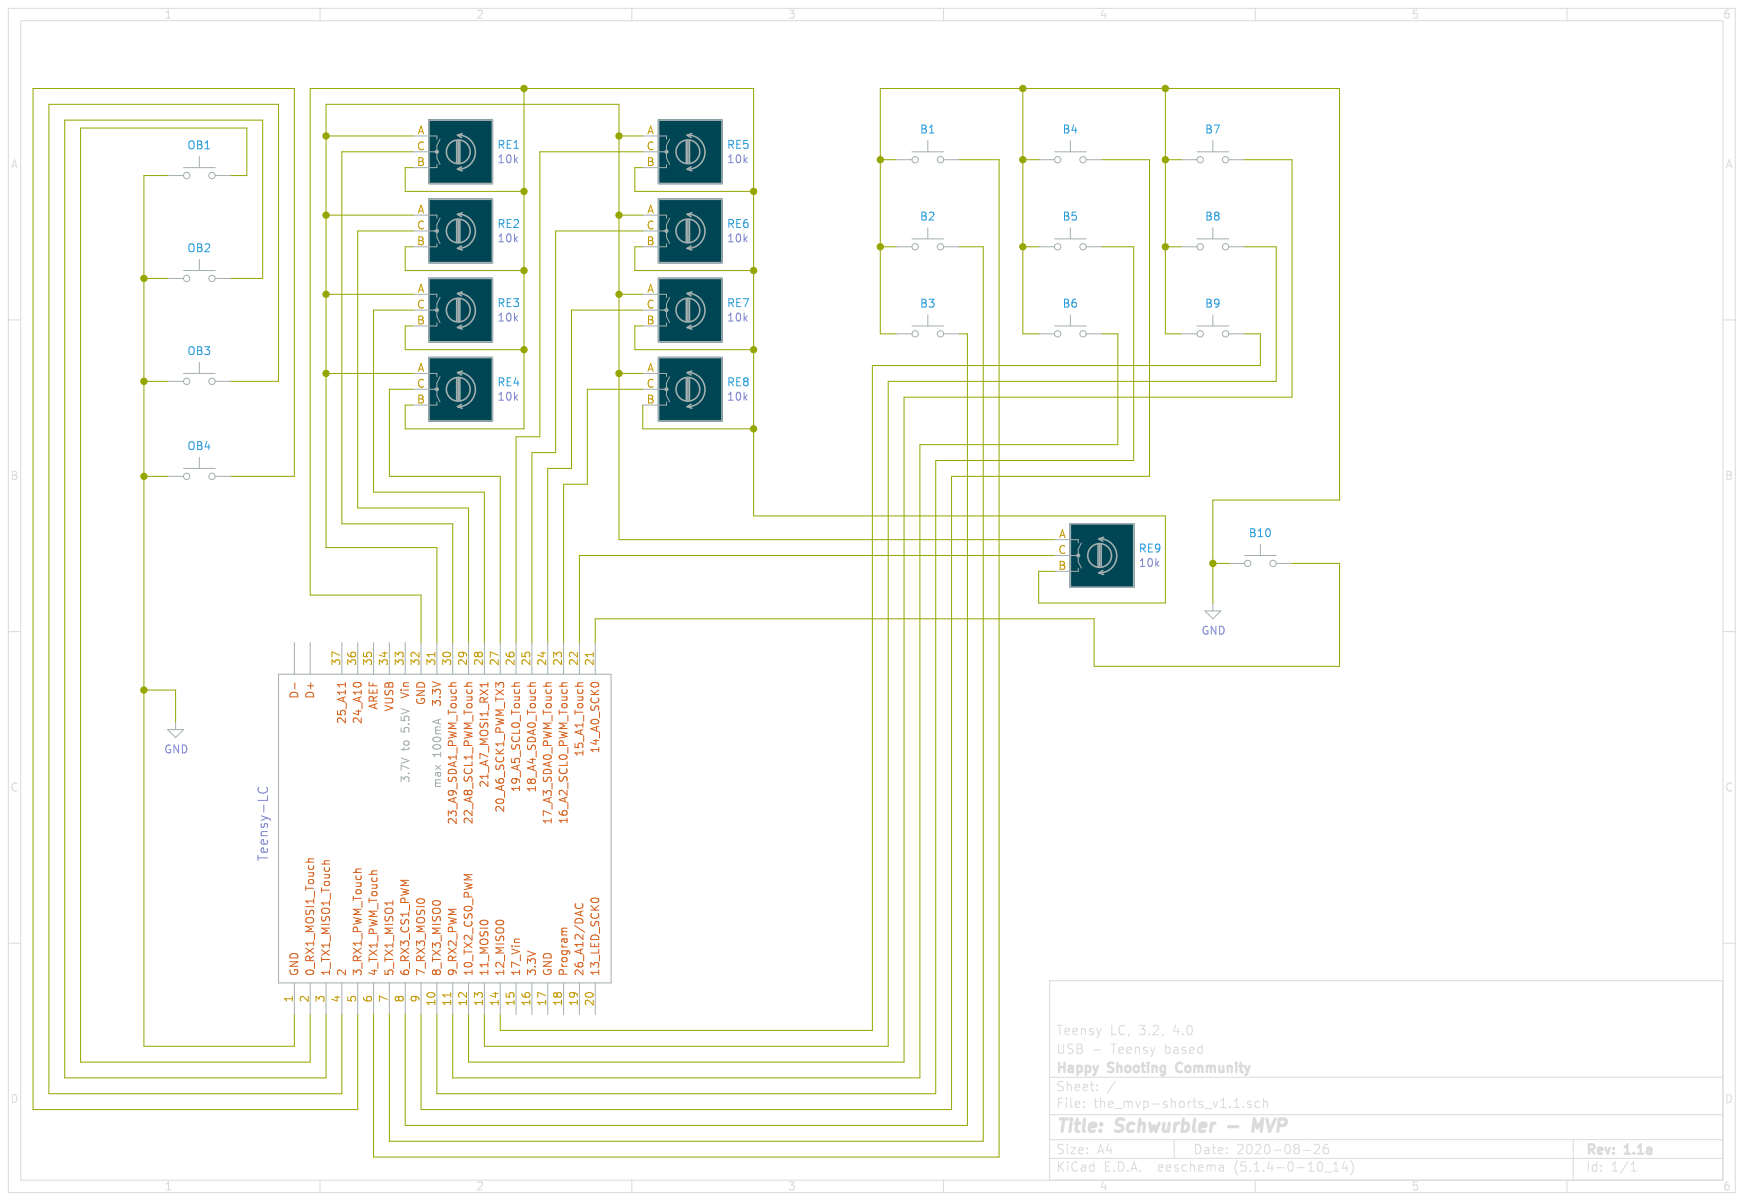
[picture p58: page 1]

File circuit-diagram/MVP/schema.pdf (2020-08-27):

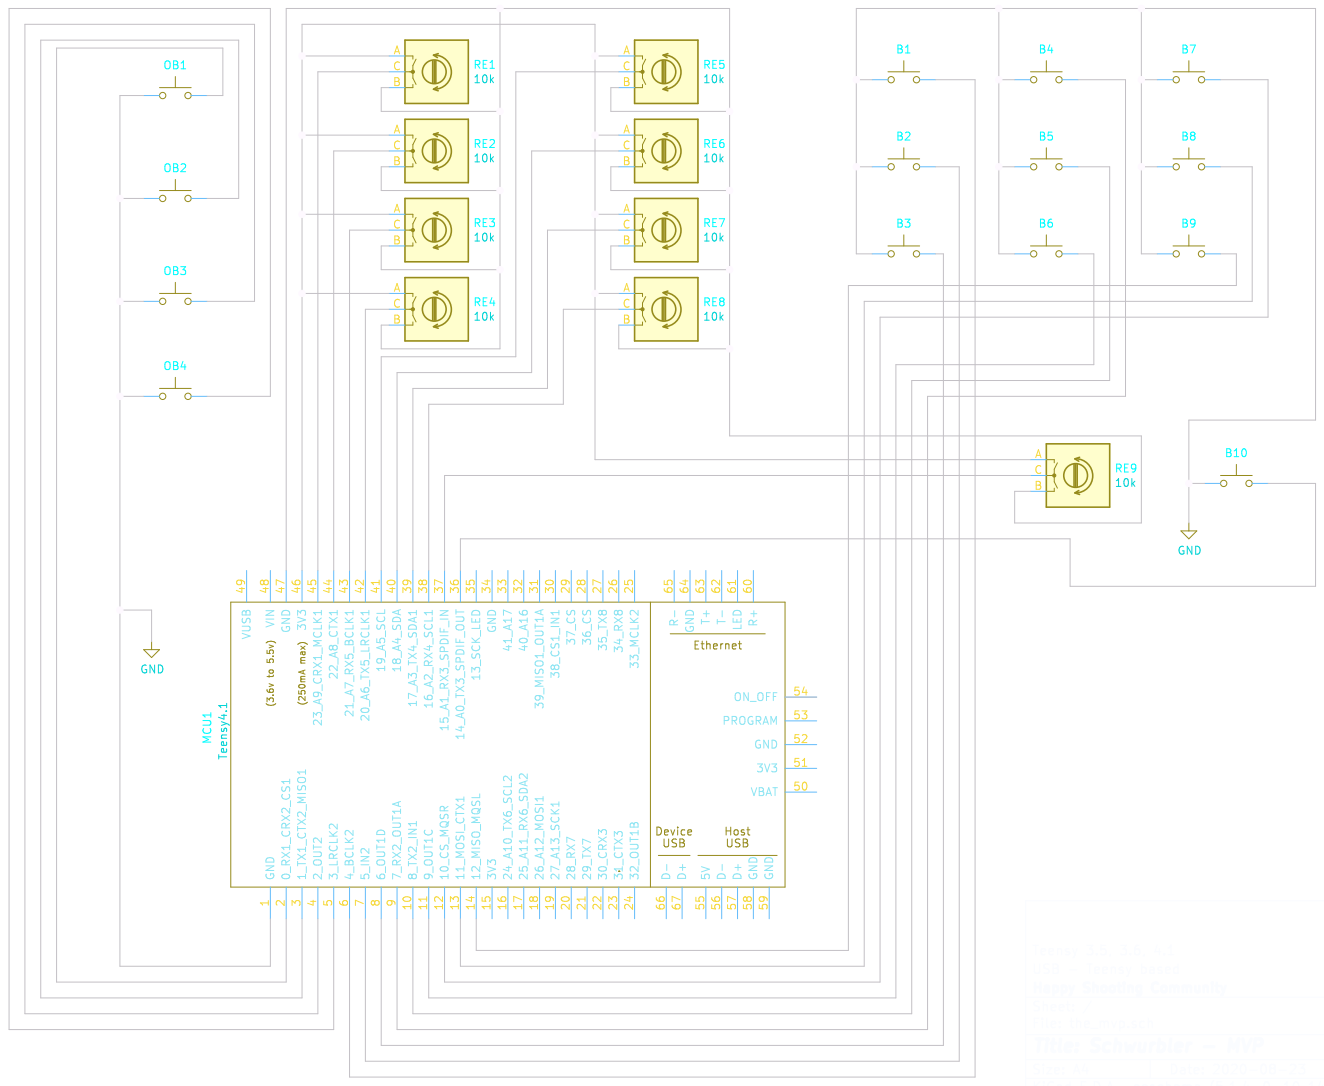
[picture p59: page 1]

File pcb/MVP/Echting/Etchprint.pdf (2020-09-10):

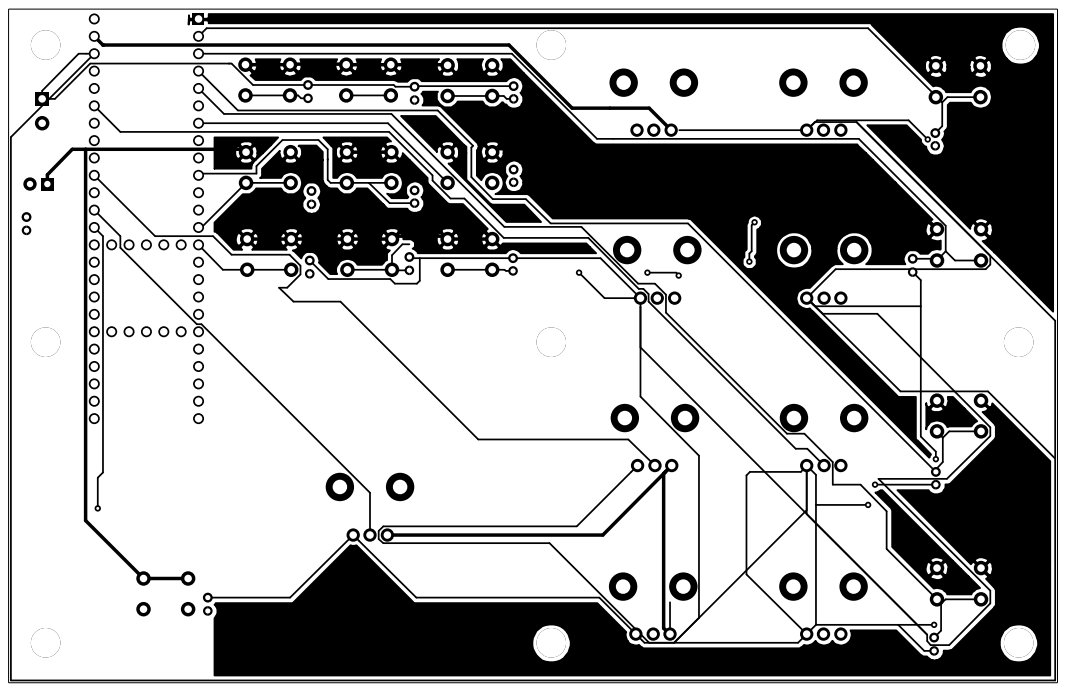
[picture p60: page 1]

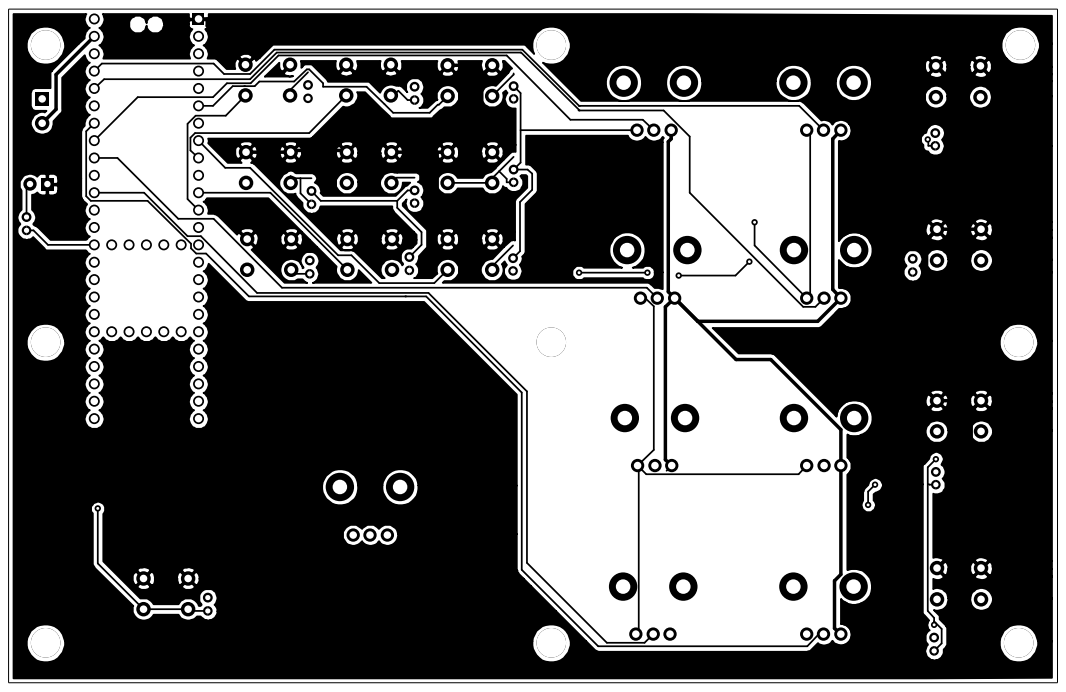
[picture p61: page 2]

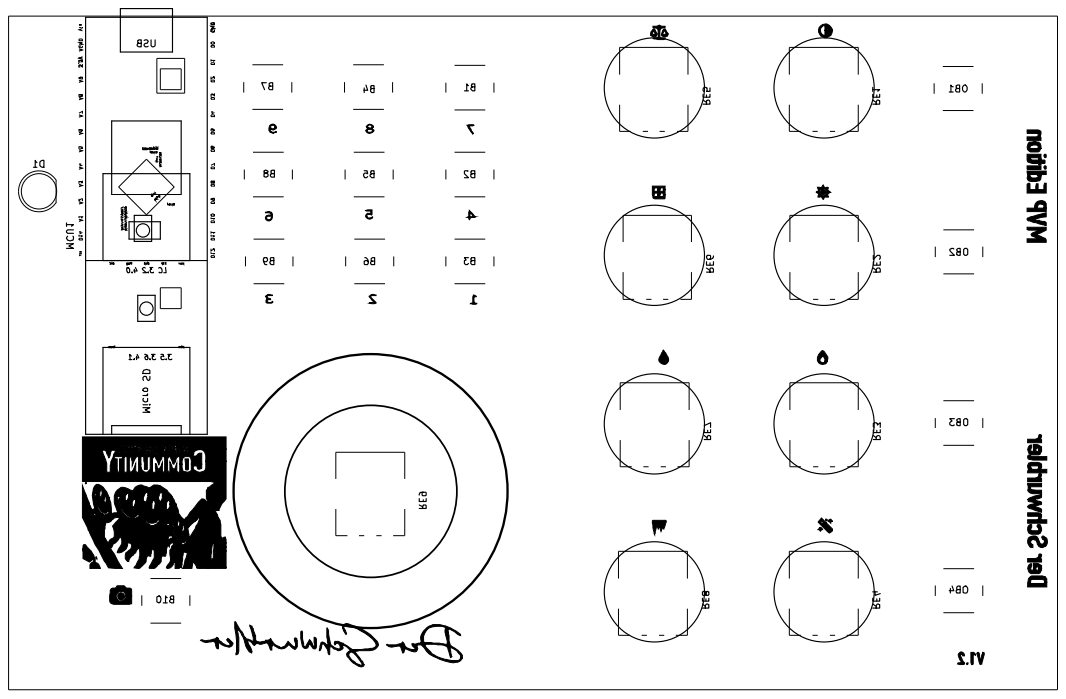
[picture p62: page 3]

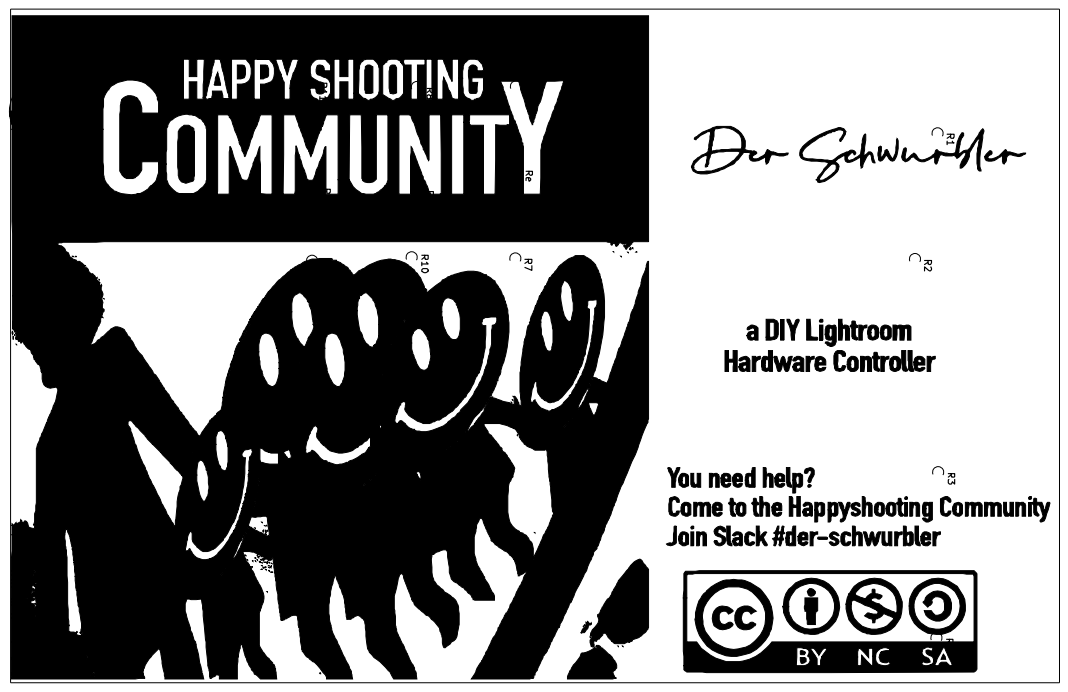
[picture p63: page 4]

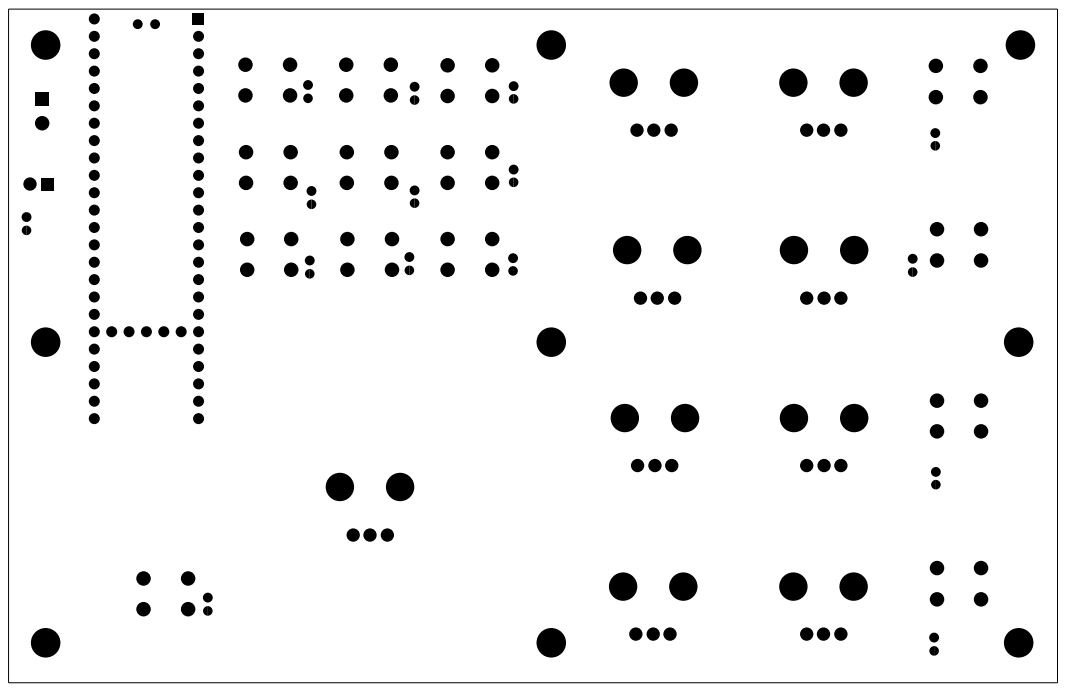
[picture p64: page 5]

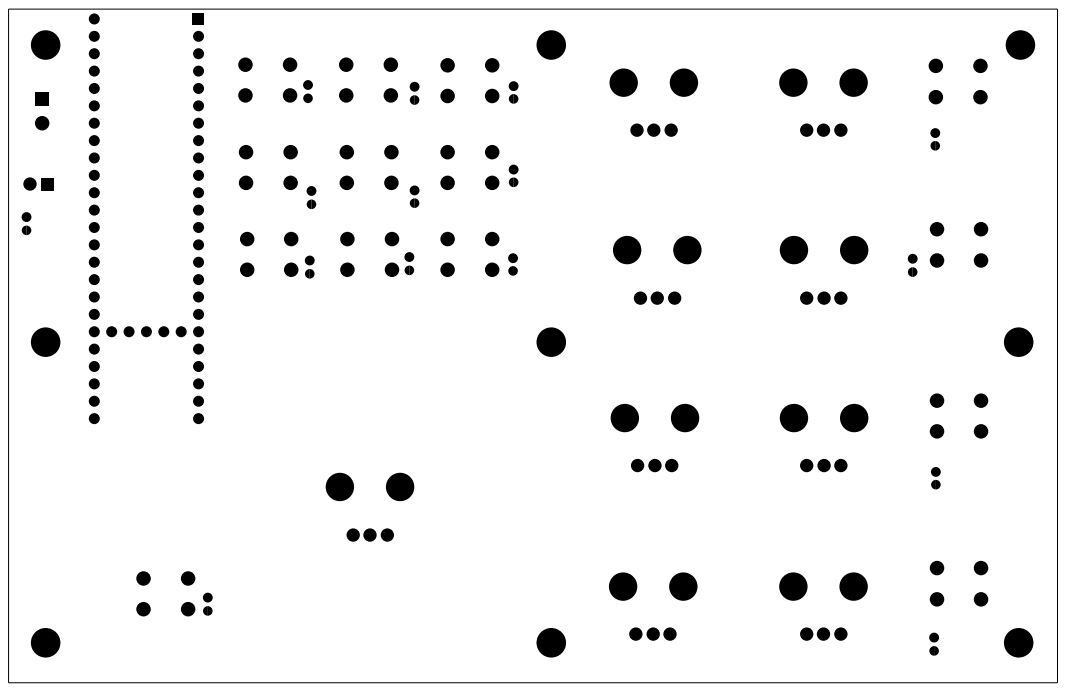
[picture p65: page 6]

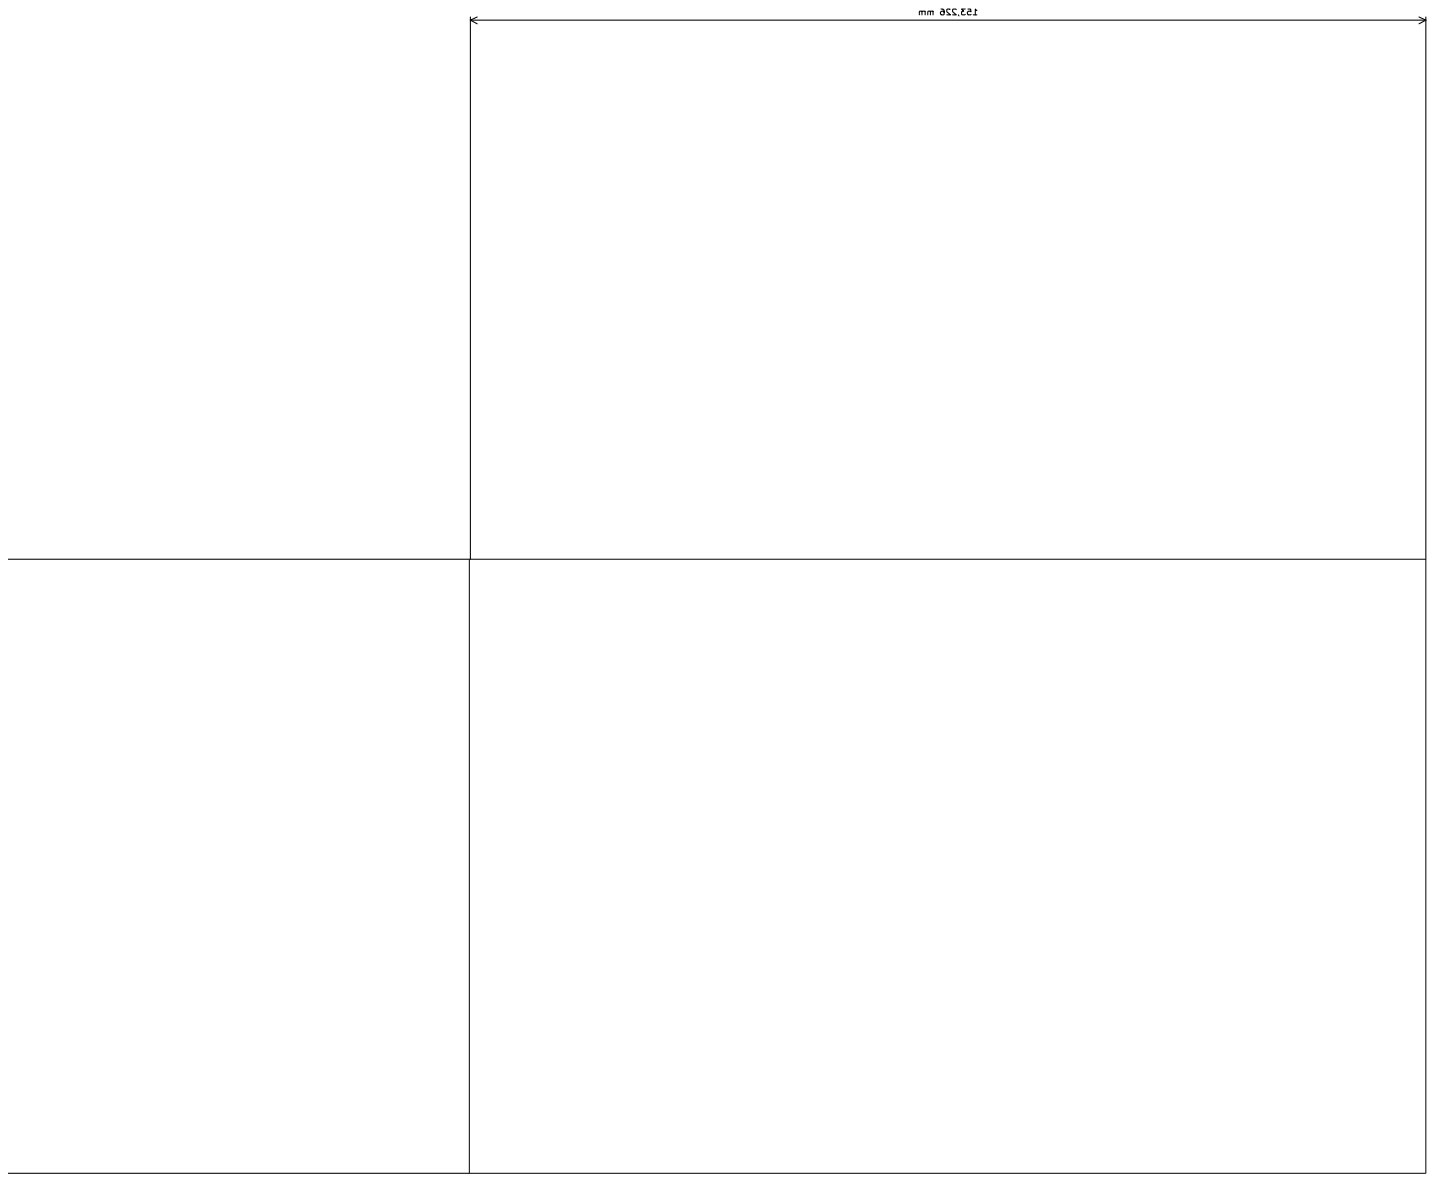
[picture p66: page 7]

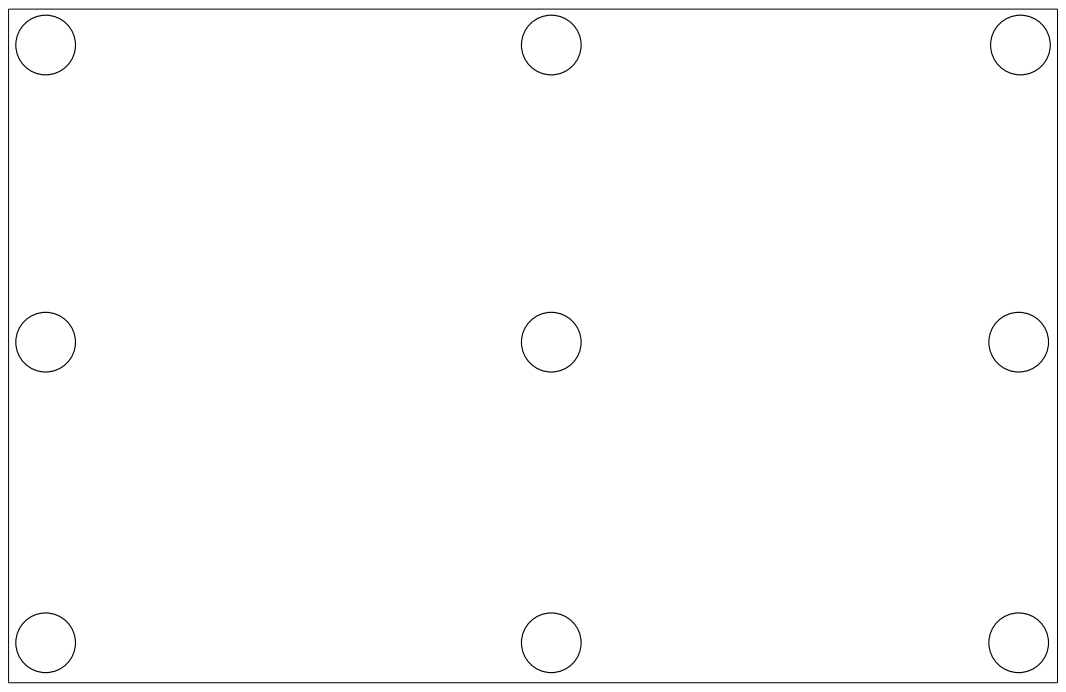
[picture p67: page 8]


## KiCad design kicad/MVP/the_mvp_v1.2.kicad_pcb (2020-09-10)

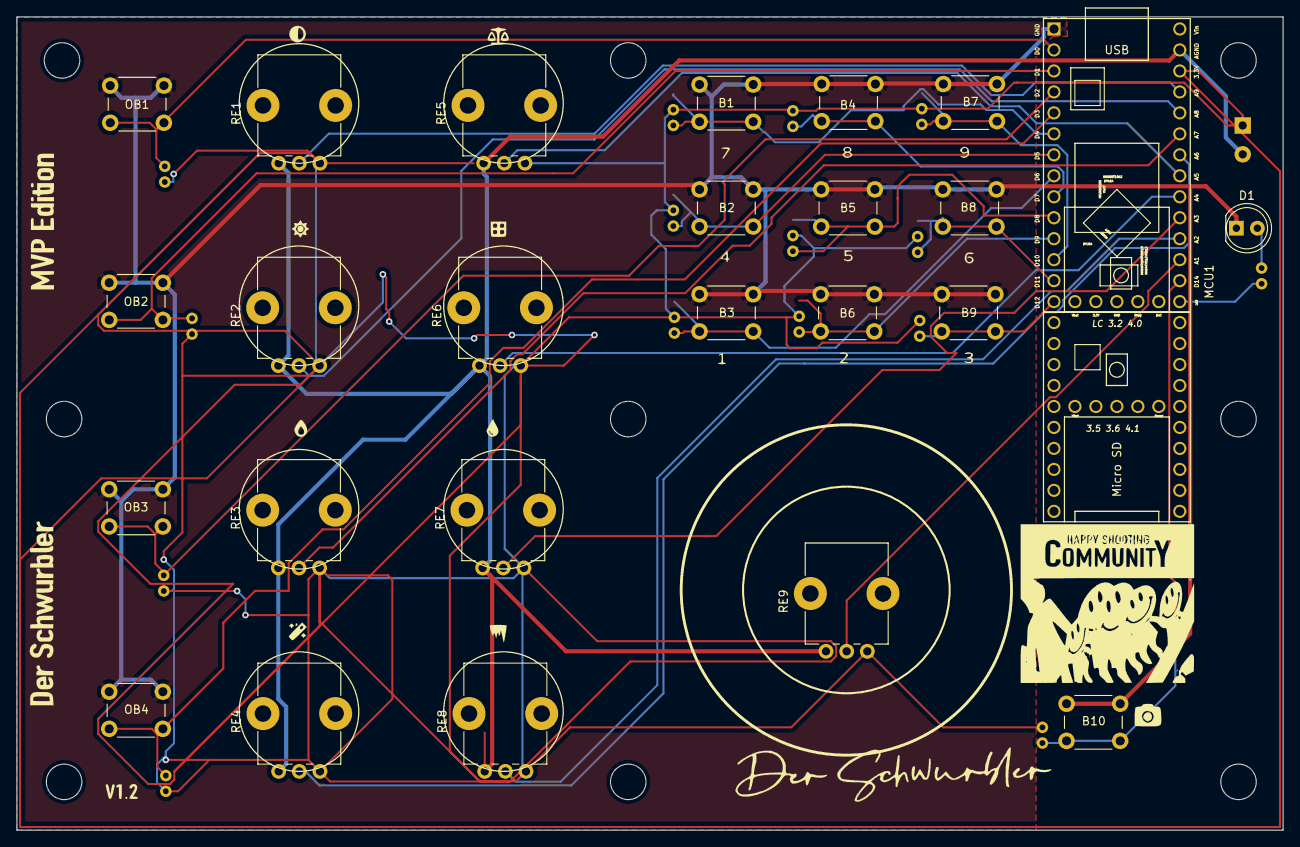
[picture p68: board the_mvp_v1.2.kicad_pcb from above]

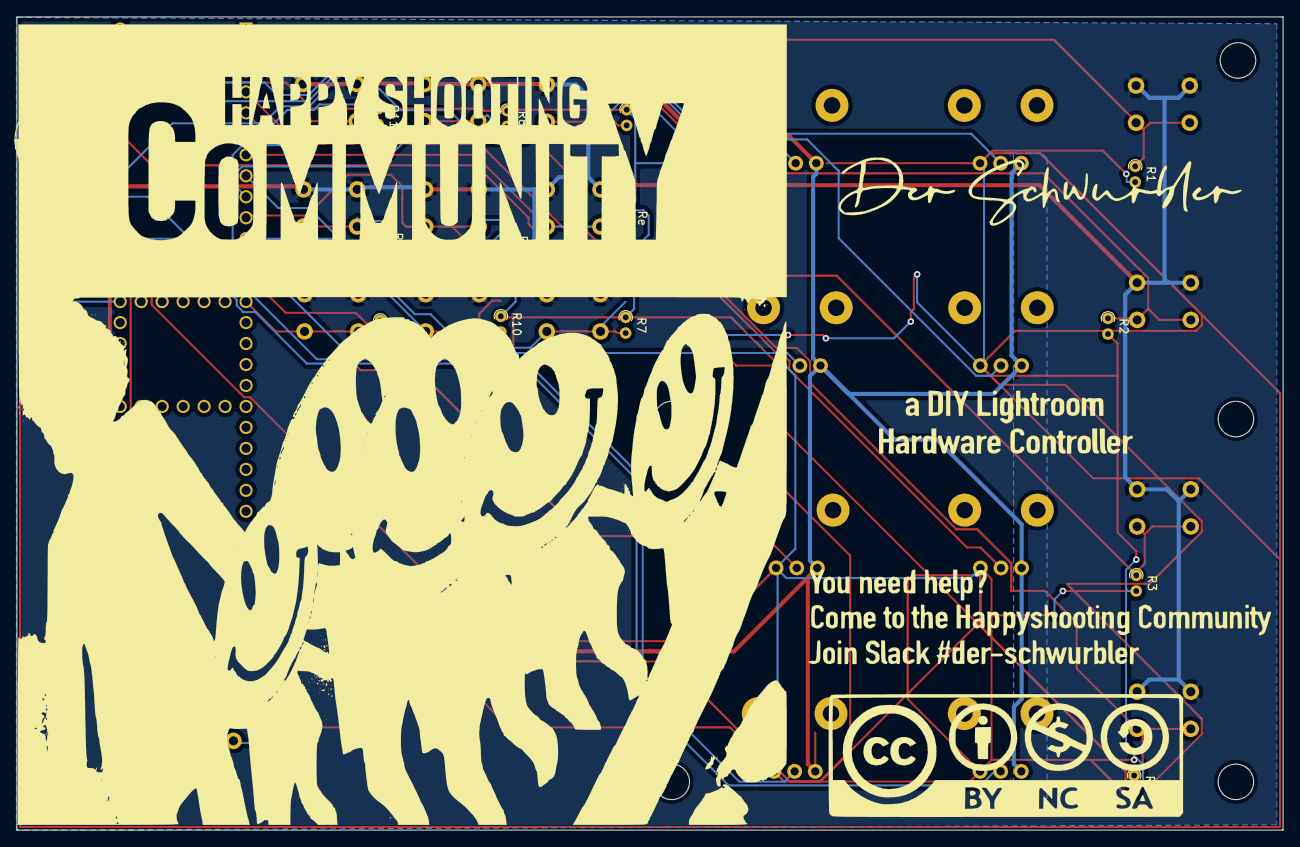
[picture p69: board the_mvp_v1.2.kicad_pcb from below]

Board: 2 copper layers, 153.4 x 98.5 mm, 50 parts (16 on the bottom side), 28 nets.

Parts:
B1, B2, B3, B4, B5, B6, B7, B8, B9, B10: monumentary switch Buttons; SW_PUSH_6mm_H5mm
C1: optional; CP_Radial_D10.0mm_P3.50mm
D1: LED; LED_D5.0mm
MCU1: Teensy4.1; Teensy_Schwurbler_Unified_Footprint
MHBC: MountingHole_4.3mm_M4
MHBL: MountingHole_4.3mm_M4
MHBR: MountingHole_4.3mm_M4
MHMC: MountingHole_4.3mm_M4
MHML: MountingHole_4.3mm_M4
MHMR: MountingHole_4.3mm_M4
MHTC: MountingHole_4.3mm_M4
MHTL: MountingHole_4.3mm_M4
MHTR: MountingHole_4.3mm_M4
OB1: optional monumentary switch Buttons; SW_PUSH_6mm_H5mm
OB2, OB3, OB4: monumentary switch Button; SW_PUSH_6mm_H5mm
R1, R2, R3, R4, R5, R7, R8, R9, R10, R11, R12, R13, R14: 10kOhm (optional); R_Axial_DIN0204_L3.6mm_D1.6mm_P1.90mm_Vertical
R15: 470Ohm (optional); R_Axial_DIN0204_L3.6mm_D1.6mm_P1.90mm_Vertical
RE1, RE2, RE3, RE4, RE5, RE6, RE7, RE8, RE9: 10k; Potentiometer_Alps_RK09K_Single_Vertical
Re: 10kOhm (optional); R_Axial_DIN0204_L3.6mm_D1.6mm_P1.90mm_Vertical

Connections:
GND: B1.1, B2.1, B3.1, B4.1, B5.1, B6.1, B7.1, B8.1, B9.1, B10.1, D1.1, MCU1.1, OB1.1, OB2.1, OB3.1, OB4.1
unnamed: B1.2, MCU1.6, R5.2
unnamed: B2.2, MCU1.7, Re.2
unnamed: B3.2, MCU1.8, R7.2
unnamed: B4.2, MCU1.9, R8.2
unnamed: B5.2, MCU1.10, R9.2
unnamed: B6.2, MCU1.11, R10.2
unnamed: B7.2, MCU1.12, R11.2
unnamed: B8.2, MCU1.13, R12.2
unnamed: B9.2, MCU1.14, R13.2
unnamed: B10.2, MCU1.36, R14.2
unnamed: C1.1, MCU1.46, R1.2, R2.2, R3.2, R4.2, R5.1, R7.1, R8.1, R9.1, R10.1, R11.1, R12.1, R13.1, R14.1, RE1.1, RE2.1, RE3.1, RE4.1, RE5.1, RE6.1, RE7.1, RE8.1, RE9.1, Re.1
unnamed: C1.2, MCU1.47, RE1.3, RE2.3, RE3.3, RE4.3, RE5.3, RE6.3, RE7.3, RE8.3, RE9.3
unnamed: D1.2, R15.1
unnamed: MCU1.2, OB1.2, R1.1
unnamed: MCU1.3, OB2.2, R2.1
unnamed: MCU1.4, OB3.2, R3.1
unnamed: MCU1.5, OB4.2, R4.1
unnamed: MCU1.35, R15.2
unnamed: MCU1.37, RE9.2
unnamed: MCU1.38, RE8.2
unnamed: MCU1.39, RE7.2
unnamed: MCU1.40, RE6.2
unnamed: MCU1.41, RE5.2
unnamed: MCU1.42, RE4.2
unnamed: MCU1.43, RE3.2
unnamed: MCU1.44, RE2.2
unnamed: MCU1.45, RE1.2

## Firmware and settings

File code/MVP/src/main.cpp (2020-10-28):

/******************************************************************************
 *            :+==+                                           -:              *
 *       -+#=+-  -=-    -*                             -@:   +W+              *
 *    -=#+-     -=-     =*         =:                 -@:   =*@-              *
 *  -#*-               -#:   :*    =--:               +#  -#-*#               *
 * -#:           :=@#=+:@+#= =*=@--= #+ ++     *W@#*++#==*@- =* *@: -=W@#*++*-*
 *  :=====**+::=*-+#:==+W* =-*@+-@#: #==-*#+*=**@-    :-:W=  #+-@===:*@-      *
 *          :#::#-     :=   -                  --      :W*   #:      --       *
 *        -=+ -=+                                            -:               *
 *       -=-+#+                                                               *
 *        --                                                                  *
 *****************************************************************************/
#include "main.h"
/******************************************************************************
 *                                                                            *
 * Version: 1 0 0                                                             *
 * Date:    Sep 25 2020                                                       *
 * Name:    Manuel Braun                                                      *
 * Email:   mommel@gmx de                                                     *
 *                                                                            *
 *****************************************************************************/
/******************************************************************************
 *                                                                            *
 *   This program is free software; you can redistribute it and/or modify     *
 *   it under the terms of the (CC BY-NC-SA 4 0)                              *
 *   Creative Commons Attribution-NonCommercial-ShareAlike 4 0 International  *
 *   as published by Creative Commons Corporation; either version 4 of the    *
 *   License, or (at your option) any later version                           *
 *                                                                            *
 *****************************************************************************/
/******************************************************************************
 * THE SOFTWARE IS PROVIDED "AS IS", WITHOUT WARRANTY OF ANY KIND,            *
 * EXPRESS OR IMPLIED, INCLUDING BUT NOT LIMITED TO THE WARRANTIES OF         *
 * MERCHANTABILITY, FITNESS FOR A PARTICULAR PURPOSE AND NONINFRINGEMENT IN   *
 * NO EVENT SHALL THE AUTHORS OR COPYRIGHT HOLDERS BE LIABLE FOR ANY CLAIM,   *
 * DAMAGES OR OTHER LIABILITY, WHETHER IN AN ACTION OF CONTRACT, TORT OR      *
 * OTHERWISE, ARISING FROM, OUT OF OR IN CONNECTION WITH THE SOFTWARE OR THE  *
 * USE OR OTHER DEALINGS IN THE SOFTWARE                                      *
 *****************************************************************************/
#define arrayCount(x) (sizeof(x) / sizeof(x)[0])

MIDI_CREATE_INSTANCE(HardwareSerial, Serial2, MIDI);
/******************************************************************************
 * General Midi Configurations                                                *
 *****************************************************************************/
const int midiChannel = 7;
const int amountOfPotiControllerInputs = 9;
const int amountOfDigitalButtonController = 14;
const int cable = 0;
const int ON_VELOCITY = 99;
const int BOUNCE_TIME = 7;
const bool toggled = true;

/******************************************************************************
 * Controller - Pin Mapping                                                   *
 *****************************************************************************/
const int potiControllerPin[amountOfPotiControllerInputs] = {A9, A8, A7, A6, A5,
                                                             A4, A3, A2, A1};
const int buttonControllerPin[amountOfDigitalButtonController] = {
    0, 1, 2, 3, 4, 5, 6, 7, 8, 9, 10, 11, 12, 14};
const int controlNumbersAnalog[amountOfPotiControllerInputs] = {
    21, 22, 23, 25, 26, 27, 28, 30, 31};
const int controlNumbersDigital[amountOfDigitalButtonController] = {
    1, 2, 3, 4, 5, 6, 7, 8, 9, 10, 11, 12, 13, 14};

byte potiData[amountOfPotiControllerInputs];
byte potiDataLag[amountOfPotiControllerInputs];


ResponsiveAnalogRead analogPotiController[]{
    {potiControllerPin[0], true}, {potiControllerPin[1], true},
    {potiControllerPin[2], true}, {potiControllerPin[3], true},
    {potiControllerPin[4], true}, {potiControllerPin[5], true},
    {potiControllerPin[6], true}, {potiControllerPin[7], true},
    {potiControllerPin[8], true}};

Bounce digitalButtonController[] = {
    Bounce(buttonControllerPin[0], BOUNCE_TIME),
    Bounce(buttonControllerPin[1], BOUNCE_TIME),
    Bounce(buttonControllerPin[2], BOUNCE_TIME),
    Bounce(buttonControllerPin[3], BOUNCE_TIME),
    Bounce(buttonControllerPin[4], BOUNCE_TIME),
    Bounce(buttonControllerPin[5], BOUNCE_TIME),
    Bounce(buttonControllerPin[6], BOUNCE_TIME),
    Bounce(buttonControllerPin[7], BOUNCE_TIME),
    Bounce(buttonControllerPin[8], BOUNCE_TIME),
    Bounce(buttonControllerPin[9], BOUNCE_TIME),
    Bounce(buttonControllerPin[10], BOUNCE_TIME),
    Bounce(buttonControllerPin[11], BOUNCE_TIME),
    Bounce(buttonControllerPin[12], BOUNCE_TIME),
    Bounce(buttonControllerPin[13], BOUNCE_TIME)};

void sendMidiTrigger(int inControlNumber, bool isActive, int sendChannelID) {
#ifdef LEDPIN
  digitalWrite(LEDPIN, (isActive ? LOW : HIGH));
#endif  // LEDPIN
  if (isActive) {
    usbMIDI.sendNoteOn(inControlNumber, ON_VELOCITY, sendChannelID);
  } else {
    usbMIDI.sendNoteOff(inControlNumber, 0, sendChannelID);
  }
}

void sendMidiValueChange(int inControlNumber, byte controllerValue,
                         int sendChannelID) {
#ifdef LEDPIN
  digitalWrite(LEDPIN, LOW);
#endif  // LEDPIN
  usbMIDI.sendControlChange(inControlNumber, controllerValue, sendChannelID);
}

void getPotiData() {
  for (int potiControllerID = 0;
       potiControllerID < amountOfPotiControllerInputs; potiControllerID++) {
    analogPotiController[potiControllerID].update();
    if (analogPotiController[potiControllerID].hasChanged()) {
      potiData[potiControllerID] =
          analogPotiController[potiControllerID].getValue() >> 3;
      if (potiData[potiControllerID] != potiDataLag[potiControllerID]) {
        potiDataLag[potiControllerID] = potiData[potiControllerID];
        sendMidiValueChange(controlNumbersAnalog[potiControllerID],
                            potiData[potiControllerID], midiChannel);
      } else {
#ifdef LEDPIN
        digitalWrite(LEDPIN, HIGH);
#endif  // LEDPIN
      }
    }
  }
}

void getButtonData() {
  for (int buttonControllerId = 0;
       buttonControllerId < amountOfDigitalButtonController;
       buttonControllerId++) {
    digitalButtonController[buttonControllerId].update();
    if (digitalButtonController[buttonControllerId]
            .fallingEdge() ||  // On Button push > FallingEdge
                               // Pin pulled to gnd
        digitalButtonController[buttonControllerId]
            .risingEdge()) {  // On Button release > RisingEdge
                              // Pin rising up again thru Internal pullup
      sendMidiTrigger(
          controlNumbersDigital[buttonControllerId],
          (digitalButtonController[buttonControllerId].fallingEdge() &&
           !digitalButtonController[buttonControllerId].risingEdge()),
          midiChannel);
    }
  }
}

// cppcheck-suppress unusedFunction // Function is used by arduino
void setup() {
  MIDI.begin(midiChannel);
  MIDI.turnThruOff();

  while (arrayCount(potiControllerPin) != amountOfPotiControllerInputs ||
         arrayCount(controlNumbersAnalog) != amountOfPotiControllerInputs ||
         arrayCount(buttonControllerPin) != amountOfDigitalButtonController ||
         arrayCount(controlNumbersDigital) != amountOfDigitalButtonController) {
    if (!Serial) {
      Serial.begin(9600);
    }
    Serial.println("Error Controller Pin Values Amount mismatch");
    delay(2000);
  }

  for (int digitalControllerID = 0;
       digitalControllerID < amountOfDigitalButtonController;
       digitalControllerID++) {
    pinMode(buttonControllerPin[digitalControllerID], INPUT_PULLUP);
  }

#ifdef LEDPIN
  pinMode(LEDPIN, OUTPUT);
#endif  // LEDPIN
}

// cppcheck-suppress unusedFunction // Function is used by arduino
void loop() {
  getPotiData();
  getButtonData();
  while (usbMIDI.read()) {
  }  // ignore incoming messages
}

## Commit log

2020-08-01 First glympse of a board for Teensy 3.6
    [usb-teensy3.6.fzz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]
2020-08-01 modifies the soilmask and printing to underline the community thing a bit more
    adds scheme to readme and howto order
    As hint: I know you can easier order if the gerber files are already uploaded to a manufacturer, but as this is combine to the Affiliate Systems I decided not to.
    [usb-teensy3.6_kicad-B_Cu.gbr, usb-teensy3.6_kicad-B_Mask.gbr, usb-teensy3.6_kicad-B_Paste.gbr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]
2020-08-04 changed help wording on pcb and scheme
    [usb-teensy3.6_kicad.kicad_pcb, usb-teensy3.6_kicad.sch]
2020-08-04 mod render without parts
    [usb-teensy3.6_kicad.kicad_pcb]
2020-08-04 mods gerber files and rendering with parts
    [usb-teensy3.6_kicad-B_Cu.gbr, usb-teensy3.6_kicad-B_Mask.gbr, usb-teensy3.6_kicad-B_Paste.gbr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]
2020-08-04 update pcb with alternative layout
    [usb-teensy3.6_kicad.kicad_pcb, usb-teensy3.6_kicad.sch]
2020-08-04 update Gerber
    [usb-teensy3.6_kicad-B_Cu.gbr, usb-teensy3.6_kicad-B_Mask.gbr, usb-teensy3.6_kicad-B_Paste.gbr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]
2020-08-10 Adds code for the Teensy2.0
2020-08-10 adds unix helper scipt
    The helper script has following functions:
    new) create a new branch with a skeleton folder structure for a new board
    pack) packs all files matching to the selected board together in one archive
    // If you are not so familar with git
    branch) switch the branch
    add2git) add files to to git
    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
2020-08-11 adds missing functions (pack, pull) to board.sh
2020-08-13 mods teensy3.6 untested example code to be compilable
    adds arrayCount function
    fixes quotes for Serial string
    homogenizes variable name for midi Channel
2020-08-19 adds soldering comics and adds their LICENSE
2020-08-22 adds new board skeleton for a teensy-based usb-teensy_LC_41-theMVP
2020-08-23 adds pcb, gerber, schema, etching
    [the_mvp-B_Cu.gbr, the_mvp-B_Mask.gbr, the_mvp-B_Paste.gbr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]
2020-08-26 adds Code for Teensy 32 bit versions
2020-08-26 adds versioning to kicad filenames
    [the_mvp-shorts_v1.0.sch, the_mvp_v1.0.kicad_pcb, the_mvp_v1.0.sch]
2020-08-26 copies 1.0 schema to 1.1
    [the_mvp-shorts_v1.1.sch, the_mvp_v1.1.sch]
2020-08-26 moving v1.0 to subfolder
    [the_mvp-shorts_v1.0.sch, the_mvp-shorts_v1.1.sch, the_mvp_v1.0.kicad_pcb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]
2020-08-27 adds complete new version of the MVP
    [the_mvp-B_Cu.gbr, the_mvp-B_Mask.gbr, the_mvp-B_Paste.gbr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]
2020-09-01 updates Bom
2020-09-05 adds Quickstartguide de as images and pdf
2020-09-05 adds src file of quickstartguide de and gitattr for psd
2020-09-10 adds de version of fix guide
2020-09-10 modifes pcb to fix issues from v1.1
    [the_mvp-shorts_v1.1.sch, the_mvp-shorts_v1.2.sch, the_mvp_v1.1-B_Cu.dxf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]
2020-09-13 moving and removing everything
    [the_mvp-shorts_v1.0.sch, the_mvp-shorts_v1.2.sch, the_mvp_v1.0.kicad_pcb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]
2020-09-14 Bilder für den images-wiki Folder
    Ich hab hier noch das neue 3-d Gehäuse und ein paar bessere Bilder fürs Wiki.
2020-10-10 remove board.sh as is unused anyways
